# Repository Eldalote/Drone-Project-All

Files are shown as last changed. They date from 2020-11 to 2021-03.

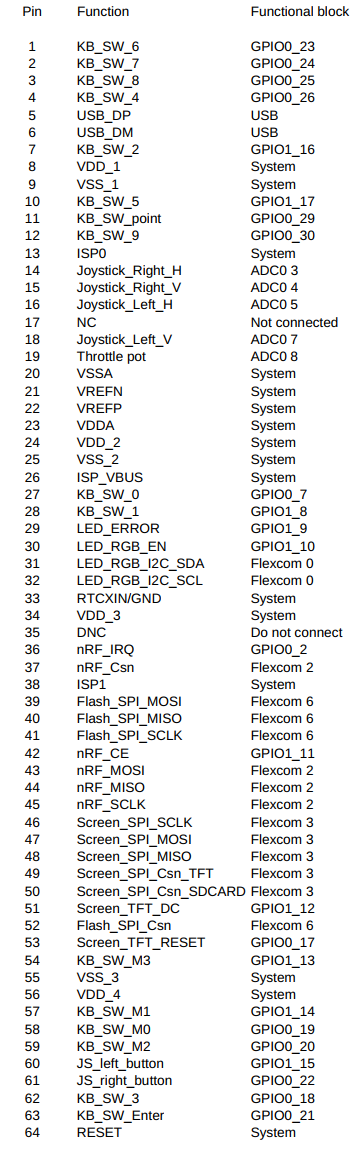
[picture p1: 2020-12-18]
PCBs/Remote/CenterBoard/Documentation/Pinning by pin.png

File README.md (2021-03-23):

# Drone-Project-All
Project repository for all the components of the Drone project

Project currently on hold. Unfortunately, with the current chip shortage, it would be very difficult to get the PCBs made and populated.
Several important chips are out of stock at all reputable distributors, and I fear that if I try to redesign with parts that I can get, that once I'm done redesigning, some other parts are out of stock.
For now, this project is on hold. I plan to return to it once the chip shortages have been at least somewhat resolved.

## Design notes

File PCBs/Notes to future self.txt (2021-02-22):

LPC51u68 is difficult to aquire.
LPC5114J256BD64 is slightly more expensive, but available, and more powerfull. Also, it's pin compatible. Use this?

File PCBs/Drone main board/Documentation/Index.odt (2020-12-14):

# Functional diagram and Index

# Power Distribution and Estimation

## 5v Power regulator

## 3v3 and 2v5 Power regulators

## 1v2 Power regulator

# USB and Flash Memory

# Sensors

# Engine Signals, LEDs, and GPIO

## GPIOs

# FPGA Pin Listing

# FPGA Bank 1, 2, and 3

# FPGA Bank 4, 5, and 6

# FPGA Bank 7, 8, clocks, and Configuration

# FPGA Power

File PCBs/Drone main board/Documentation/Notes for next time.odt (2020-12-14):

Standardize sheet IO. Use short (2 pieces long) wires, with the wire names to the side. Not long wires with names on it. Use same orientation on each sheet!

Order the pins of the FPGA banks better. Yes, sanity is important, easy searching for pins is too.

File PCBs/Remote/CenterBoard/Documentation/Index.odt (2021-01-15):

# Functional diagram and index

# LPC51U68, USB, and Flash

# Power

# Radio

# LEDs and Screen

# Joystick and Throttle

# Keyboard Connector and Schmitt triggers

# LPC51U68 Pinning list

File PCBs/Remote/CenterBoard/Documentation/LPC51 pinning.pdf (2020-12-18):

Sheet1

Page 1

Pin | Function | Functional block
1 | KB_SW_6 | GPIO0_23
2 | KB_SW_7 | GPIO0_24
3 | KB_SW_8 | GPIO0_25
4 | KB_SW_4 | GPIO0_26
5 | USB_DP | USB
6 | USB_DM | USB
7 | KB_SW_2 | GPIO1_16
8 | VDD_1 | System
9 | VSS_1 | System
10 | KB_SW_5 | GPIO1_17
11 | KB_SW_point | GPIO0_29
12 | KB_SW_9 | GPIO0_30
13 | ISP0 | System
14 | Joystick_Right_H | ADC0 3
15 | Joystick_Right_V | ADC0 4
16 | Joystick_Left_H | ADC0 5
17 | NC | Not connected
18 | Joystick_Left_V | ADC0 7
19 | Throttle pot | ADC0 8
20 | VSSA | System
21 | VREFN | System
22 | VREFP | System
23 | VDDA | System
24 | VDD_2 | System
25 | VSS_2 | System
26 | ISP_VBUS | System
27 | KB_SW_0 | GPIO0_7
28 | KB_SW_1 | GPIO1_8
29 | LED_ERROR | GPIO1_9
30 | LED_RGB_EN | GPIO1_10
31 | LED_RGB_I2C_SDA | Flexcom 0
32 | LED_RGB_I2C_SCL | Flexcom 0
33 | RTCXIN/GND | System
34 | VDD_3 | System
35 | DNC | Do not connect
36 | nRF_IRQ | GPIO0_2
37 | nRF_Csn | Flexcom 2
38 | ISP1 | System
39 | Flash_SPI_MOSI | Flexcom 6
40 | Flash_SPI_MISO | Flexcom 6
41 | Flash_SPI_SCLK | Flexcom 6
42 | nRF_CE | GPIO1_11
43 | nRF_MOSI | Flexcom 2
44 | nRF_MISO | Flexcom 2
45 | nRF_SCLK | Flexcom 2
46 | Screen_SPI_SCLK | Flexcom 3
47 | Screen_SPI_MOSI | Flexcom 3
48 | Screen_SPI_MISO | Flexcom 3
49 | Screen_SPI_Csn_TFT | Flexcom 3

### 50 Screen_SPI_Csn_SDCARD Flexcom 3

51 | Screen_TFT_DC | GPIO1_12
52 | Flash_SPI_Csn | Flexcom 6
53 | Screen_TFT_RESET | GPIO0_17
54 | KB_SW_M3 | GPIO1_13
55 | VSS_3 | System
56 | VDD_4 | System
57 | KB_SW_M1 | GPIO1_14
58 | KB_SW_M0 | GPIO0_19
59 | KB_SW_M2 | GPIO0_20
60 | JS_left_button | GPIO1_15
61 | JS_right_button | GPIO0_22
62 | KB_SW_3 | GPIO0_18
63 | KB_SW_Enter | GPIO0_21
64 | RESET | System

Sheet1

Page 2

Function | Functional block | Pin
USB_DP | USB | 5
USB_DM | USB | 6
nRF_SCLK | Flexcom 2 | 45
nRF_Csn | Flexcom 2 | 37
nRF_MOSI | Flexcom 2 | 43
nRF_MISO | Flexcom 2 | 44
nRF_IRQ | GPIO0_2 | 36
nRF_CE | GPIO1_11 | 42
Screen_SPI_SCLK | Flexcom 3 | 46
Screen_SPI_MOSI | Flexcom 3 | 47
Screen_SPI_MISO | Flexcom 3 | 48
Screen_SPI_Csn_TFT | Flexcom 3 | 49
Screen_SPI_Csn_SDCARD | Flexcom 3 | 50
Screen_TFT_DC | GPIO1_12 | 51
Screen_TFT_RESET | GPIO0_17 | 53
Flash_SPI_SCLK | Flexcom 6 | 41
Flash_SPI_Csn | Flexcom 6 | 52
Flash_SPI_MOSI | Flexcom 6 | 39
Flash_SPI_MISO | Flexcom 6 | 40
LED_RGB_I2C_SDA | Flexcom 0 | 31
LED_RGB_I2C_SCL | Flexcom 0 | 32
LED_RGB_EN | GPIO1_10 | 30
LED_ERROR | GPIO1_9 | 29
Throttle pot | ADC0 8 | 19
Joystick_Left_V | ADC0 7 | 18
Joystick_Left_H | ADC0 5 | 16
JoyStick_left_button | GPIO1_15 | 62
Joystick_Right_V | ADC0 4 | 15
Joystick_Right_H | ADC0 3 | 14
JoyStick_right_button | GPIO0_22 | 63
KB_SW_0 | GPIO0_7 | 27
KB_SW_1 | GPIO1_8 | 28
KB_SW_2 | GPIO1_16 | 7
KB_SW_3 | GPIO0_18 | 58
KB_SW_4 | GPIO0_26 | 4
KB_SW_5 | GPIO1_17 | 10
KB_SW_6 | GPIO0_23 | 1
KB_SW_7 | GPIO0_24 | 2
KB_SW_8 | GPIO0_25 | 3
KB_SW_9 | GPIO0_30 | 12
KB_SW_point | GPIO0_29 | 11
KB_SW_Enter | GPIO0_21 | 61
KB_SW_M0 | GPIO0_19 | 59
KB_SW_M1 | GPIO1_14 | 57
KB_SW_M2 | GPIO0_20 | 60
KB_SW_M3 | GPIO1_13 | 54

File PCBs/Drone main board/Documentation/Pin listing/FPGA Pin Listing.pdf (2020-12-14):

Sheet1

Page 1

Functional Block | Pin Name | Pin Number Bank
GPIO 1 | GPIO 0 | V21 | 5
| GPIO 1 | V22 | 5
| GPIO 2 | U21 | 5
| GPIO 3 | U22 | 5
| GPIO 4 | D22 | 6
| GPIO 5 | D21 | 6
| GPIO 6 | E22 | 6
| GPIO 7 | E21 | 6
| GPIO 8 | F22 | 6
| GPIO 9 | F21 | 6
| GPIO 10 | H22 | 6
| GPIO 11 | H21 | 6
| GPIO 12 | J22 | 6
| GPIO 13 | J21 | 6
| GPIO 14 | M21 | 5
| GPIO 15 | M22 | 5
GPIO 2 | GPIO 0 | B6 | 8
| GPIO 1 | A6 | 8
| GPIO 2 | B7 | 8/CONF
| GPIO 3 | A7 | 8
| GPIO 4 | B18 | 7
| GPIO 5 | A18 | 7
| GPIO 6 | B17 | 7
| GPIO 7 | A17 | 7
| GPIO 8 | B16 | 7
| GPIO 9 | A16 | 7
| GPIO 10 | B15 | 7
| GPIO 11 | A15 | 7
| GPIO 12 | B14 | 7
| GPIO 13 | A14 | 7
| GPIO 14 | B13 | 7
| GPIO 15 | A13 | 7
5volt GPIO | 5vGPIO-0 | AB20 | 4
| 5vGPIO-1 | AA20 | 4
| 5vGPIO-2 | AB19 | 4
| 5vGPIO-3 | AA19 | 4

Page 2

Functional Block | Pin Name | Pin Number Bank
DPS422 | Csn | AA22 | 5
| MOSI | AA21 | 5
| SCLK | Y22 | 5
| MISO | Y21 | 5
BNO055 | SDA | E1 | 1
| SCL | D2 | 1
| INT | B1 | 1
| NRESET | B2 | 1
ICM-20602 | SCLK | AB8 | 3
| MOSI | AA8 | 3
| MISO | AB9 | 3
| Csn | AA9 | 3
| INT | AA10 | 3
| FSYNC | AB10 | 3
ADC | Csn | AB18 | 4
| MOSI | AA18 | 4
| MISO | AB16 | 4
| SCLK | AA16 | 4
Radio | CE | C22 | 6
| Csn | C21 | 6
| SCLK | B22 | 6
| MOSI | A20 | 7
| MISO | A19 | 7
| IRQ | B20 | 7
ESC | ESC1 | N2 | 2
| ESC2 | N1 | 2
| ESC3 | M2 | 2
| ESC4 | M1 | 2
| ESC-TX | P1 | 2

Page 3

Functional Block | Pin Name | Pin Number Bank
50 MHz Clock | Clock | T1 | Clocks
FTDI | ADBUS4 | AB3 | 3
| ADBUS5 | AA3 | 3
| ADBUS6 | AB4 | 3
| ADBUS7 | AA4 | 3
ACBUS0 | AB5 | 3
ACBUS1 | AA5 | 3
ACBUS2 | AB7 | 3
ACBUS3 | AA7 | 3
ACBUS4 | AA13 | 4
ACBUS5 | AB13 | 4
ACBUS6 | AA14 | 4
ACBUS7 | AB14 | 4
ACBUS8 | AA15 | 4
ACBUS9 | AB15 | 4
User Flash | CLK | F1 | 1
| Csn | J1 | 1
| IO0 | F2 | 1
| IO1 | J2 | 1
| IO2 | H1 | 1
| IO3 | H2 | 1
User LED | LED0 | Y1 | 2
| LED1 | Y2 | 2
| LED2 | W1 | 2
| LED3 | W2 | 2
| LED4 | V1 | 2
| LED5 | V2 | 2
| LED6 | U1 | 2
| LED7 | U2 | 2

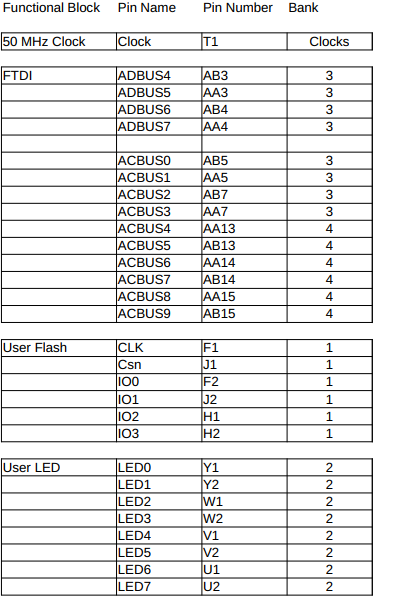
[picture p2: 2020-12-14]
PCBs/Drone main board/Documentation/Pin listing/System and user interface.png

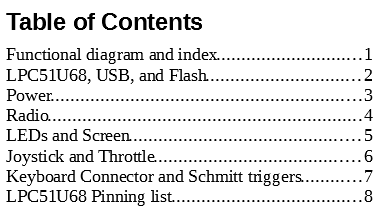
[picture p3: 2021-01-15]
PCBs/Remote/CenterBoard/Documentation/Index 1.png

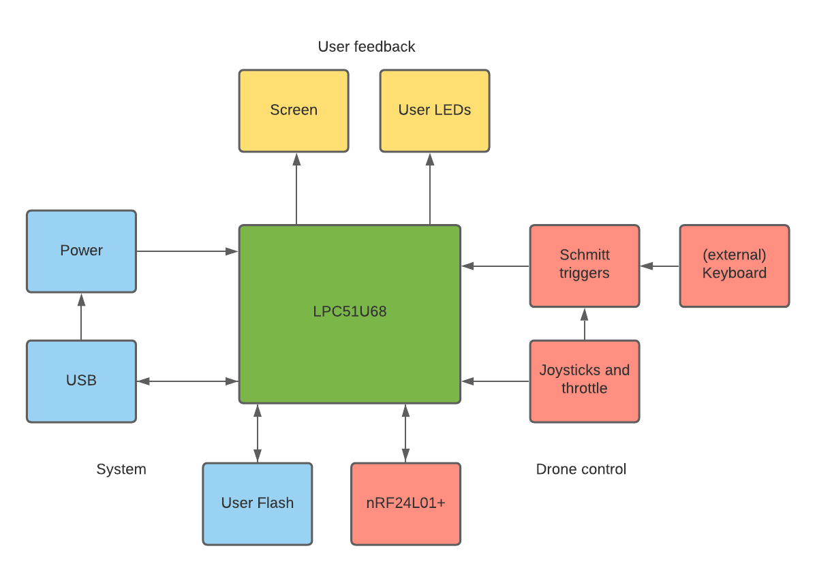
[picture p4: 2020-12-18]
PCBs/Remote/CenterBoard/Documentation/Remote functional diagram.png

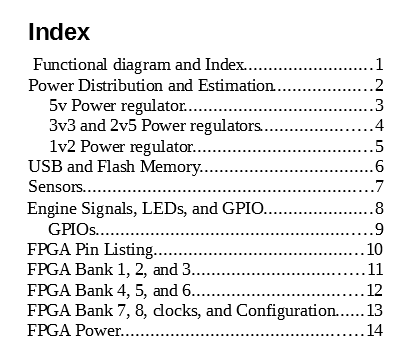
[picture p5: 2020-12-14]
PCBs/Drone main board/Documentation/Index.png

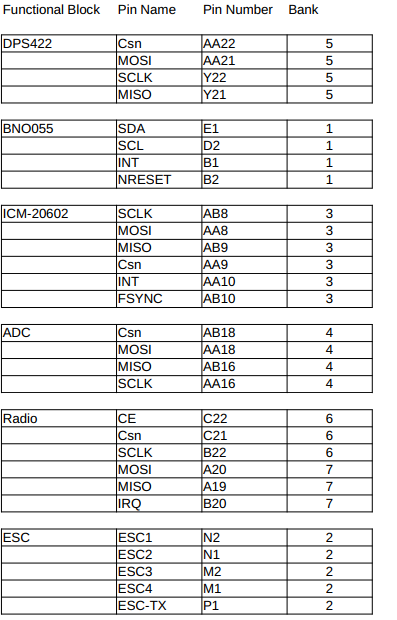
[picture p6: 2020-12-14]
PCBs/Drone main board/Documentation/Pin listing/Sensors and drone control.png

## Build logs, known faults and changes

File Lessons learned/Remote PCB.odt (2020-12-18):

# Lessons learned; Remote - schematic and PCB

Note: This Schematic and PCB were made after the Drone with FPGA board. I think most lessons were learned on the Drone board, and applied here, but some new lessons are to be had here too.

### Lessons about the schematic

Have a list of components you would often use.

Having a list of resistors, LEDs, capacitors, etc. that you have used makes further design a lot easier.
KiCad does have a component list used in the project itself, but that doesn’t tell you about the resistor you already selected in the other project.

For now I’m using a google sheet file. For all the regular components I have a neatly sorted table with values, sizes, tolerances, material, and distributor codes/links. This way, if I need a 0603 1kOhm resistor, I just look at my list, see that I have a 1% tolerance one selected already, and just copy the information into the schematic. No redoing the component searching every time.

In the future, after the drone project is fully done, I’d like to create my own program to manage this for me. With a nice database, API access to the distributors, and a nice UI. There are probably many programs available on the internet that can do that already, maybe even free ones. But I’d ideally like to learn to use python, and work with databases, so this seems like a nice combination of “I want to have this” and “I want to learn to do this”.

Count your CPU pins carefully, and double check.

A CPU has only a set number of pins, count how many you want to use, and double check. I counted, didn’t double check, and must have missed some, because when it came time to hook up the last 12 GPIO pins, I only had 7 free GPIO pins left. Oops.

I was able to redesign some parts (PWM for the screen backlight not through the CPU, but directly with timing circuit and an I2C LED driver instead of using CPU PWM pins (this allowed me to add even more LEDs too!)). Next time double check, so you don’t have to do a last minute redesign.

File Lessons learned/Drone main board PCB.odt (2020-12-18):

# Lessons learned; Drone main board with FPGA - schematic and PCB

Note: This is the first (somewhat) complex PCB I’ve ever made. Before this I had only ever made a couple of very simple (and not very good) 2-layer PCBs. About a year before I made this I made a couple of very simple PCBs for the drone project, mostly tying a bunch of development boards together. They worked, but didn’t look great. The last time before that was many years ago, during the short work stint I did before my burnout, and a couple of VERY simple ones during school and internships.
This was the first time I had ever attempted a 4 layer board, or a multi-page schematic.

### Lessons about the project as a whole

During most of the work I did on this project I was working ahead of my own abilities. I had never made a 4 layer PCB before, never made a multi-page schematic before, never did a BGA chip before, never did a board this densely packed before, never did multiple power stages before, etc, etc.

While it was daunting from time to time, I also enjoyed it. Working this way allowed me to learn a great deal of new skills, and I constantly had to challenge myself to learn, to find out, and to solve problems I’d never had to solve before.

While it did take quite a while to finish, and it was a lot of work, it was never too difficult. In the end, while it was hard work, it wasn’t nearly as daunting as I felt in the beginning.

I just love a challenge.

### Lessons about multi-page schematics

Don’t make sheets too busy. If you use multiple sheets, use multiple sheets!

While you might lose some readability if you spread a system over multiple sheets, I feel that you lose even more readability if you cram too many things on a single sheet, and you end up with a big mess.

Bad example: “USB and Flash Memory” or “Sensors”. Better example: “Power distribution and estimation” or “Engine signals, LEDs, and GPIO” (though the last one could just have been separate sheets instead of having a sub sheet.)

Use a consistent page layout.

Speaks for itself. Have a consistent layout throughout the whole schematic, that makes it more readable.

Bad example: This schematic. Better example: The remote-centerboard schematic.

Followup:

Have a consistent sheet IO layout and formatting.

Since global signals have to be by definition on multiple sheets, it is much more readable (and usable in design) if the sheet IO is always in the same place on the sheet, and always formatted the same way.

Proposed layout and formatting going forwards: Sheet IO is on the top left side of the page. Nothing to the left of it, or above it. Global label to the left, then a two-tick (100 mils) wire, and then the local net label extending to the right. This makes copying and using on other sheets much easier, plus it is easier to read when cross referencing.

Bad example: Almost every sheet in this project. Better example: The remote-centerboard schematic.

### Lessons about schematic design in general

Other peoples projects can be wrong. Always check the datasheets.

This isn’t really something NEW I learned, but it was reinforced.

FPGA datasheets are very, very long and complicated. It can be difficult to find the answers you seek in the several hundred pages, spread over almost 10 different documents. Because of this I went looking for some reference designs, to see how they did it. The official Intel development board has a public schematic, and while that is useful, it also uses a lot of very expensive Intel components, and components I don’t need in my design. I found a public design someone posted online, and used that as a loose guide on how to connect the FPGA. It did have several choices that I found questionable. It took me several hours of digging through the datasheets to come to the conclusion that I was right. The choices made in that design might work there, but it would not have worked in my design.

You can use other peoples designs for inspiration, but never blindly copy them. (Even aside from the legal questions of copying someone else’ design.)

Creating new schematic symbols or editing them is easy, and often worth it.

Not everything you want to use in your design will have a neat pre-made symbol in your CAD tool. Often you can find symbols for free on distributors sites, or sites like SnapEDA or Samacsys.

Even when you do find symbols, they might not always be laid-out in a way that you like. Luckily, most licenses from free symbols allow you to freely edit the symbols. This is relatively easy, and can improve the usability of the symbols greatly.

If you can’t find a symbol, just create it yourself. This too is easy (though a bit more work often).

Examples: Many symbols in the schematic are those I created myself, or edited for my own use. I can’t share the library, because while the license allows me to alter the downloaded symbols and use them in any way I like, I can’t distribute them, so that git repository is private.

Order pins the right way in edited/created symbols.

As an example, the Cyclone 10 LP symbol in the schematic does not have a nice pin ordering. The banks are well sorted, and the layout is decent, but the pins are not sorted.

Finding a usable symbol for the Cyclone was very hard. In the end I only found monolith symbols (all 484 pins on a single block) or the symbol provided by Intel itself (which was a OrCad symbol, which KiCad can’t handle.)

I spent quite a bit creating my own symbol from one of the downloaded ones. That was a bit sanity stripping. Sorting 484 pins into useful groupings, pins not having the correct length or spacing (the symbol I downloaded was made with 25 mils spacing, the standard KiCad spacing is 50 mils), and a couple of pins with incomplete names.

In hindsight I should have spend even more time and properly sorted the pins. During design later searching for the pins was a bit tedious. Properly sorting pins makes a nicer symbol, and improves later use, especially if you plan to use the symbol more than once.

Be consistent with value labeling.

(As far as I know) It is widely accepted practice to label resistor values with the “multiplier” replacing the period, like if you want to label 4.7k Ohm resistor, you call it 4k7. I’ve been using this consistently. However, do you do the same with capacitors and inductors? I’ve seen the internet be divided. I’ve tried both, and changed my mind on it several times. 1p5F is consistent with the way resistors are labeled, but it just doesn’t look right to me. 1.5pF looks much better to me, but then you have two different methods of labeling. I don’t know the “correct” answer, but I’ve chosen to stick with 1.5pF for now.

### Lessons about PCB layout.

A four layer board is less full than you think.

When you look at a fairly densely packed PCB with both top and bottom layers showing, it might look like there isn’t a square millimeter left for use, while there is still plenty of space. When you are dealing with relatively low frequency digital devices, especially on a four layer board with a ground and power layer between top and bottom, placing components opposite each other, or laying traces on top of each other is possible.

This might look impossibly busy, and you might need to just look at it with a single layer active, but it is doable. Using the 3D viewer also gives you a clear view of both sides and how full they are.

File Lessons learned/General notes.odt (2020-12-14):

These notes on lessons learned are for myself to keep track of do’s and don’ts I learned while doing the sub-projects in this larger project.

This isn’t going to list all the new things I learned, like “I learned how to code a I2C master in VHDL!” or the like.

It’s meant more for the likes of “I should have a unified way of naming signals, especially if they go cross instance” or “Don’t abbreviate signal names so much you no can longer understand what they are supposed to be.”

I decided to start keeping these notes while designing the Main drone PCB, Notes on sub-projects I did earlier might be added, from memory.

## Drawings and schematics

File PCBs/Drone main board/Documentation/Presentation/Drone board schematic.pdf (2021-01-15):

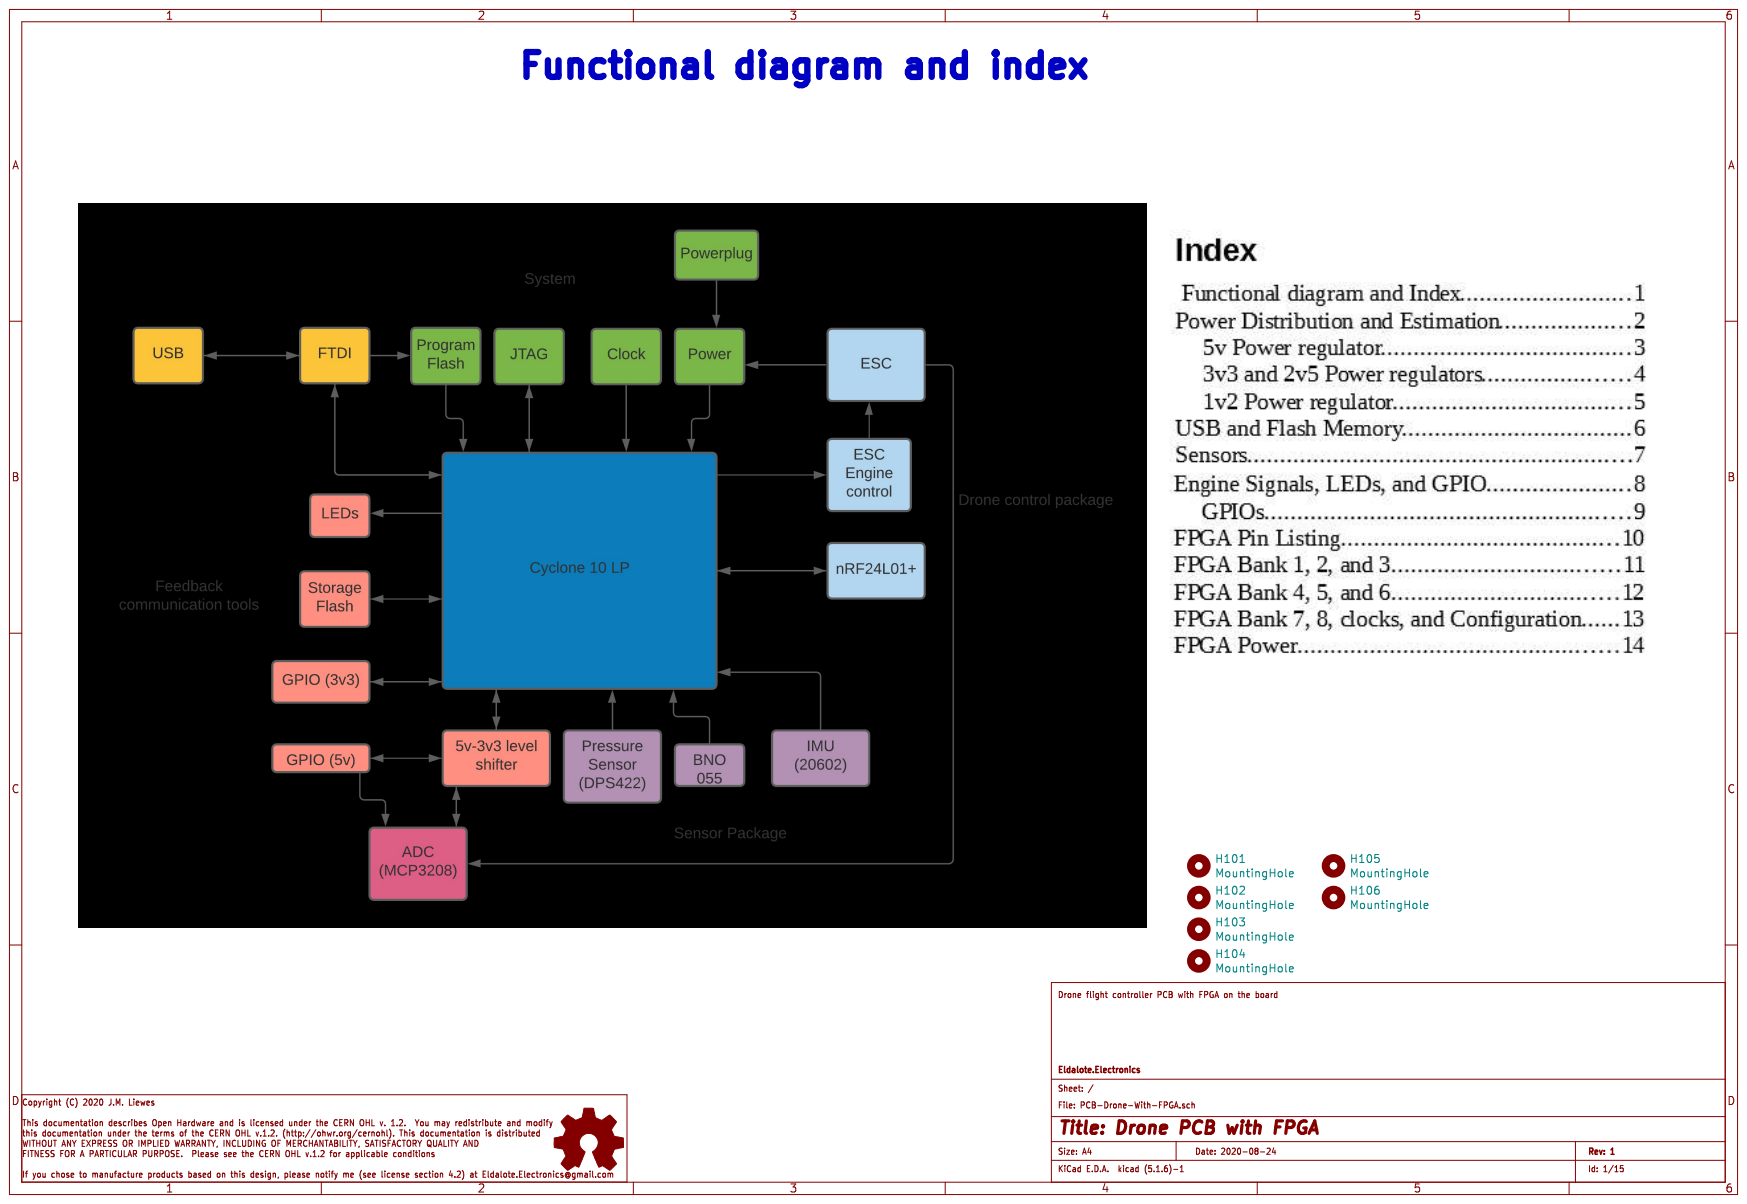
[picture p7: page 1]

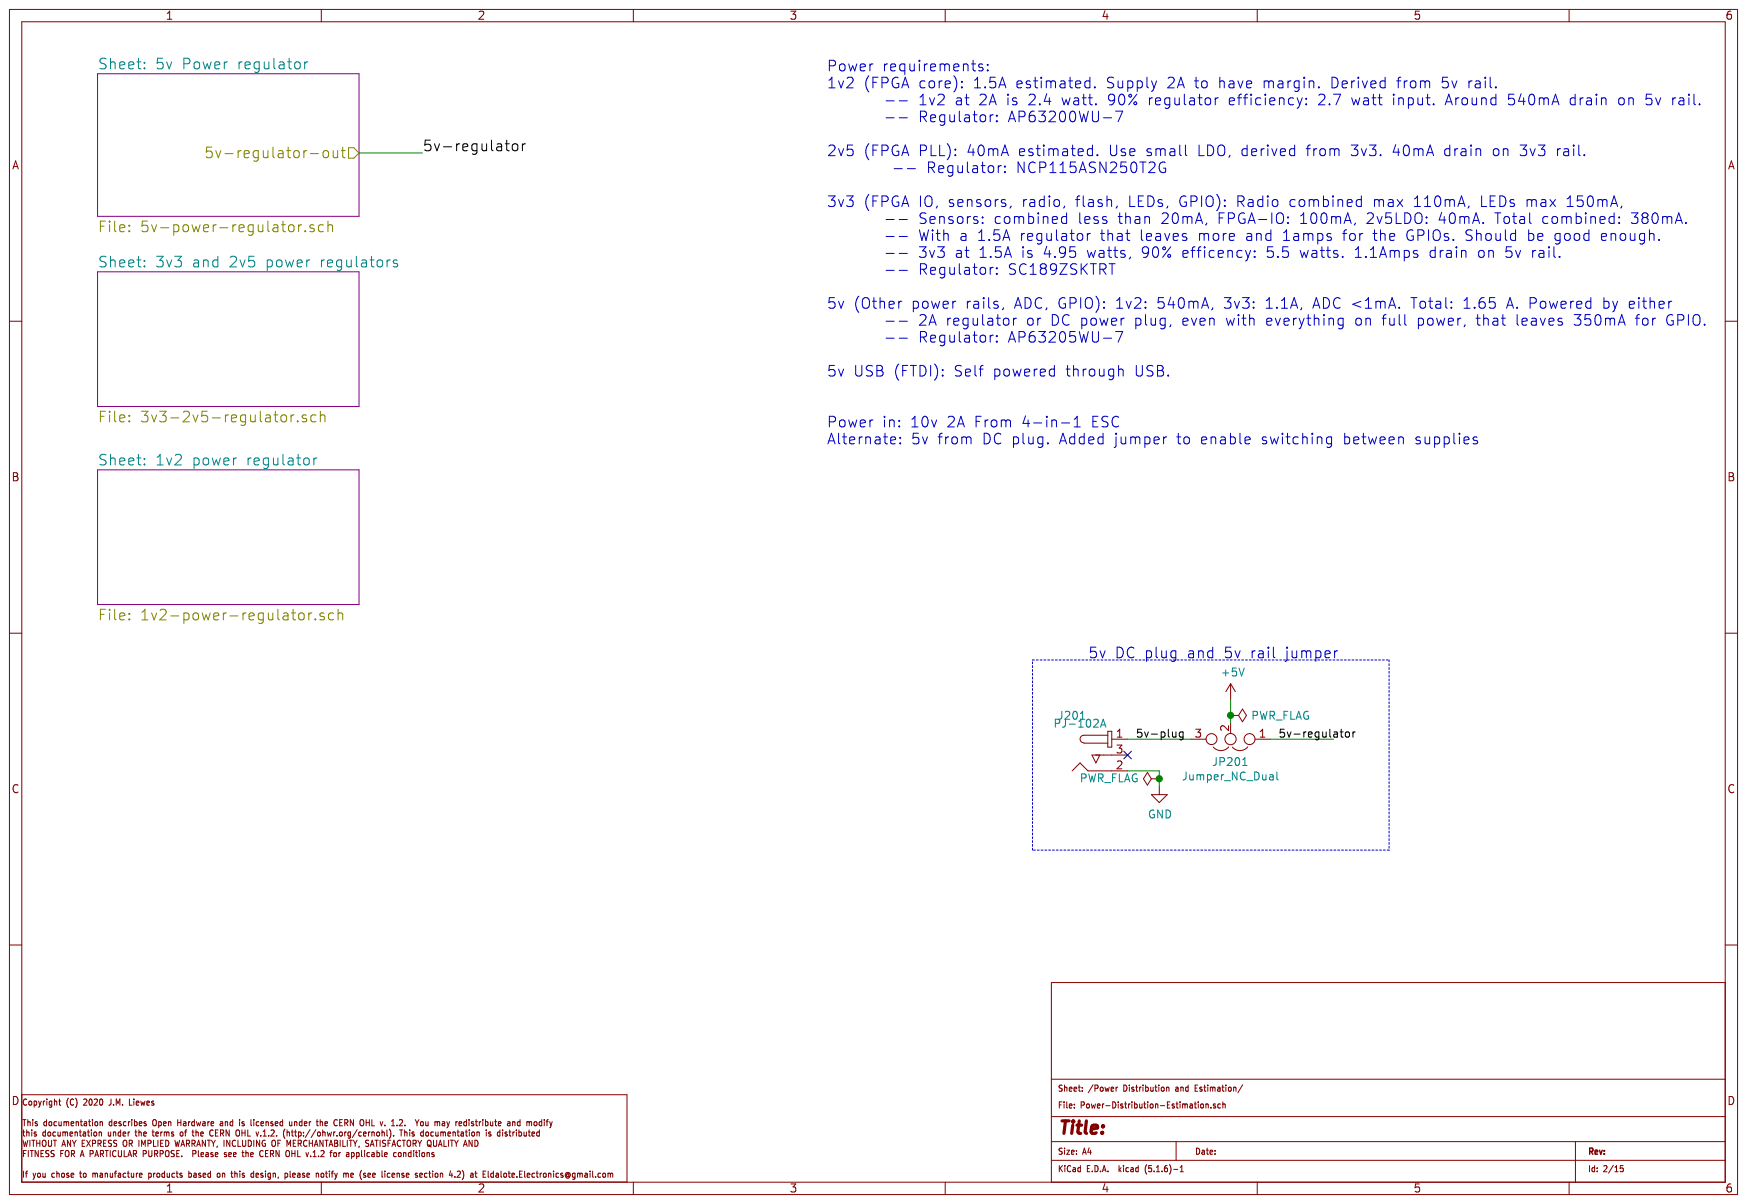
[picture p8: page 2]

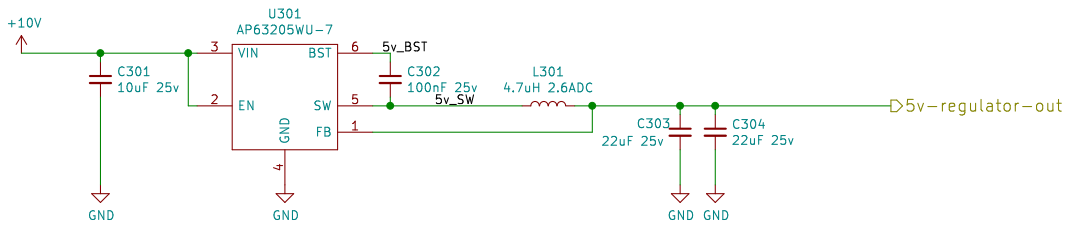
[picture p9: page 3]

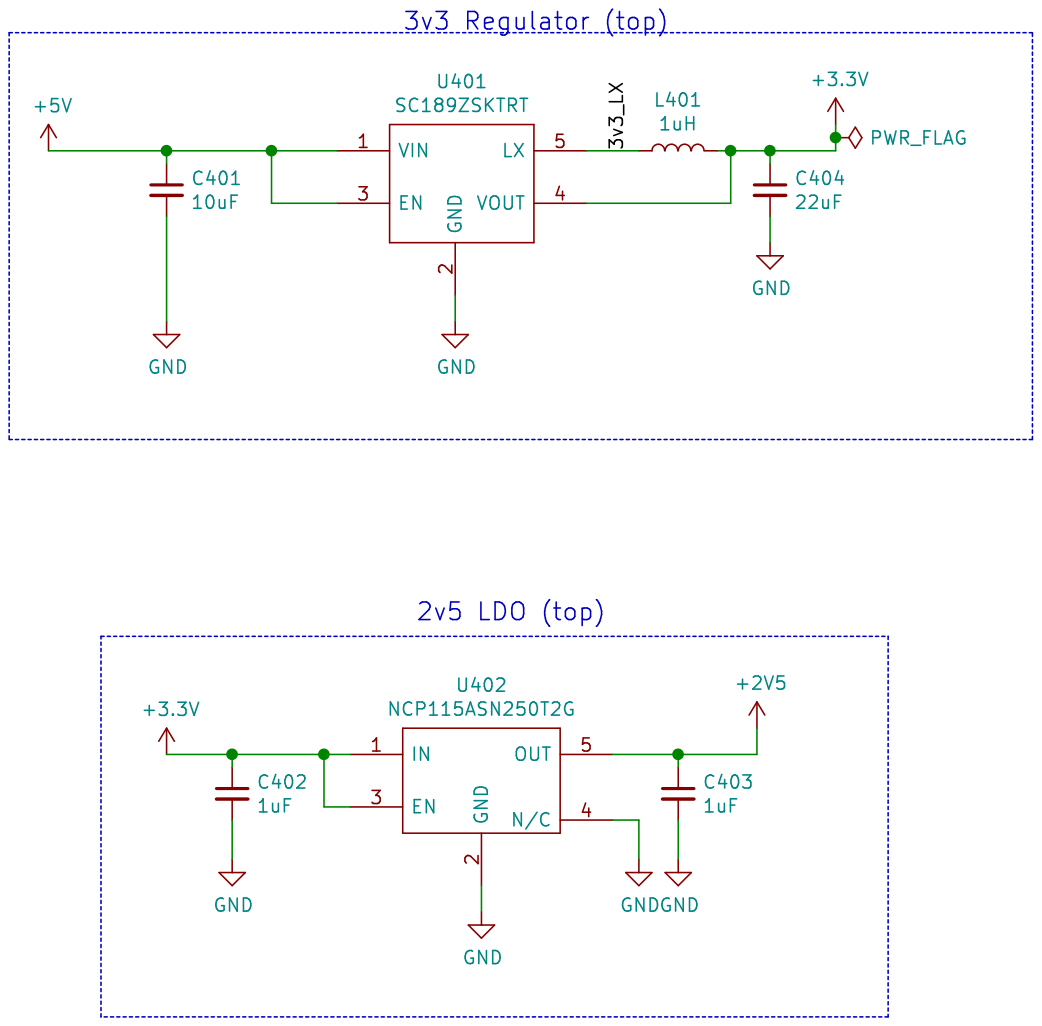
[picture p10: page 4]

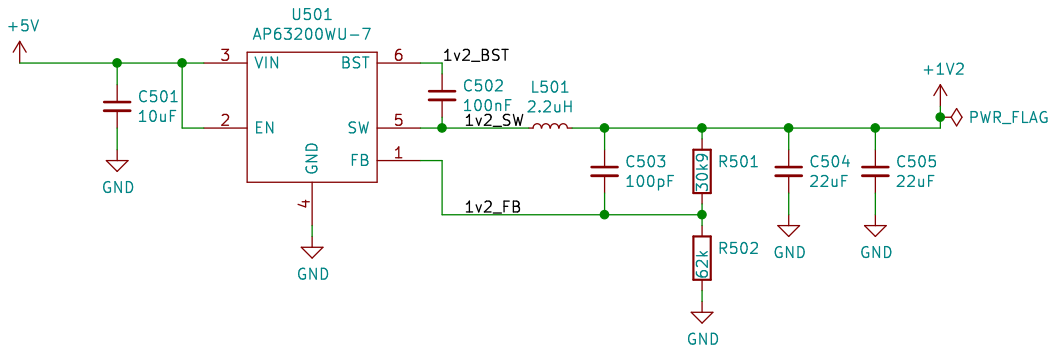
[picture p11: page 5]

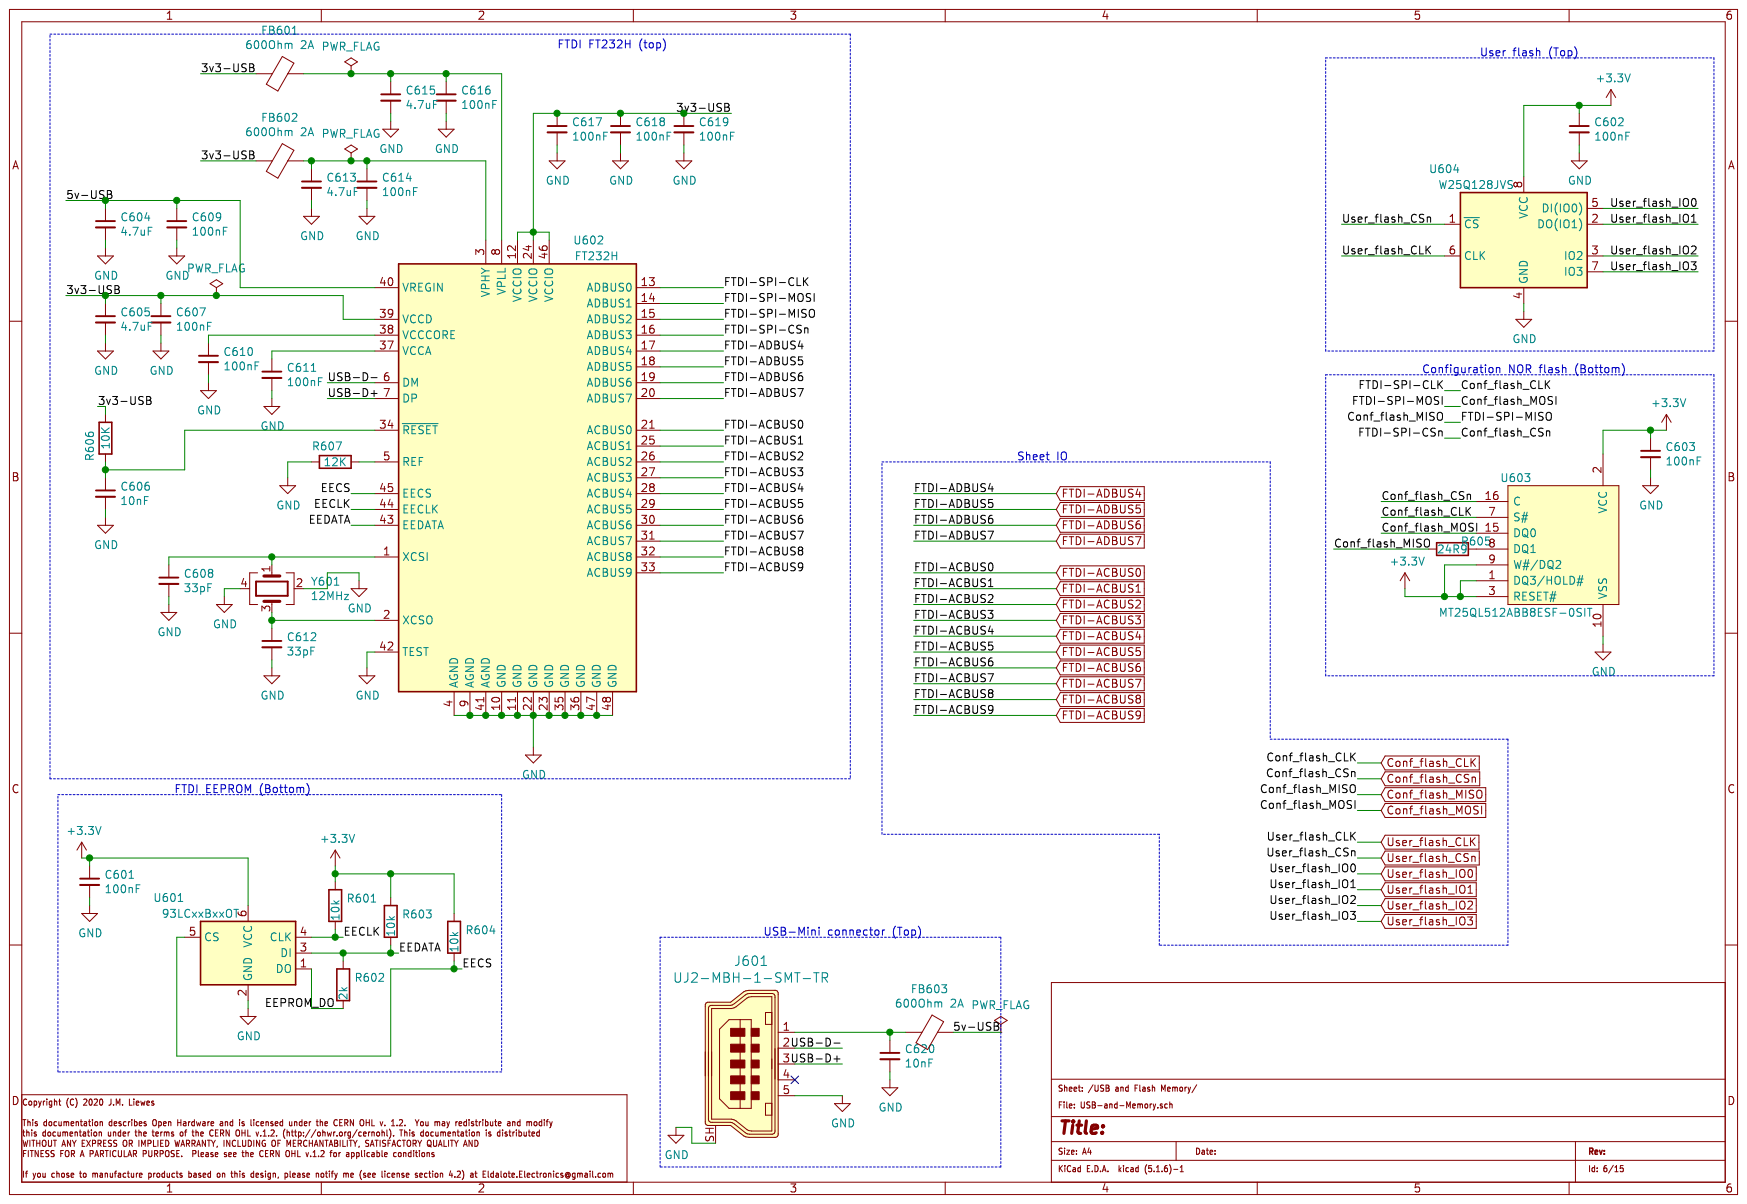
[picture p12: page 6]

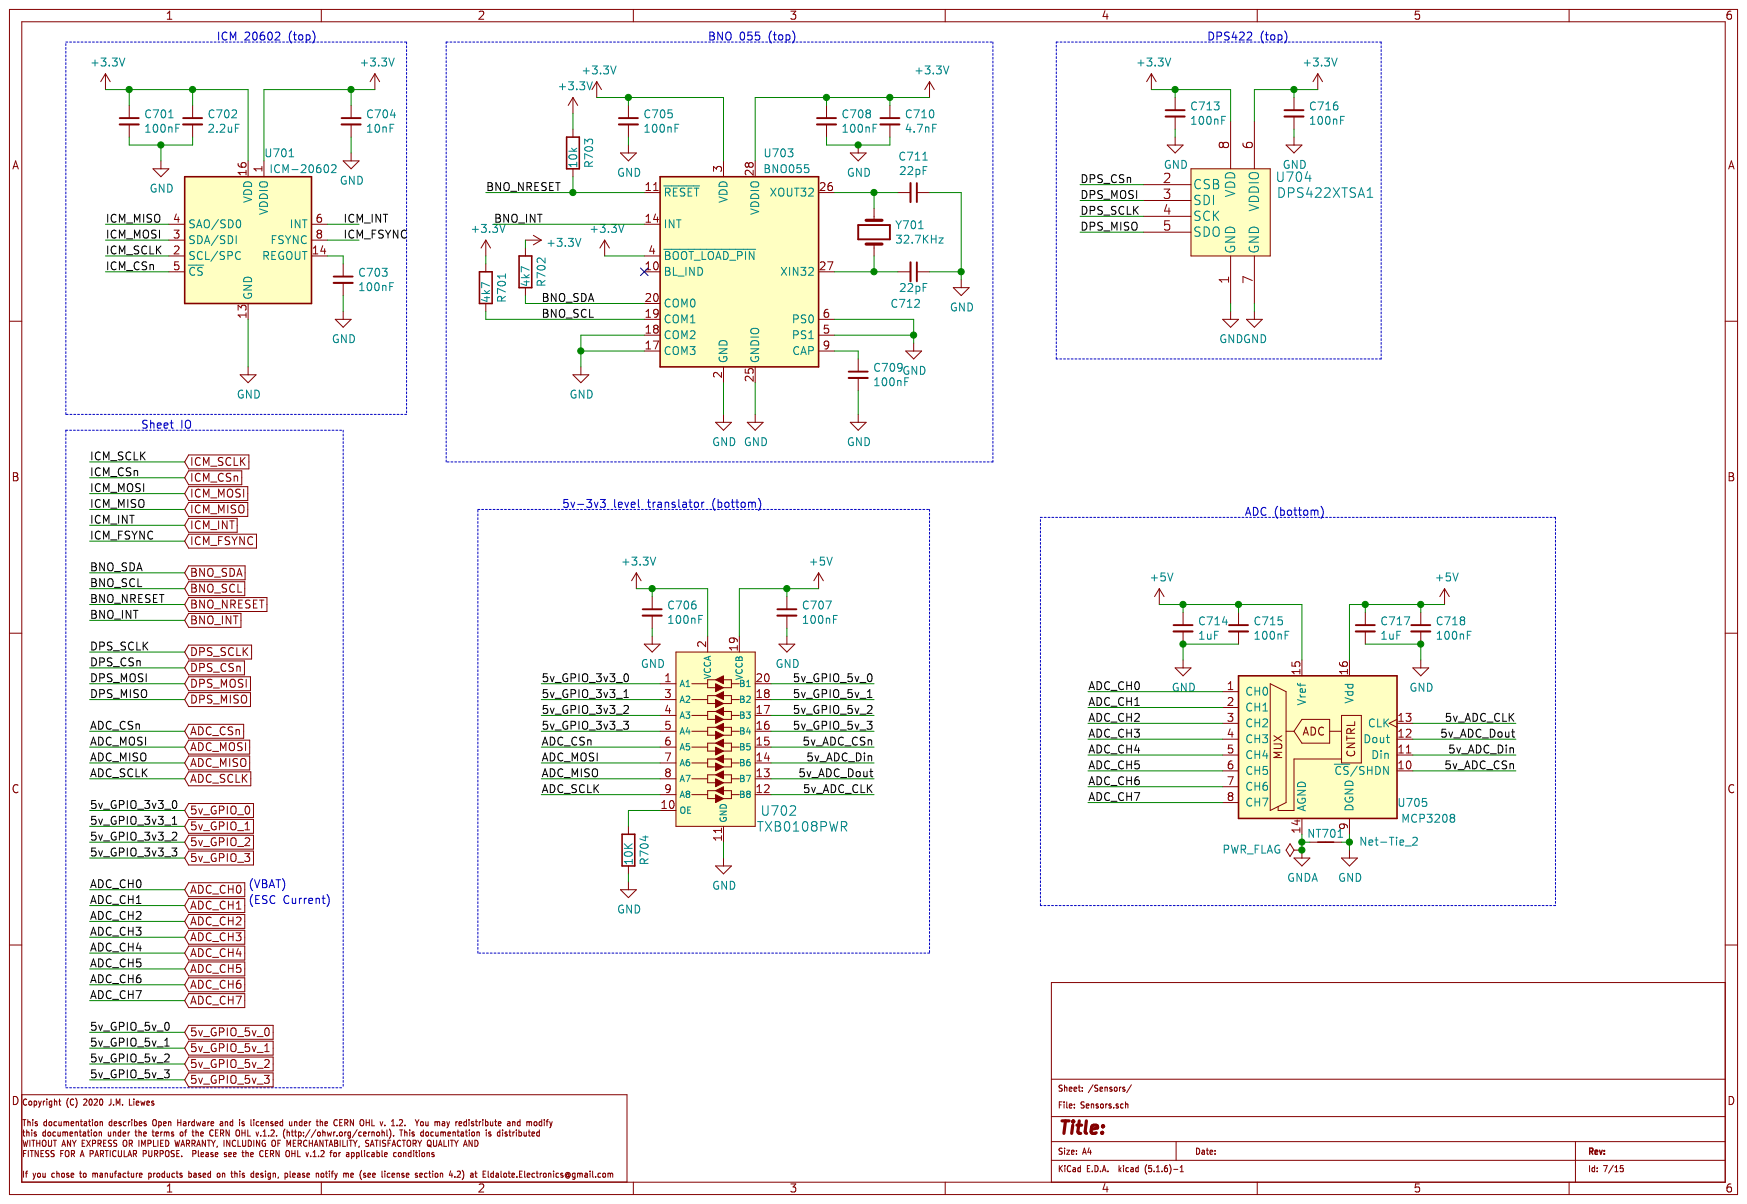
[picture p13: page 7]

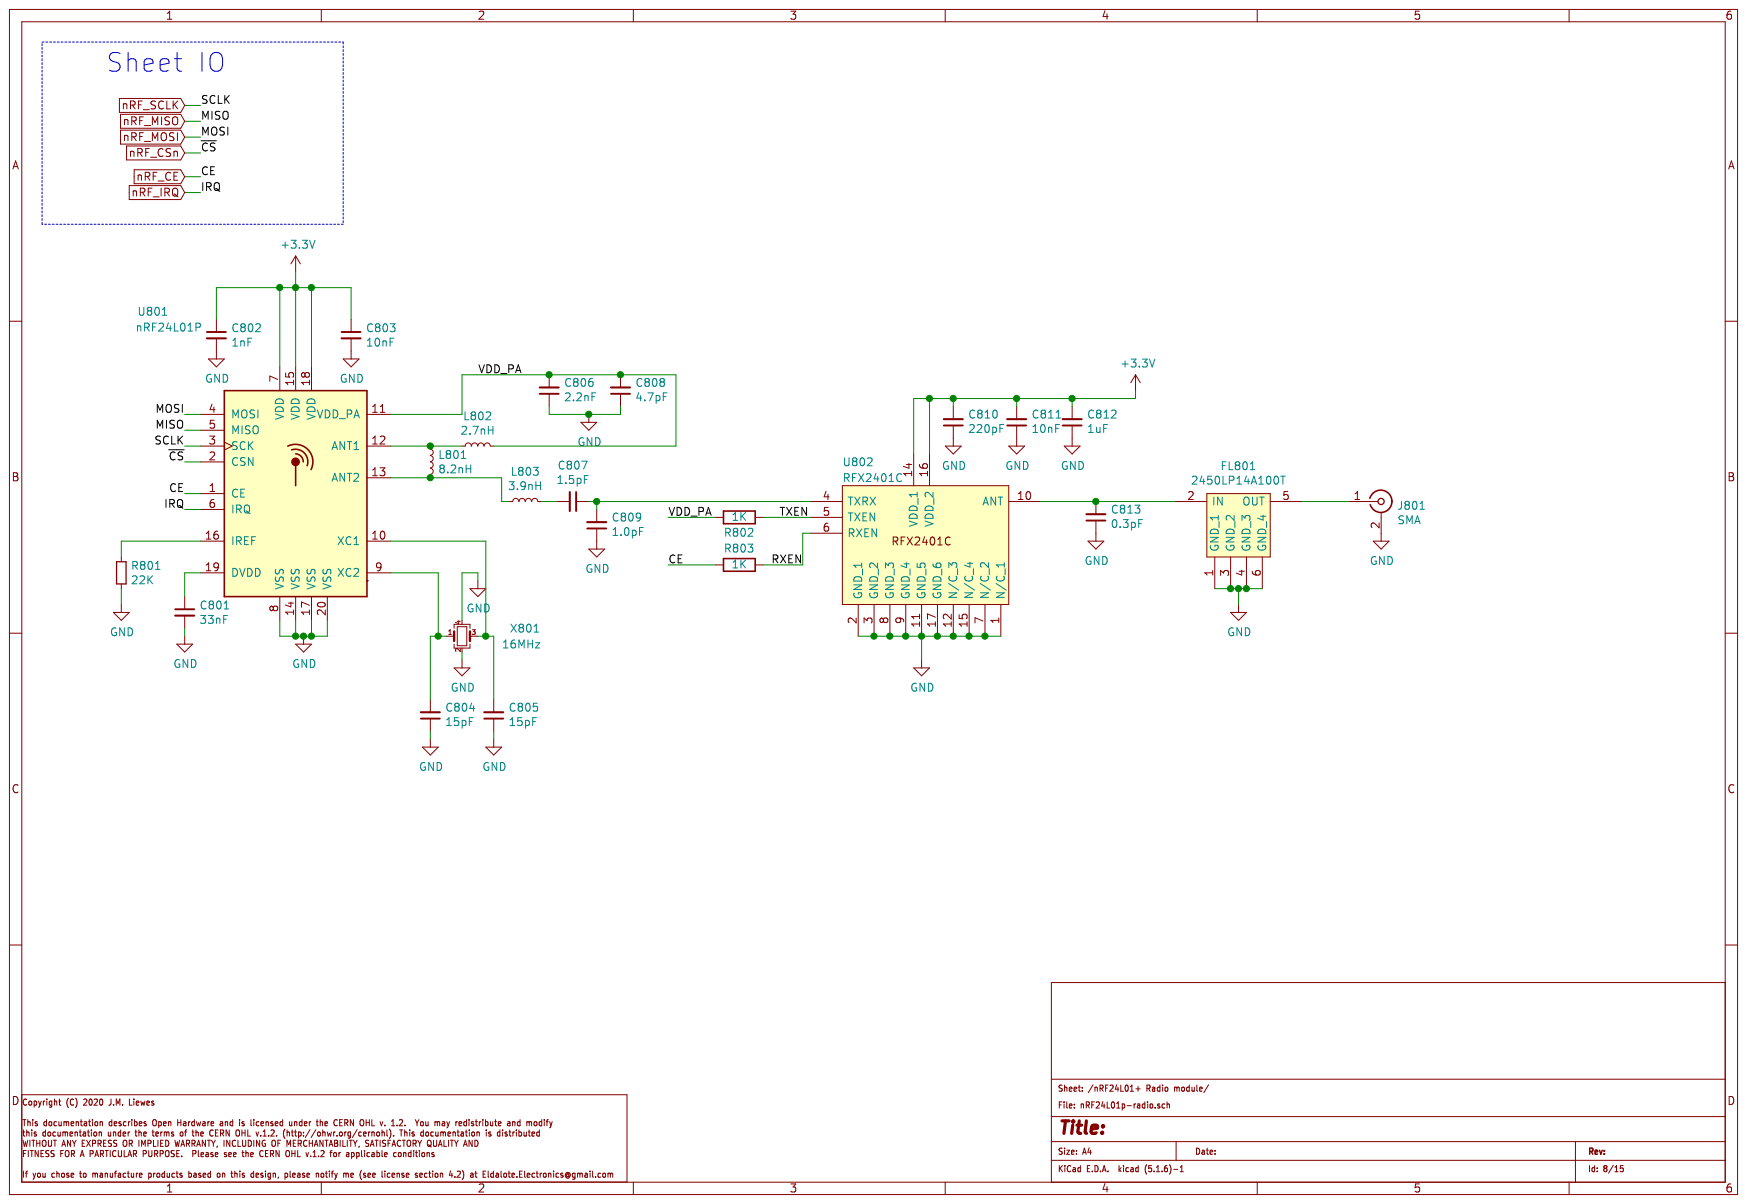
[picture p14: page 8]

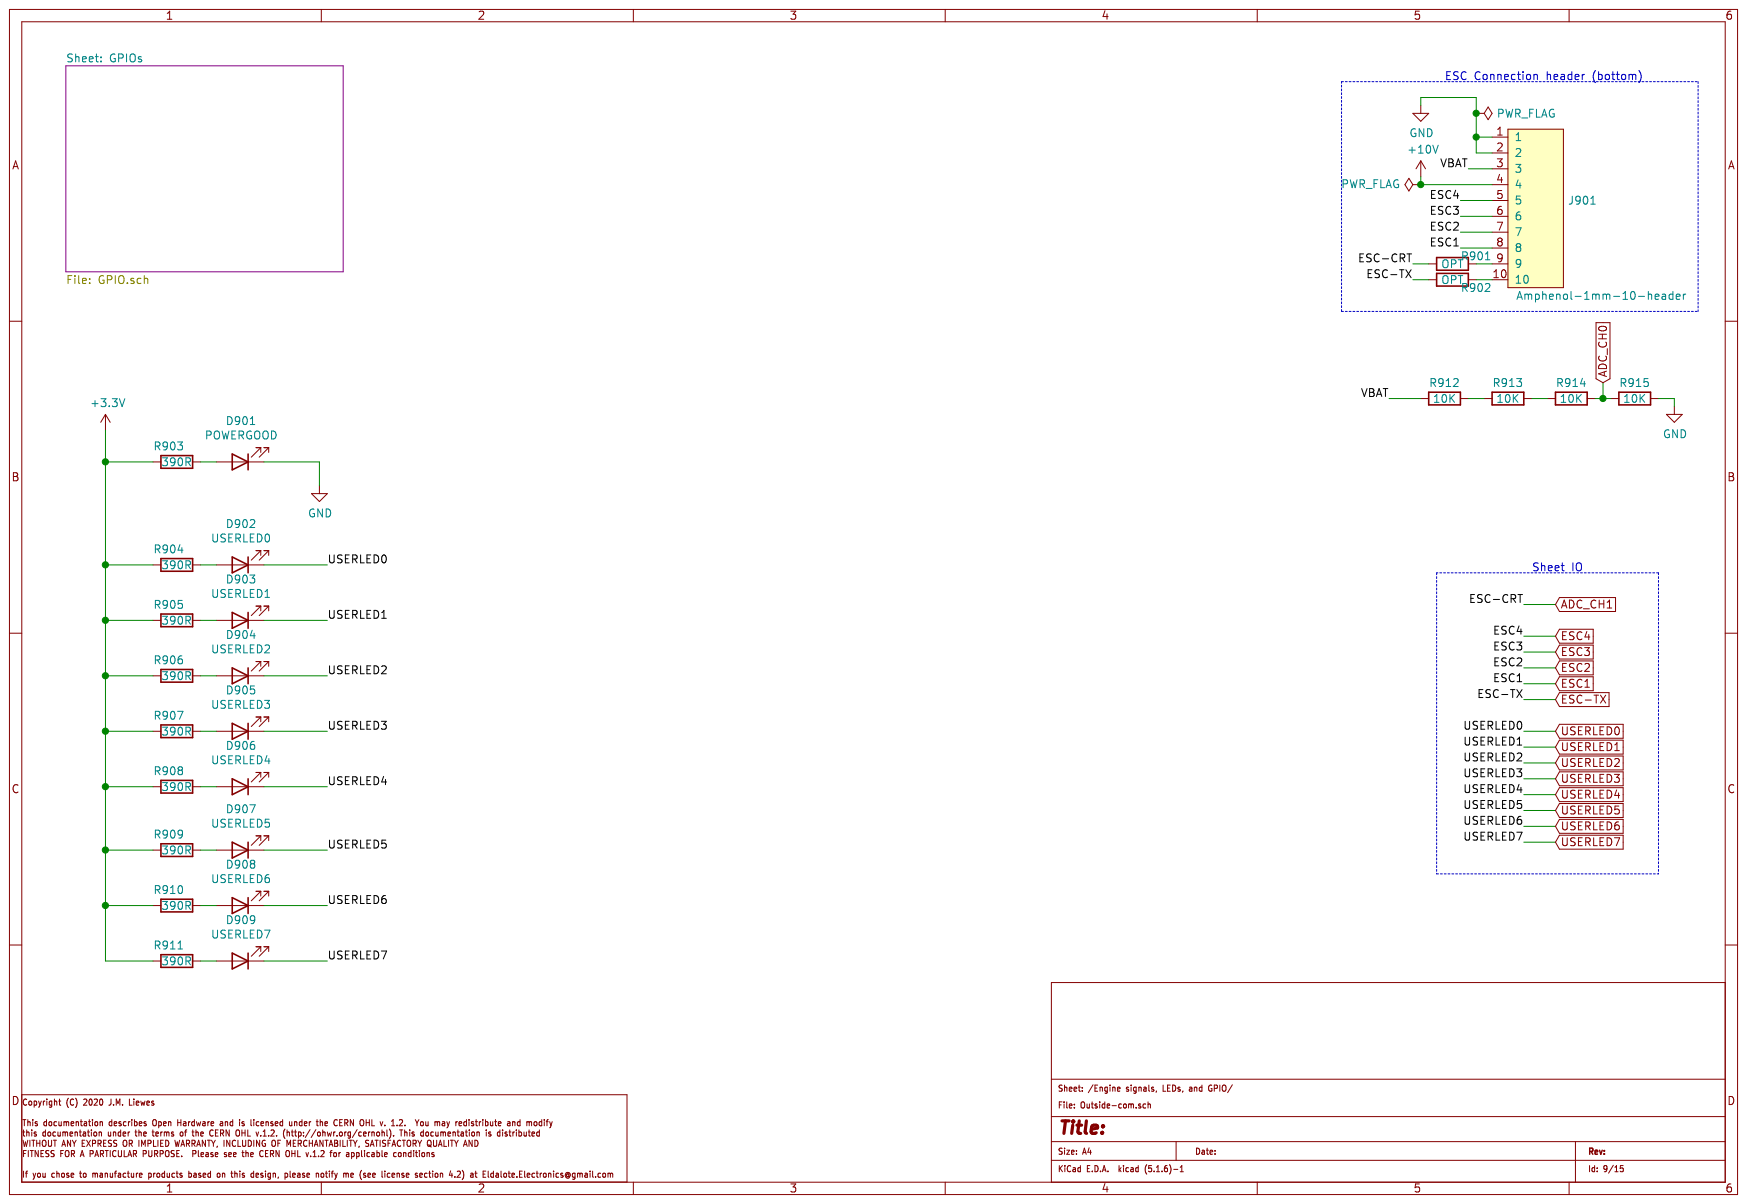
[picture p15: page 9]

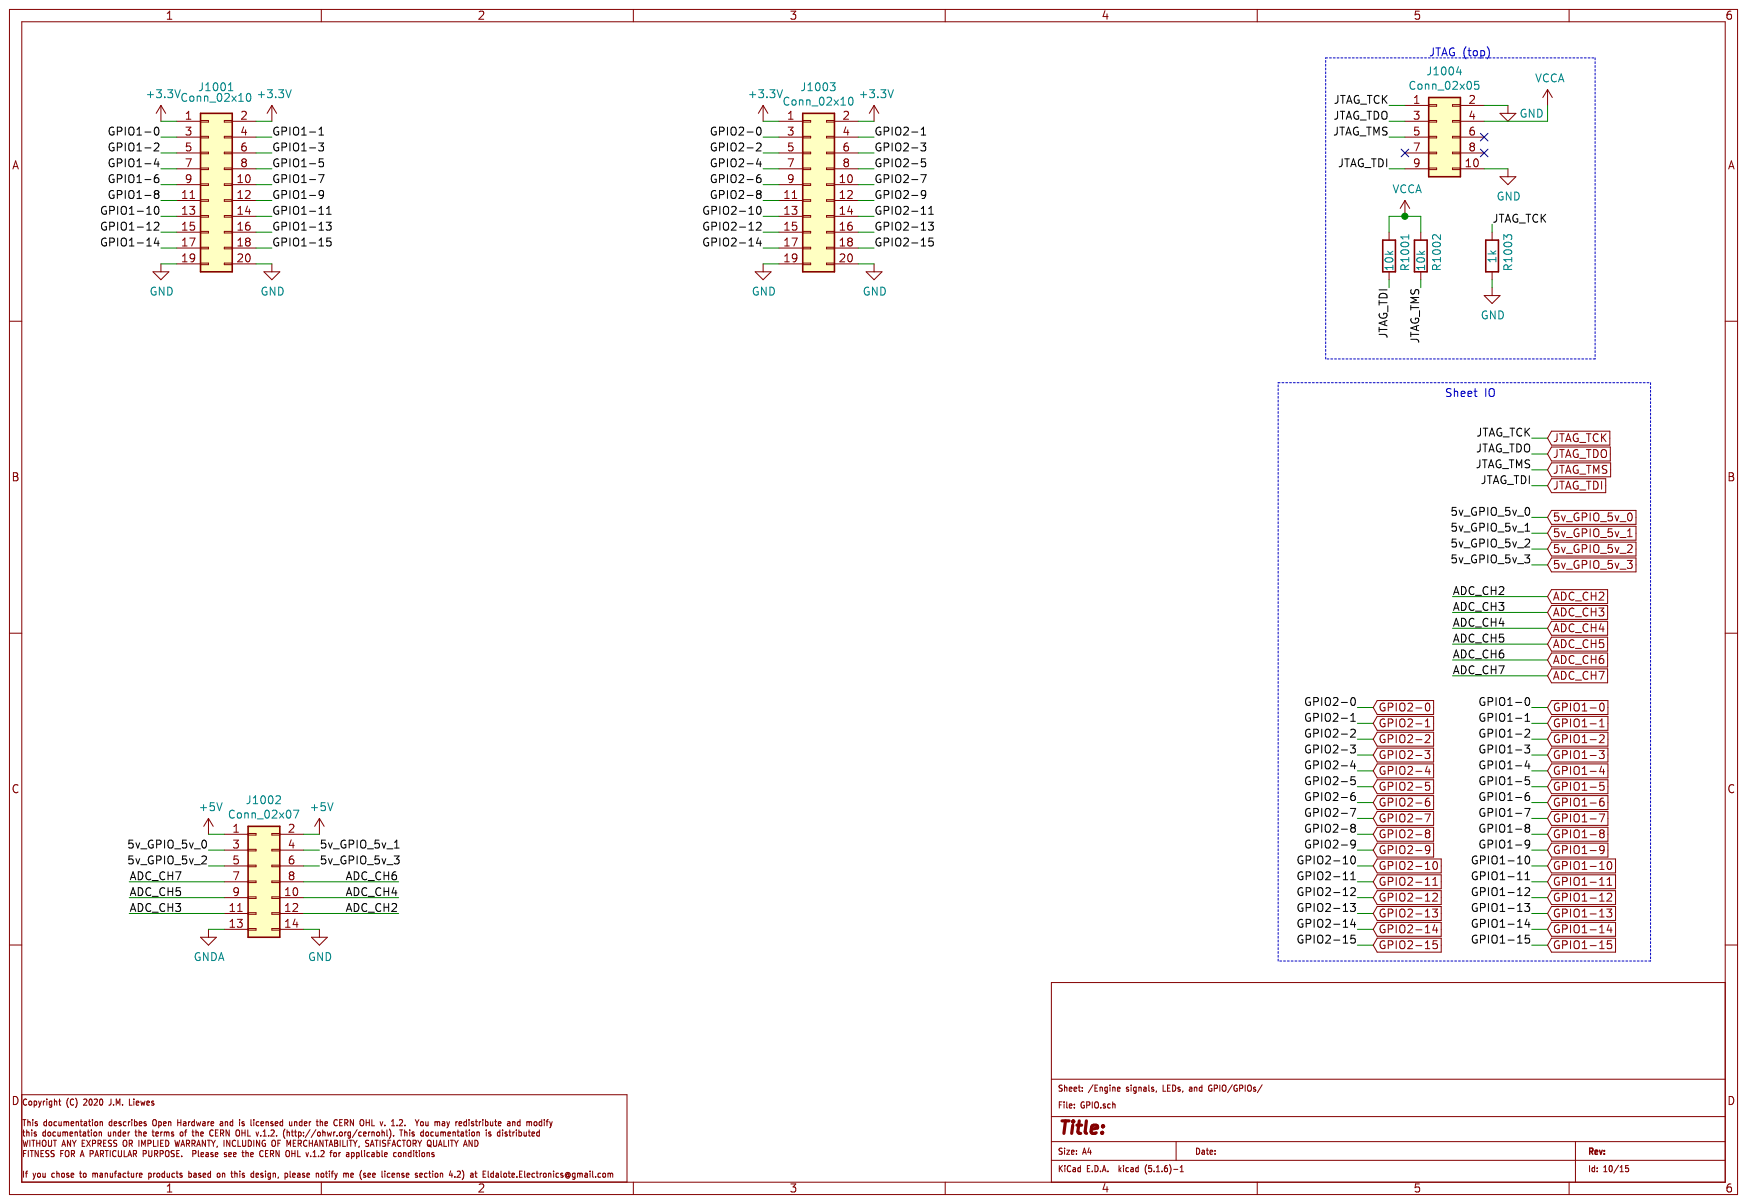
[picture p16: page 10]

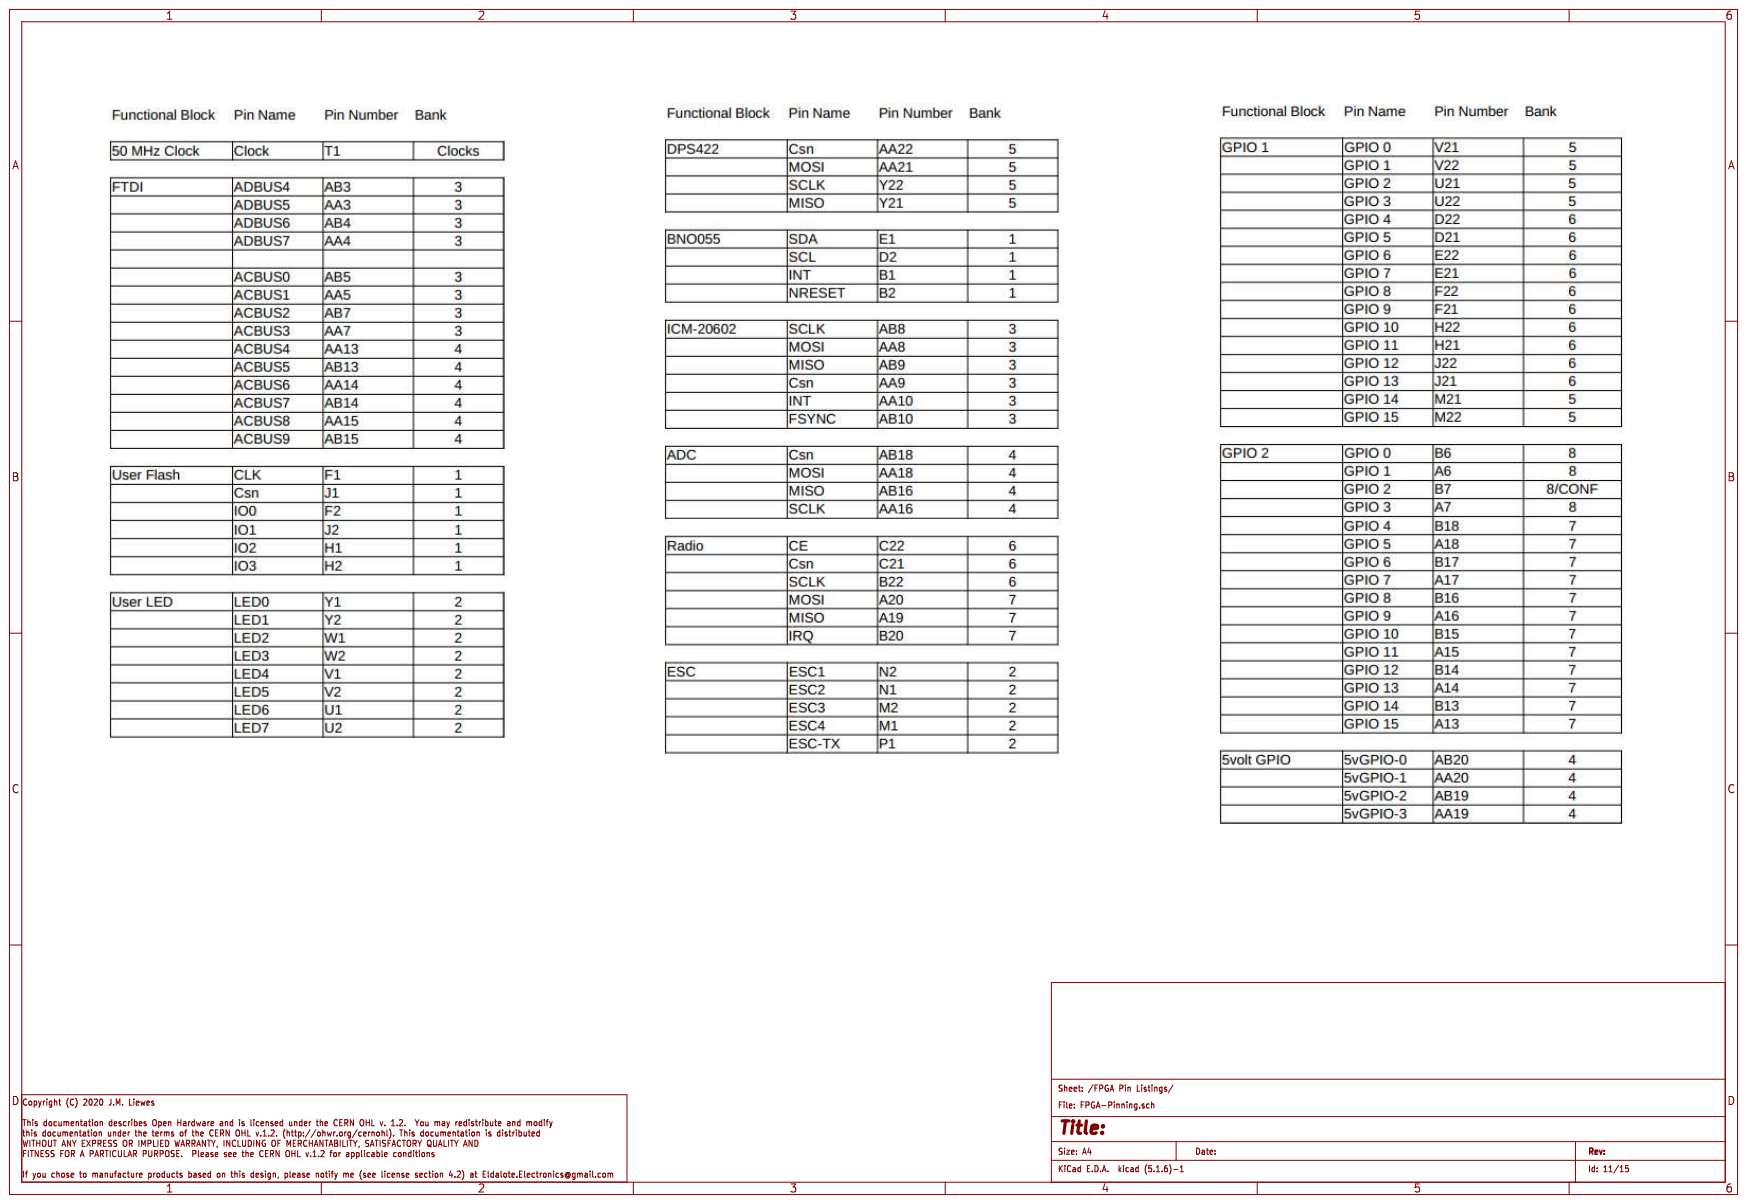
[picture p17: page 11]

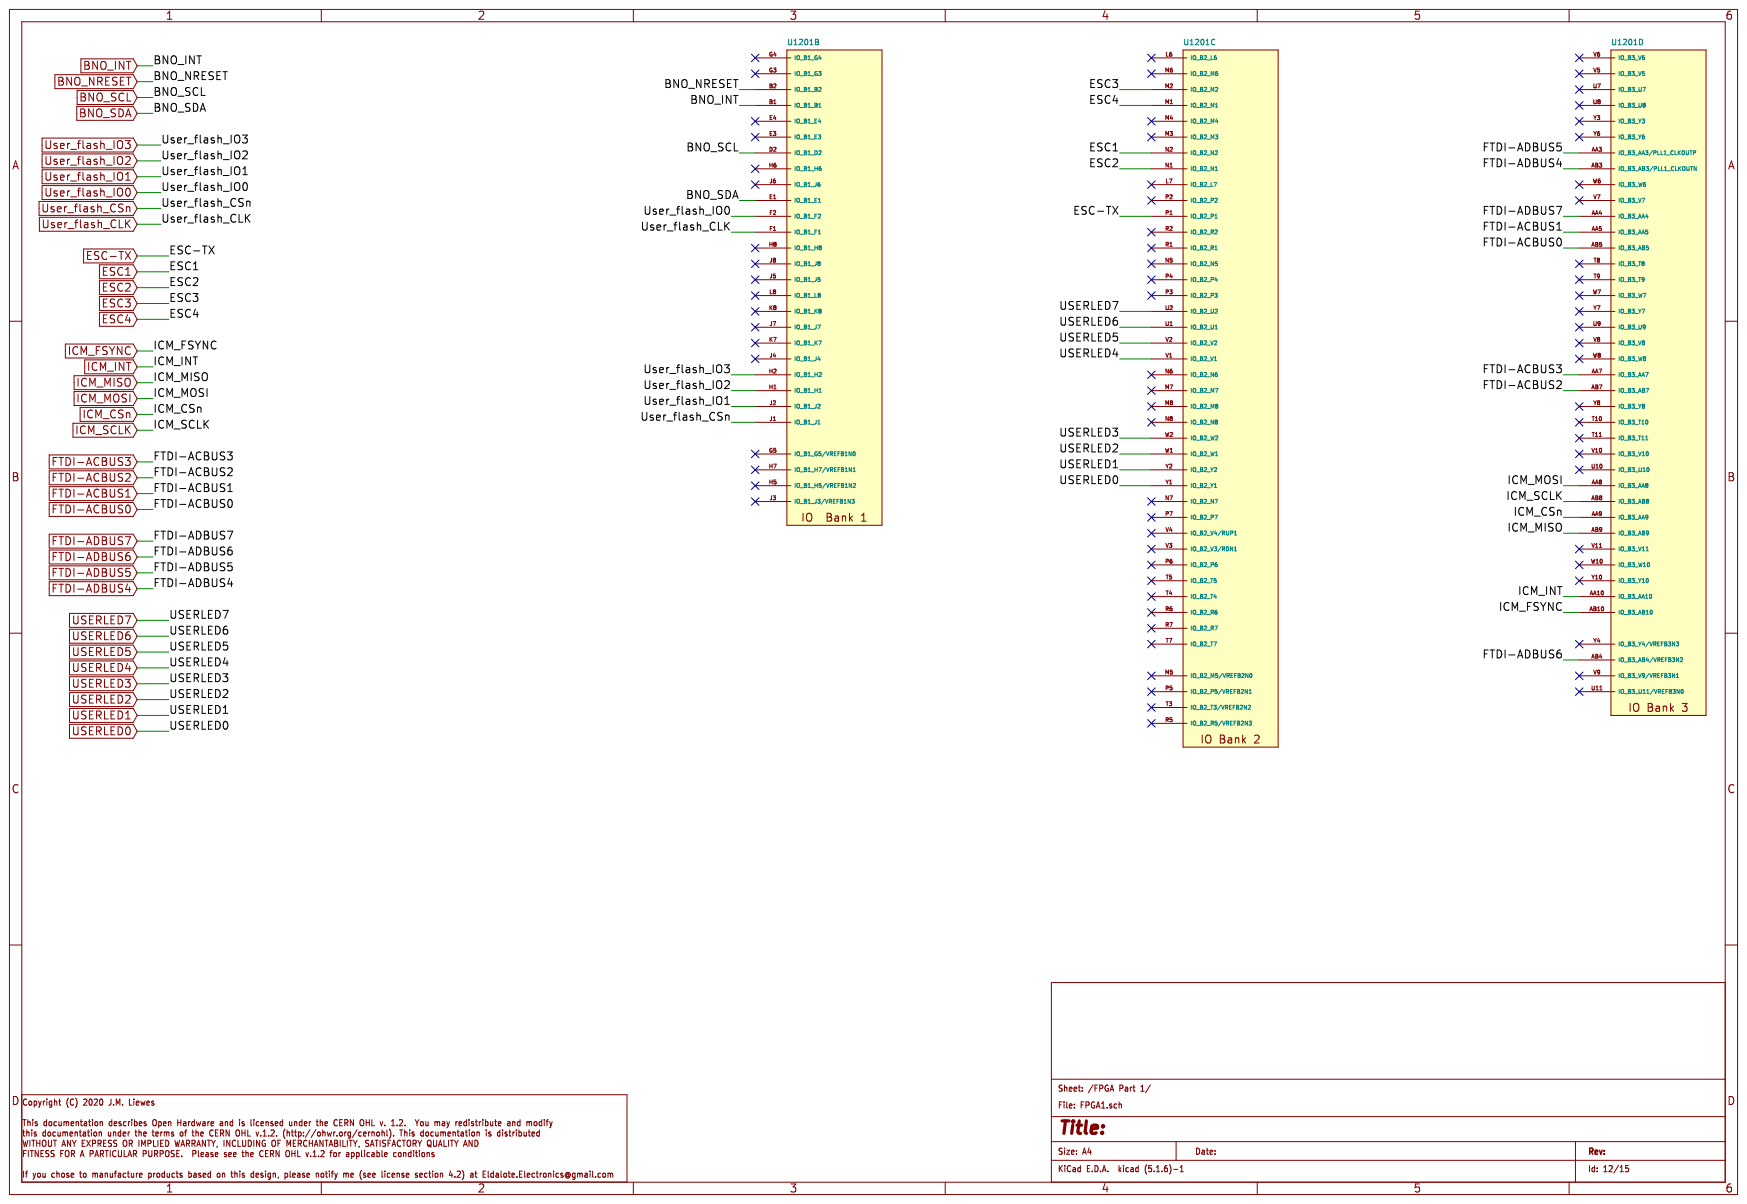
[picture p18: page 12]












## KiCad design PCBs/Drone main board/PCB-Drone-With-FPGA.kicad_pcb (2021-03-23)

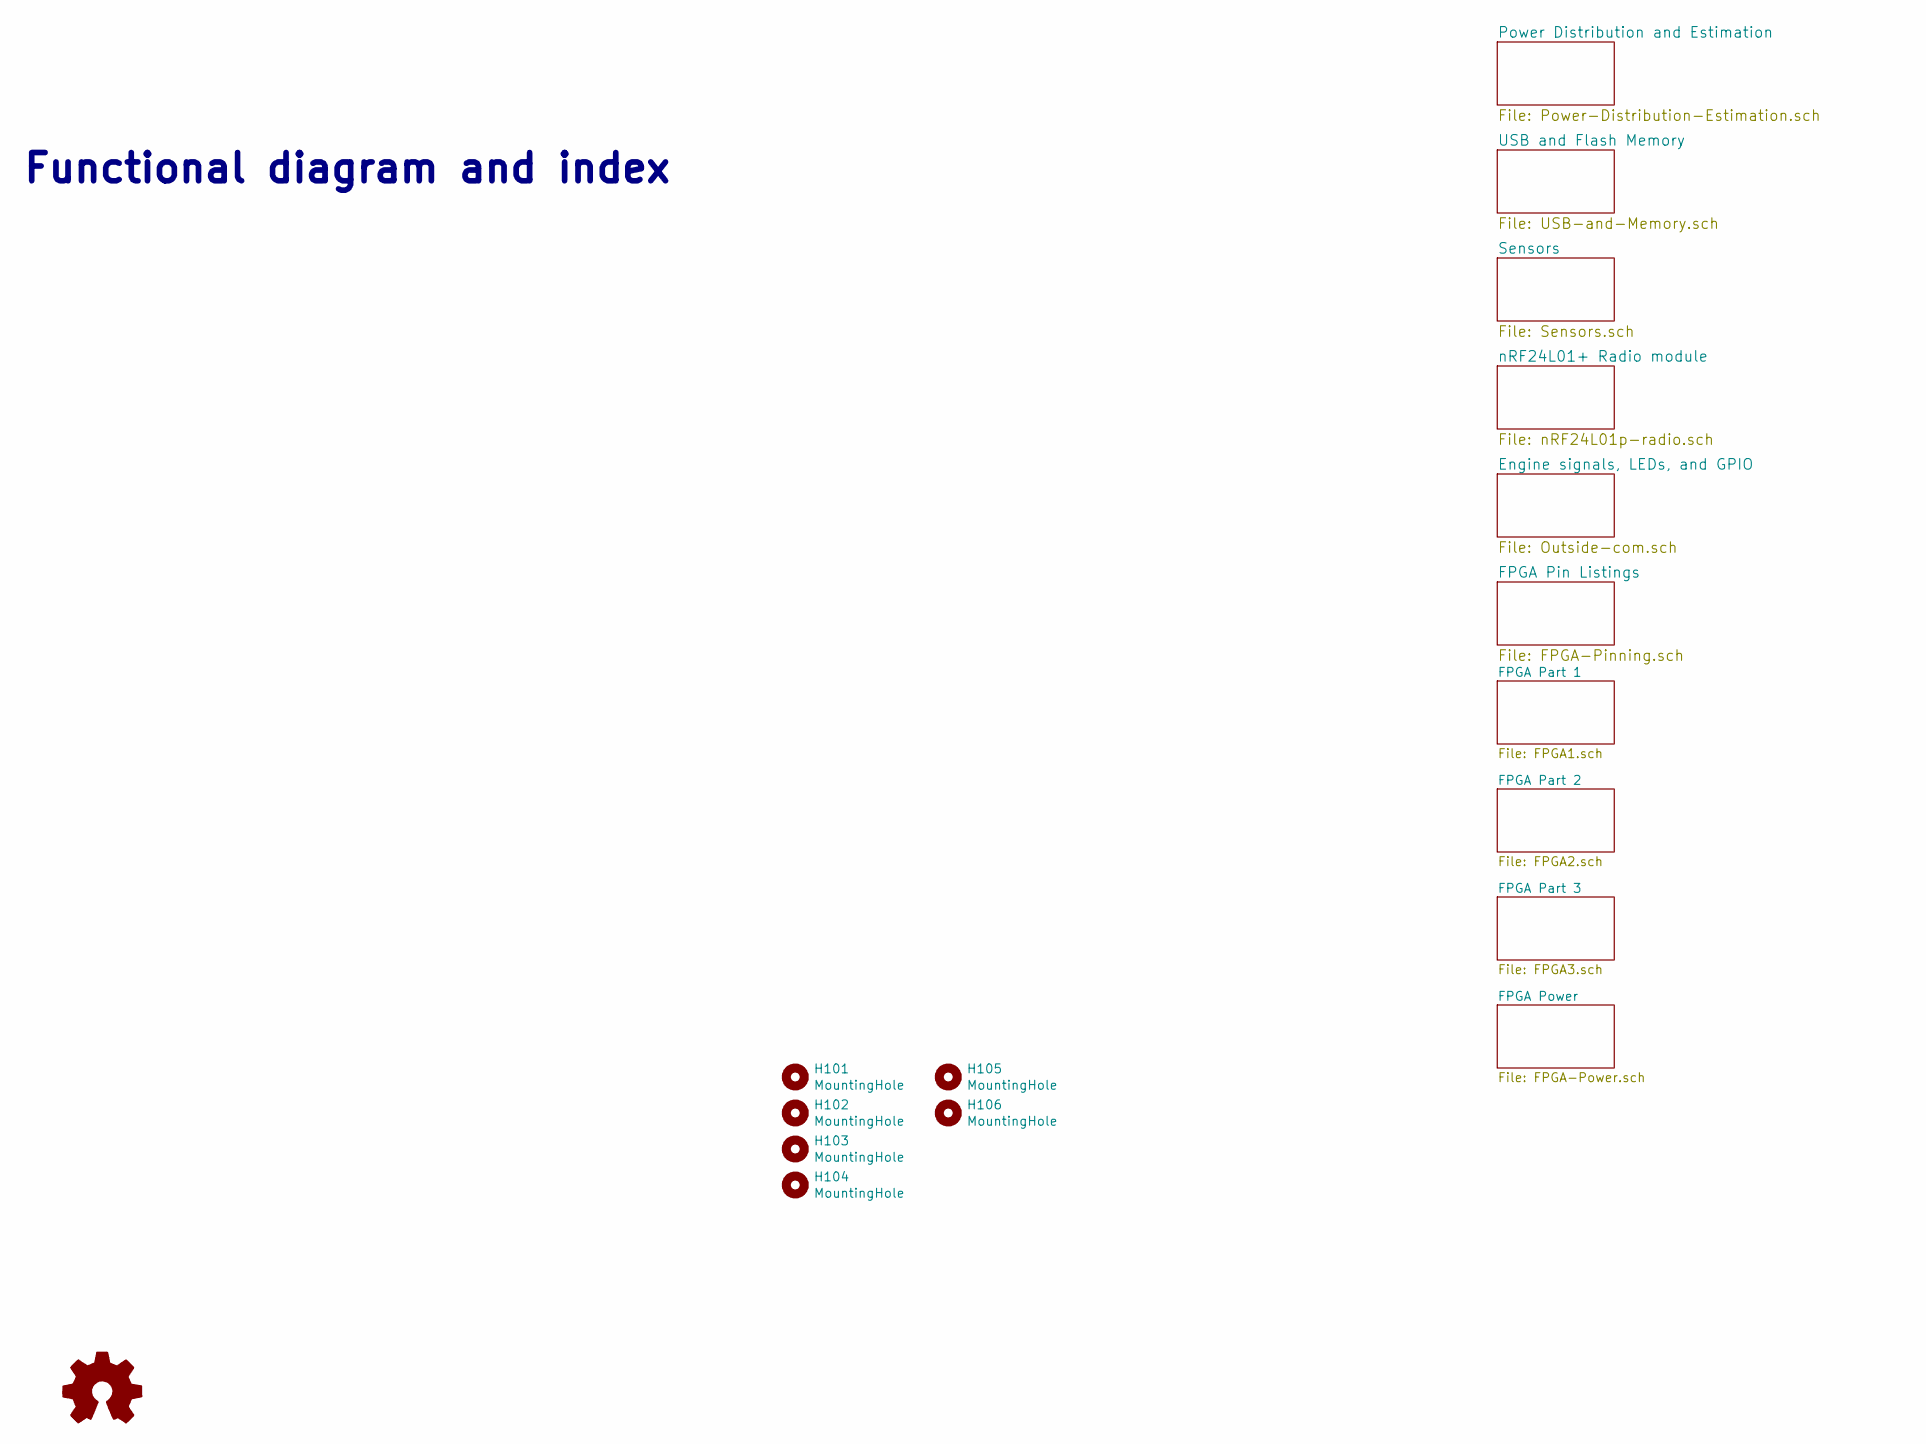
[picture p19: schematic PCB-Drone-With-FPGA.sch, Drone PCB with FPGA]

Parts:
H101, H102, H103, H104: MountingHole; MountingHole_3.2mm_M3
H105, H106: MountingHole; MountingHole_6mm
LOGO101: Logo_Open_Hardware_Small; OSHW-Logo_5.7x6mm_SilkScreen

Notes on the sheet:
Functional diagram and index

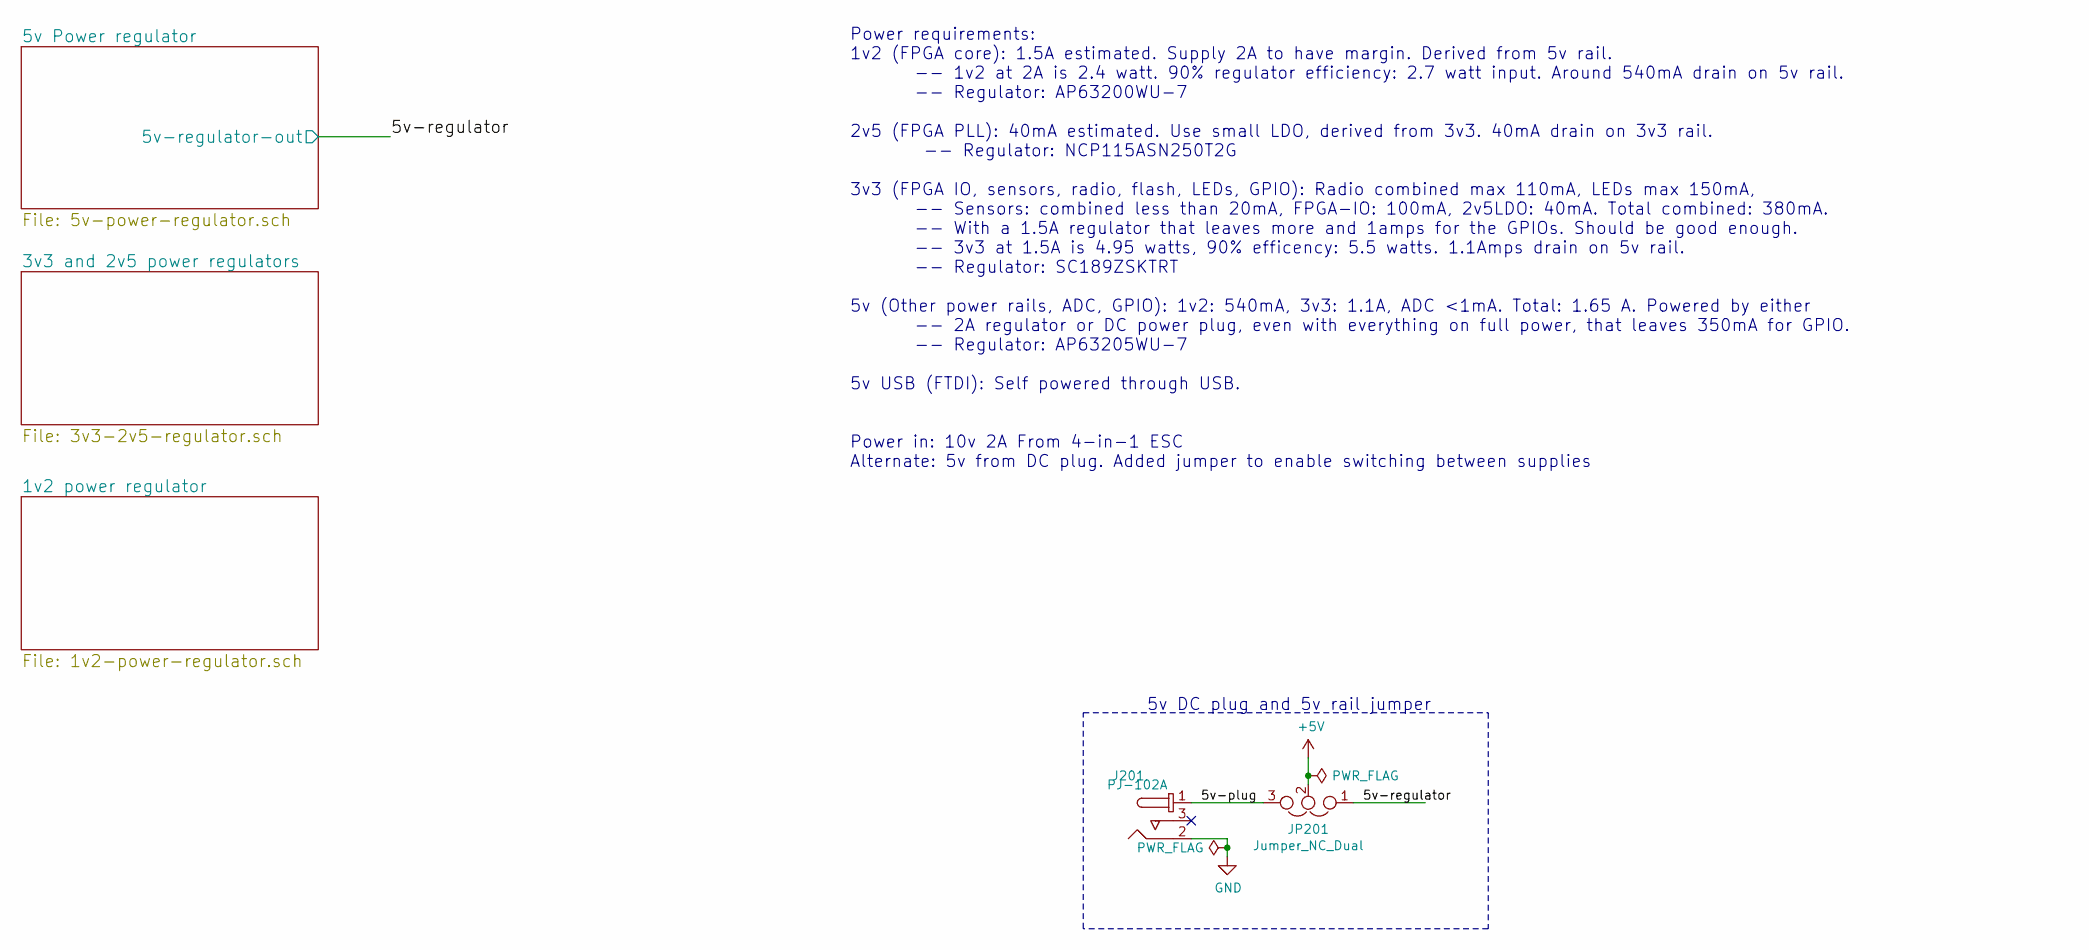
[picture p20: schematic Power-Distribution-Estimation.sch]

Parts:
J201: PJ-102A; Barrel_Jack_5.5mmODx2.1mmID_PJ-102A
JP201: Jumper_NC_Dual; PinHeader_1x03_P2.54mm_Vertical

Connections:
+5V: JP201.2; also elsewhere on the board
/Power Distribution and Estimation/5v-plug: J201.1, JP201.3
/Power Distribution and Estimation/5v-regulator: JP201.1; also elsewhere on the board
GND: J201.2; also elsewhere on the board

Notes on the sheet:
Power requirements: 1v2 (FPGA core): 1.5A estimated. Supply 2A to have margin. Derived from 5v rail. -- 1v2 at 2A is 2.4 watt. 90% regulator efficiency: 2.7 watt input. Around 540mA drain on 5v rail. -- Regulator: AP63200WU-7 2v5 (FPGA PLL): 40mA estimated. Use small LDO, derived from 3v3. 40mA dra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
5v DC plug and 5v rail jumper

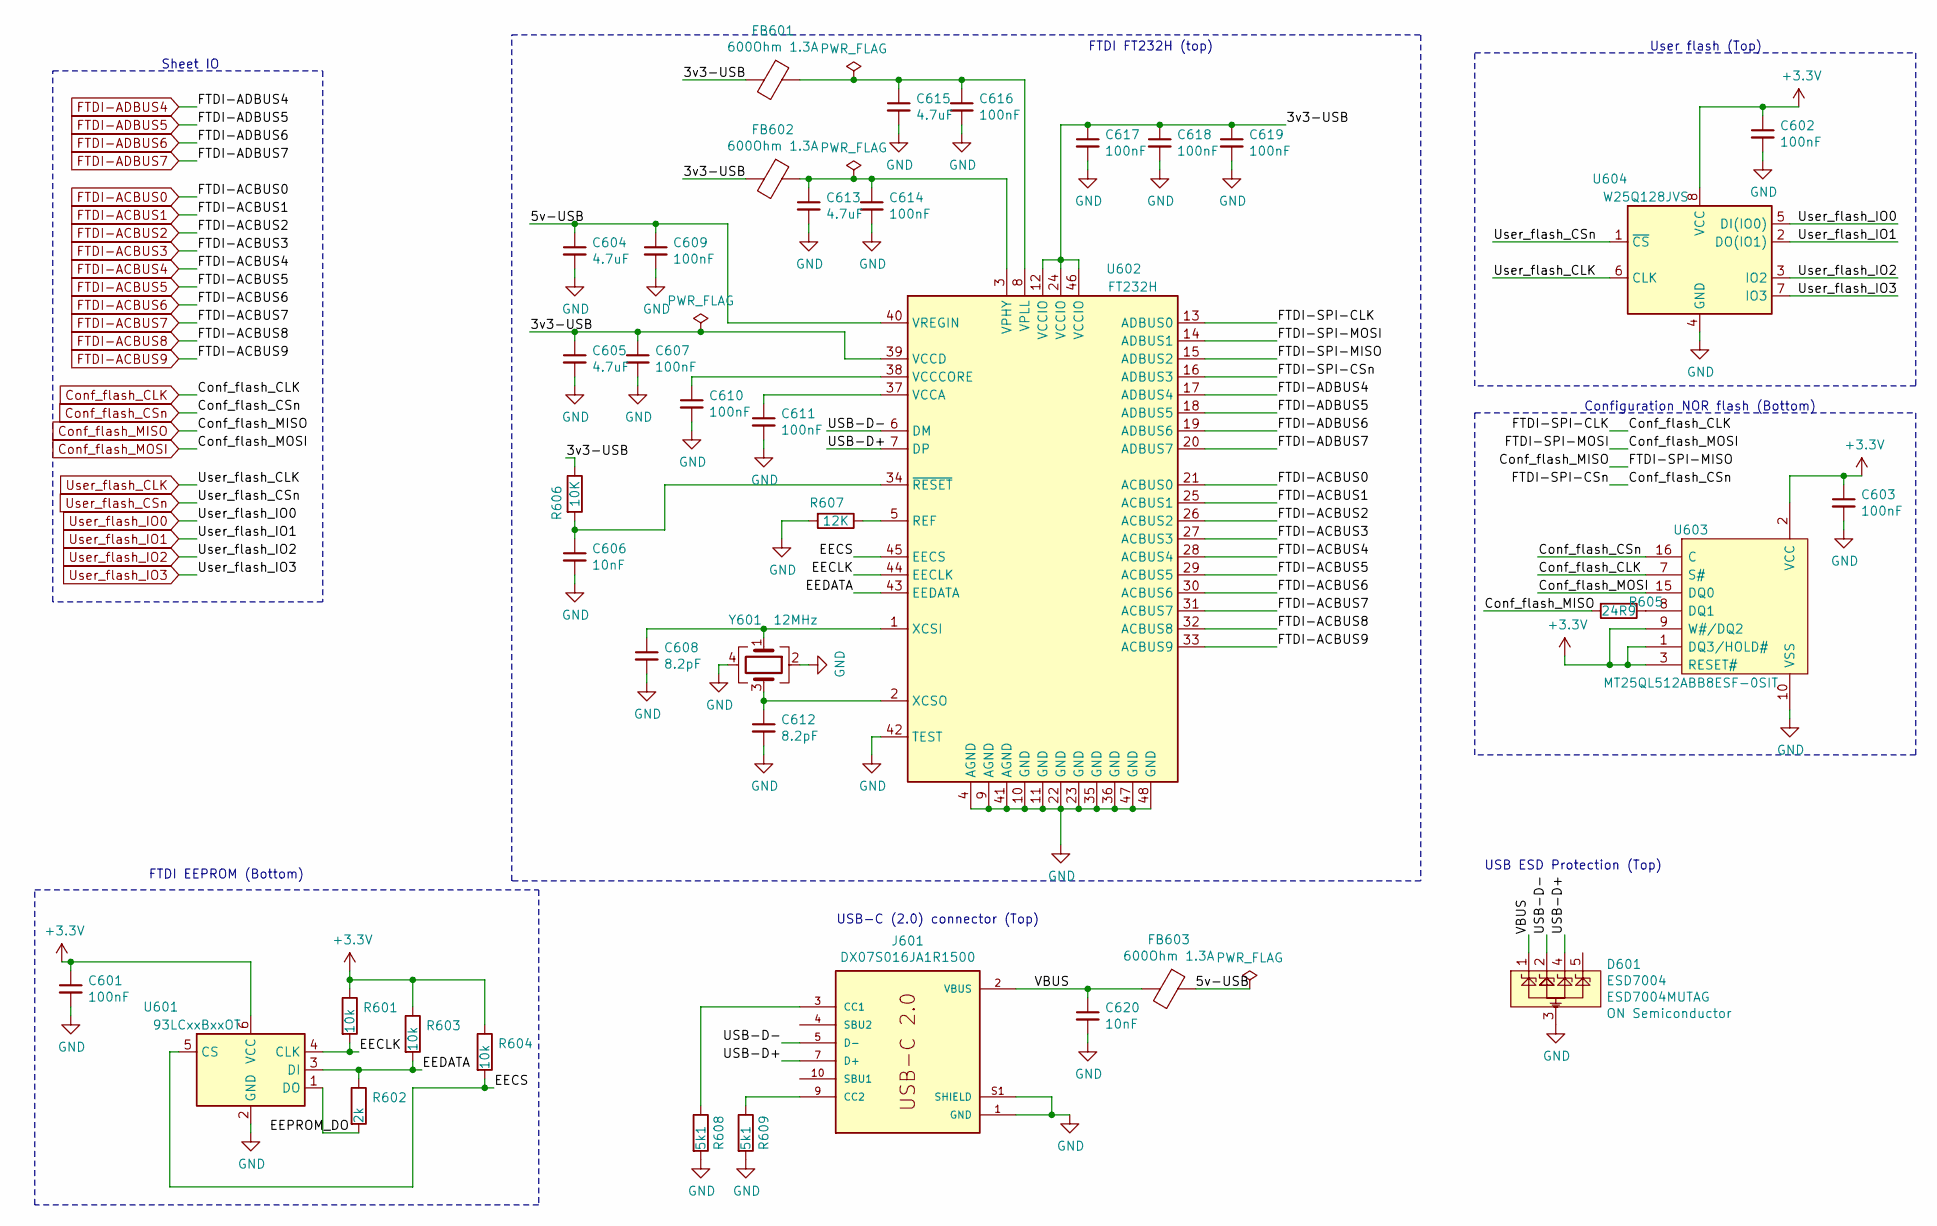
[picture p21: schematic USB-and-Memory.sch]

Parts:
C601, C602, C603, C607, C609, C610, C611, C614, C616, C617, C618, C619: 100nF; C_0402_1005Metric
C604, C605, C613, C615: 4.7uF; C_0402_1005Metric
C606, C620: 10nF; C_0402_1005Metric
C608, C612: 8.2pF; C_0402_1005Metric
D601: ESD7004; Diodes_UDFN-10_1.0x2.5mm_P0.5mm
FB601, FB602, FB603: 600Ohm 1.3A; R_0603_1608Metric
J601: DX07S016JA1R1500; JAE_DX07S016JA1R1500
R601, R603, R604: 10k; R_0402_1005Metric
R602: 2k; R_0402_1005Metric
R605: 24R9; R_0402_1005Metric
R606: 10K; R_0402_1005Metric
R607: 12K; R_0402_1005Metric
R608, R609: 5k1; R_0402_1005Metric
U601: 93LCxxBxxOT; SOT-23-6
U602: FT232H; LQFP-48_7x7mm_P0.5mm
U603: MT25QL512ABB8ESF-0SIT; SOIC127P1032X265-16N
U604: W25Q128JVS; SOIC-8_5.23x5.23mm_P1.27mm
Y601: 12MHz; Crystal NDK 3.2x2.5

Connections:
+3V3: C601.1, C602.1, C603.1, R601.1, R603.1, R604.1, U601.6 (VCC), U603.1 (DQ3/HOLD#), U603.2 (VCC), U603.3 (RESET#), U603.9 (W#/DQ2), U604.8 (VCC); also elsewhere on the board
/USB and Flash Memory/3v3-USB: C605.1, C607.1, C617.1, C618.1, C619.1, FB601.2, FB602.2, R606.1, U602.12 (VCCIO), U602.24 (VCCIO), U602.39 (VCCD), U602.46 (VCCIO)
/USB and Flash Memory/5v-USB: C604.1, C609.1, FB603.1, U602.40 (VREGIN)
/USB and Flash Memory/EECLK: R601.2, U601.4 (CLK), U602.44 (EECLK)
/USB and Flash Memory/EECS: R604.2, U601.5 (CS), U602.45 (EECS)
/USB and Flash Memory/EEDATA: R602.1, R603.2, U601.3 (DI), U602.43 (EEDATA)
/USB and Flash Memory/EEPROM_DO: R602.2, U601.1 (DO)
/USB and Flash Memory/USB-D+: D601.4, D601.7 (NC), J601.6 (D+), J601.7 (D+), U602.7 (DP)
/USB and Flash Memory/USB-D-: D601.2, D601.9 (NC), J601.5 (D-), J601.8 (D-), U602.6 (DM)
Conf_flash_CLK: U602.13 (ADBUS0), U603.7 (S#); also elsewhere on the board
Conf_flash_CSn: U602.16 (ADBUS3), U603.16 (C); also elsewhere on the board
Conf_flash_MISO: R605.2, U602.15 (ADBUS2); also elsewhere on the board
Conf_flash_MOSI: U602.14 (ADBUS1), U603.15 (DQ0); also elsewhere on the board
FTDI-ACBUS0: U602.21 (ACBUS0); also elsewhere on the board
FTDI-ACBUS1: U602.25 (ACBUS1); also elsewhere on the board
FTDI-ACBUS2: U602.26 (ACBUS2); also elsewhere on the board
FTDI-ACBUS3: U602.27 (ACBUS3); also elsewhere on the board
FTDI-ACBUS4: U602.28 (ACBUS4); also elsewhere on the board
FTDI-ACBUS5: U602.29 (ACBUS5); also elsewhere on the board
FTDI-ACBUS6: U602.30 (ACBUS6); also elsewhere on the board
FTDI-ACBUS7: U602.31 (ACBUS7); also elsewhere on the board
FTDI-ACBUS8: U602.32 (ACBUS8); also elsewhere on the board
FTDI-ACBUS9: U602.33 (ACBUS9); also elsewhere on the board
FTDI-ADBUS4: U602.17 (ADBUS4); also elsewhere on the board
FTDI-ADBUS5: U602.18 (ADBUS5); also elsewhere on the board
FTDI-ADBUS6: U602.19 (ADBUS6); also elsewhere on the board
FTDI-ADBUS7: U602.20 (ADBUS7); also elsewhere on the board
GND: C601.2, C602.2, C603.2, C604.2, C605.2, C606.2, C607.2, C608.2, C609.2, C610.2, C611.2, C612.2, C613.2, C614.2, C615.2, C616.2, C617.2, C618.2, C619.2, C620.2, D601.3, D601.8 (GND), J601.1 (GND), J601.12 (GND), J601.S1 (SHIELD), J601.S2 (SHIELD), J601.S3 (SHIELD), J601.S4 (SHIELD), J601.S5 (SHIELD), J601.S6 (SHIELD), R607.2, R608.2, R609.2, U601.2 (GND), U602.4 (AGND), U602.9 (AGND), U602.10 (GND), U602.11 (GND), U602.22 (GND), U602.23 (GND), U602.35 (GND), U602.36 (GND), U602.41 (AGND), U602.42 (TEST), U602.47 (GND), U602.48 (GND), U603.10 (VSS), U604.4 (GND), Y601.2, Y601.4; also elsewhere on the board
unnamed: C606.1, R606.2, U602.34 (~RESET)
unnamed: C608.1, U602.1 (XCSI), Y601.1
unnamed: C610.1, U602.38 (VCCCORE)
unnamed: C611.1, U602.37 (VCCA)
unnamed: C612.1, U602.2 (XCSO), Y601.3
unnamed: C613.1, C614.1, FB602.1, U602.3 (VPHY)
unnamed: C615.1, C616.1, FB601.1, U602.8 (VPLL)
unnamed: D601.5, D601.6 (NC)
unnamed: J601.3 (CC1), R608.1
unnamed: J601.9 (CC2), R609.1
unnamed: R605.1, U603.8 (DQ1)
unnamed: R607.1, U602.5 (REF)
User_flash_CLK: U604.6 (CLK); also elsewhere on the board
User_flash_CSn: U604.1 (~CS); also elsewhere on the board
User_flash_IO0: U604.5 (DI(IO0)); also elsewhere on the board
User_flash_IO1: U604.2 (DO(IO1)); also elsewhere on the board
User_flash_IO2: U604.3 (IO2); also elsewhere on the board
User_flash_IO3: U604.7 (IO3); also elsewhere on the board
VBUS: C620.1, D601.1, D601.10 (NC), FB603.2, J601.2 (VBUS), J601.11 (VBUS)

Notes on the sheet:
Configuration NOR flash (Bottom)
User flash (Top)
FTDI EEPROM (Bottom)
FTDI FT232H (top)
USB-C (2.0) connector (Top)
Sheet IO
USB ESD Protection (Top)

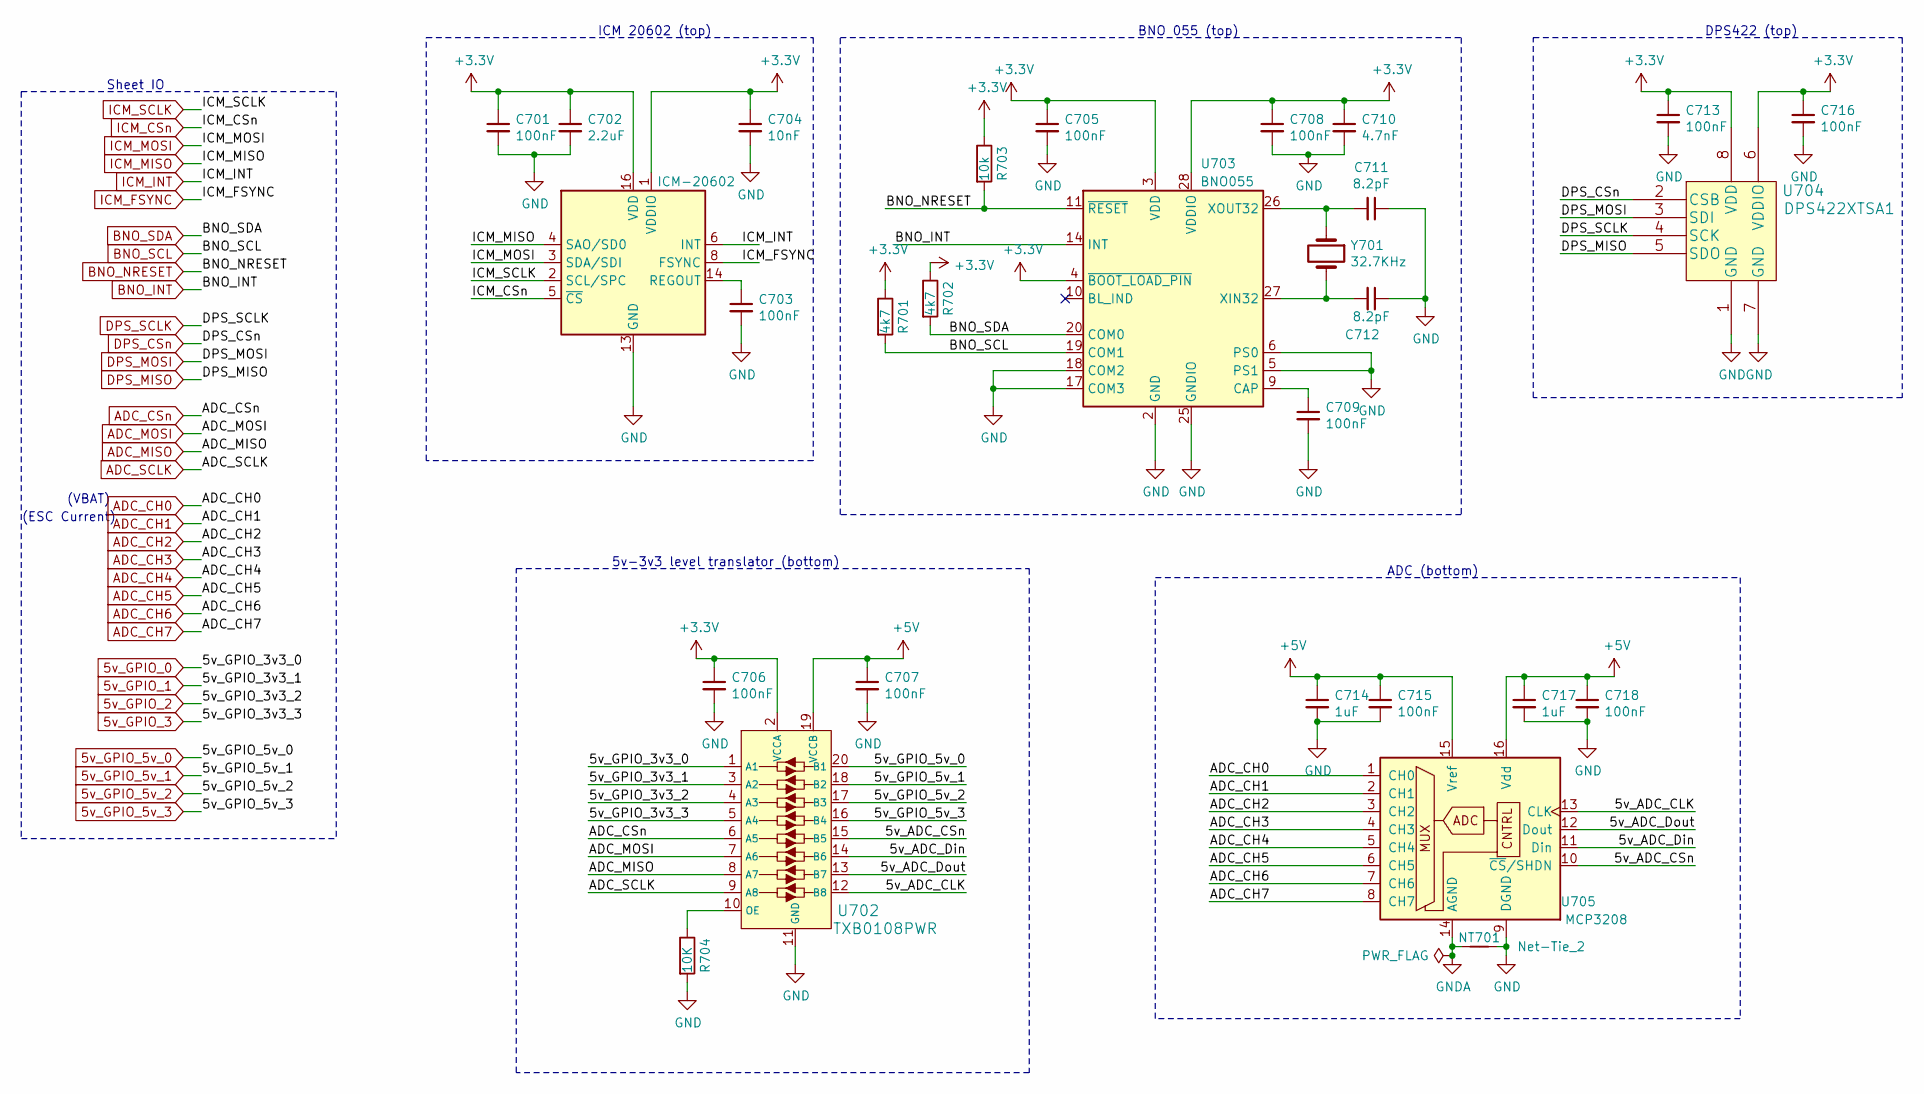
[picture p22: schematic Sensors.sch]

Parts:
C701, C703, C705, C706, C707, C708, C709, C713, C715, C716, C718: 100nF; C_0402_1005Metric
C702: 2.2uF; C_0603_1608Metric
C704: 10nF; C_0402_1005Metric
C710: 4.7nF; C_0402_1005Metric
C711, C712: 8.2pF; C_0402_1005Metric
C714, C717: 1uF; C_0603_1608Metric
NT701: Net-Tie_2; NetTie-2_SMD_Pad0.5mm
R701, R702: 4k7; R_0402_1005Metric
R703: 10k; R_0402_1005Metric
R704: 10K; R_0402_1005Metric
U701: ICM-20602; LGA-16_3x3mm_P0.5mm_LayoutBorder3x5y
U702: TXB0108PWR; TSSOP-20_W4.4mm
U703: BNO055; LGA-28_5.2x3.8mm_P0.5mm
U704: DPS422XTSA1
U705: MCP3208; SOIC-16_3.9x9.9mm_P1.27mm
Y701: 32.7KHz; Crystal_SMD_3215-2Pin_3.2x1.5mm

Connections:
5v_GPIO_0: U702.1 (A1); also elsewhere on the board
5v_GPIO_1: U702.3 (A2); also elsewhere on the board
5v_GPIO_2: U702.4 (A3); also elsewhere on the board
5v_GPIO_3: U702.5 (A4); also elsewhere on the board
5v_GPIO_5v_0: U702.20 (B1); also elsewhere on the board
5v_GPIO_5v_1: U702.18 (B2); also elsewhere on the board
5v_GPIO_5v_2: U702.17 (B3); also elsewhere on the board
5v_GPIO_5v_3: U702.16 (B4); also elsewhere on the board
+3V3: C701.1, C702.1, C704.1, C705.1, C706.1, C708.1, C710.1, C713.1, C716.1, R701.1, R702.1, R703.1, U701.1 (VDDIO), U701.16 (VDD), U702.2 (VCCA), U703.3 (VDD), U703.4 (~BOOT_LOAD_PIN), U703.28 (VDDIO), U704.6 (VDDIO), U704.8 (VDD); also elsewhere on the board
+5V: C707.1, C714.1, C715.1, C717.1, C718.1, U702.19 (VCCB), U705.15 (Vref), U705.16 (Vdd); also elsewhere on the board
/Sensors/5v_ADC_CLK: U702.12 (B8), U705.13 (CLK)
/Sensors/5v_ADC_CSn: U702.15 (B5), U705.10 (~CS~/SHDN)
/Sensors/5v_ADC_Din: U702.14 (B6), U705.11 (Din)
/Sensors/5v_ADC_Dout: U702.13 (B7), U705.12 (Dout)
ADC_CH0: U705.1 (CH0); also elsewhere on the board
ADC_CH1: U705.2 (CH1); also elsewhere on the board
ADC_CH2: U705.3 (CH2); also elsewhere on the board
ADC_CH3: U705.4 (CH3); also elsewhere on the board
ADC_CH4: U705.5 (CH4); also elsewhere on the board
ADC_CH5: U705.6 (CH5); also elsewhere on the board
ADC_CH6: U705.7 (CH6); also elsewhere on the board
ADC_CH7: U705.8 (CH7); also elsewhere on the board
ADC_CSn: U702.6 (A5); also elsewhere on the board
ADC_MISO: U702.8 (A7); also elsewhere on the board
ADC_MOSI: U702.7 (A6); also elsewhere on the board
ADC_SCLK: U702.9 (A8); also elsewhere on the board
BNO_INT: U703.14 (INT); also elsewhere on the board
BNO_NRESET: R703.2, U703.11 (~RESET); also elsewhere on the board
BNO_SCL: R701.2, U703.19 (COM1); also elsewhere on the board
BNO_SDA: R702.2, U703.20 (COM0); also elsewhere on the board
DPS_CSn: U704.2 (CSB); also elsewhere on the board
DPS_MISO: U704.5 (SDO); also elsewhere on the board
DPS_MOSI: U704.3 (SDI); also elsewhere on the board
DPS_SCLK: U704.4 (SCK); also elsewhere on the board
GND: C701.2, C702.2, C703.2, C704.2, C705.2, C706.2, C707.2, C708.2, C709.2, C710.2, C711.1, C712.1, C713.2, C714.2, C715.2, C716.2, C717.2, C718.2, NT701.2, R704.2, U701.9 (GND), U701.10 (GND), U701.11 (GND), U701.12 (GND), U701.13 (GND), U701.15 (GND), U702.11 (GND), U703.2 (GND), U703.5 (PS1), U703.6 (PS0), U703.15 (GNDIO), U703.16 (GNDIO), U703.17 (COM3), U703.18 (COM2), U703.25 (GNDIO), U704.1 (GND), U704.7 (GND), U705.9 (DGND); also elsewhere on the board
GNDA: NT701.1, U705.14 (AGND); also elsewhere on the board
ICM_CSn: U701.5 (~CS); also elsewhere on the board
ICM_FSYNC: U701.8 (FSYNC); also elsewhere on the board
ICM_INT: U701.6 (INT); also elsewhere on the board
ICM_MISO: U701.4 (SAO/SD0); also elsewhere on the board
ICM_MOSI: U701.3 (SDA/SDI); also elsewhere on the board
ICM_SCLK: U701.2 (SCL/SPC); also elsewhere on the board
unnamed: C703.1, U701.14 (REGOUT)
unnamed: C709.1, U703.9 (CAP)
unnamed: C711.2, U703.26 (XOUT32), Y701.1
unnamed: C712.2, U703.27 (XIN32), Y701.2
unnamed: R704.1, U702.10 (OE)

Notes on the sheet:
ICM 20602 (top)
BNO 055 (top)
DPS422 (top)
Sheet IO
5v-3v3 level translator (bottom)
ADC (bottom)
(VBAT)
(ESC Current)

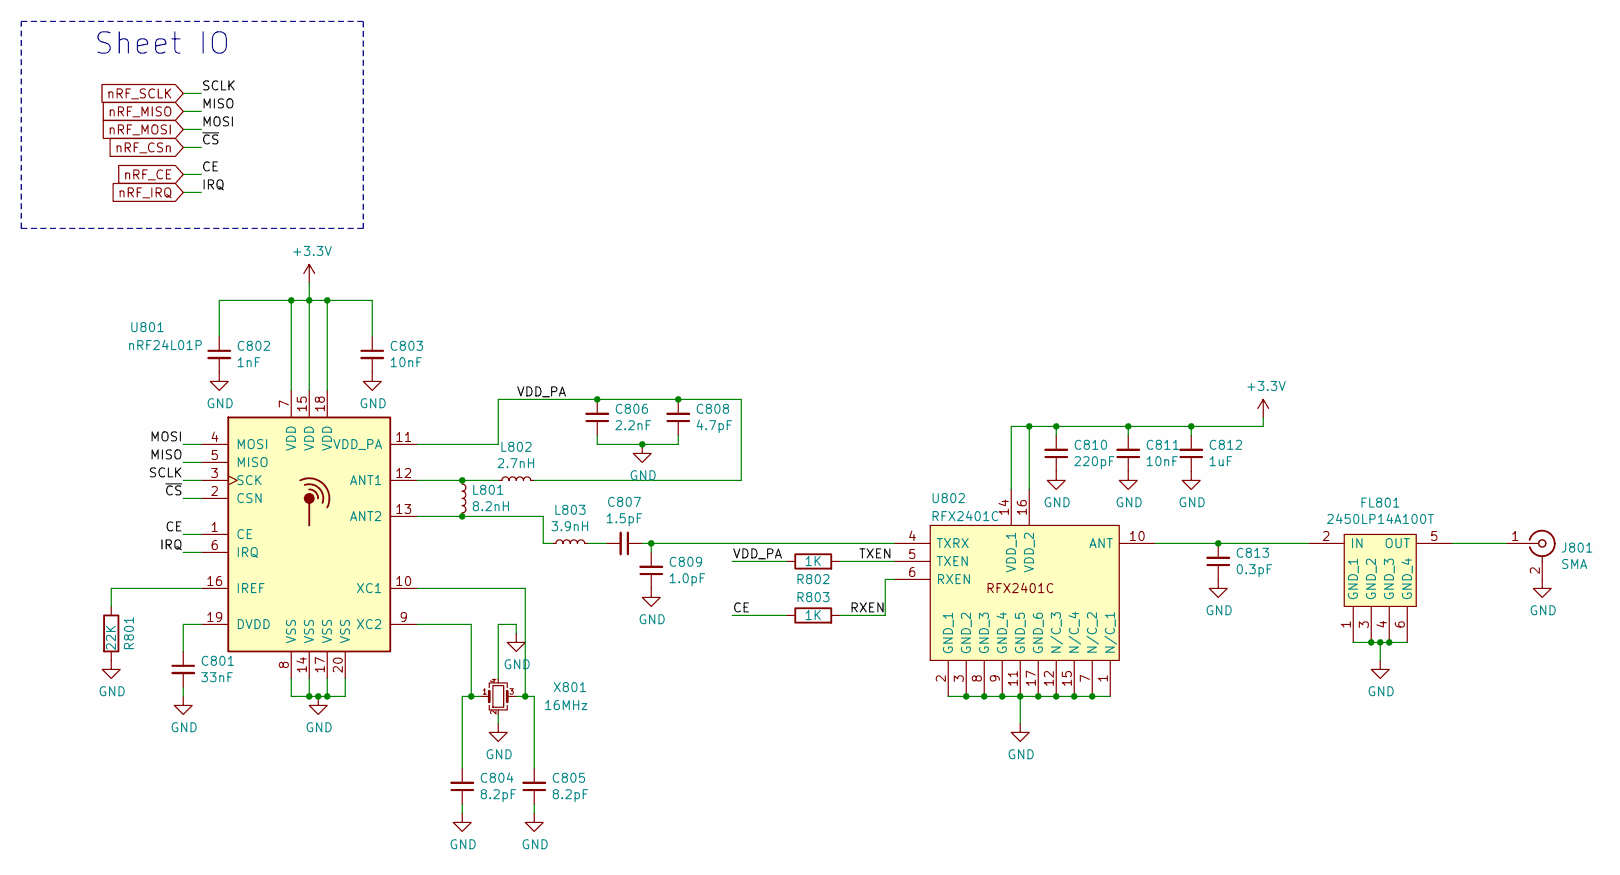
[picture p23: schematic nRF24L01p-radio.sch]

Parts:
C801: 33nF; C_0603_1608Metric
C802: 1nF; C_0402_1005Metric
C803, C811: 10nF; C_0402_1005Metric
C804, C805: 8.2pF; C_0402_1005Metric
C806: 2.2nF; C_0402_1005Metric
C807: 1.5pF; C_0402_1005Metric
C808: 4.7pF; C_0402_1005Metric
C809: 1.0pF; C_0603_1608Metric_Pad1.05x0.95mm_HandSolder
C810: 220pF; C_0402_1005Metric
C812: 1uF; C_0603_1608Metric
C813: 0.3pF; C_0402_1005Metric
FL801: 2450LP14A100T
J801: SMA; SMA_Samtec_SMA-J-P-X-ST-EM1_EdgeMount
L801: 8.2nH; L_0402_1005Metric
L802: 2.7nH; L_0402_1005Metric
L803: 3.9nH; L_0402_1005Metric
R801: 22K; R_0402_1005Metric
R802, R803: 1K; R_0402_1005Metric
U801: nRF24L01P; nRF24L01P-QFN-20-1EP_4x4mm_P0.5mm_EP
U802: RFX2401C; QFN-16-1EP_3x3mm_P0.5mm_EP1.75x1.75mm
X801: 16MHz; Crystal NDK 3.2x2.5

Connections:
+3V3: C802.1, C803.1, C810.2, C811.2, C812.2, U801.7 (VDD), U801.15 (VDD), U801.18 (VDD), U802.14 (VDD_1), U802.16 (VDD_2); also elsewhere on the board
/nRF24L01+ Radio module/RXEN: R803.2, U802.6 (RXEN)
/nRF24L01+ Radio module/TXEN: R802.2, U802.5 (TXEN)
/nRF24L01+ Radio module/VDD_PA: C806.2, C808.2, L802.2, R802.1, U801.11 (VDD_PA)
GND: C801.2, C802.2, C803.2, C804.1, C805.1, C806.1, C808.1, C809.1, C810.1, C811.1, C812.1, C813.1, FL801.1 (GND_1), FL801.3 (GND_2), FL801.4 (GND_3), FL801.6 (GND_4), J801.2 (Ext), R801.2, U801.8 (VSS), U801.14 (VSS), U801.17 (VSS), U801.20 (VSS), U801.21 (EP), U802.1 (N/C_1), U802.2 (GND_1), U802.3 (GND_2), U802.7 (N/C_2), U802.8 (GND_3), U802.9 (GND_4), U802.11 (GND_5), U802.12 (N/C_3), U802.15 (N/C_4), U802.17 (GND_6), X801.2, X801.4; also elsewhere on the board
unnamed: C801.1, U801.19 (DVDD)
unnamed: C804.2, U801.9 (XC2), X801.1
unnamed: C805.2, U801.10 (XC1), X801.3
unnamed: C807.1, C809.2, U802.4 (TXRX)
unnamed: C807.2, L803.2
unnamed: C813.2, FL801.2 (IN), U802.10 (ANT)
unnamed: FL801.5 (OUT), J801.1 (In)
unnamed: L801.1, L802.1, U801.12 (ANT1)
unnamed: L801.2, L803.1, U801.13 (ANT2)
unnamed: R801.1, U801.16 (IREF)
nRF_CE: R803.1, U801.1 (CE); also elsewhere on the board
nRF_CSn: U801.2 (CSN); also elsewhere on the board
nRF_IRQ: U801.6 (IRQ); also elsewhere on the board
nRF_MISO: U801.5 (MISO); also elsewhere on the board
nRF_MOSI: U801.4 (MOSI); also elsewhere on the board
nRF_SCLK: U801.3 (SCK); also elsewhere on the board

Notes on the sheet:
Sheet IO

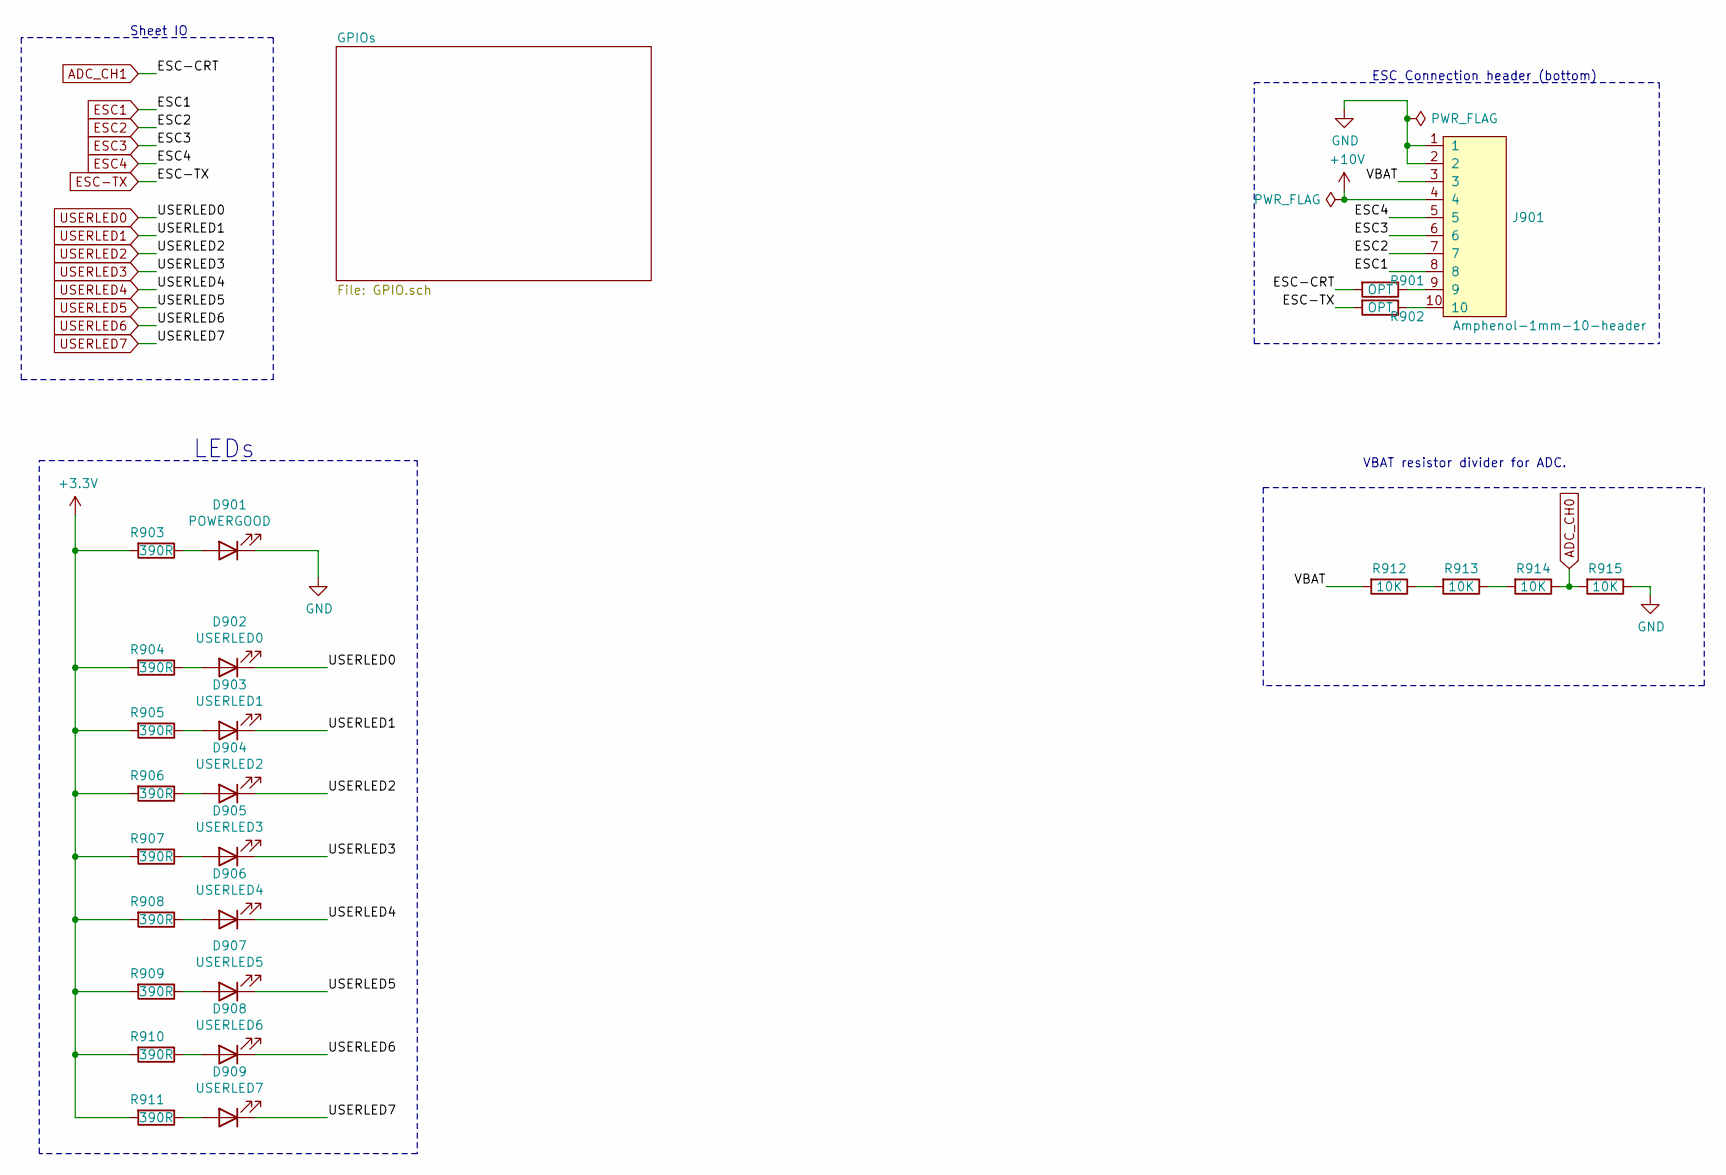
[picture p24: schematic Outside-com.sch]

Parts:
D901: POWERGOOD; LED_0603_1608Metric
D902: USERLED0; LED_0603_1608Metric
D903: USERLED1; LED_0603_1608Metric
D904: USERLED2; LED_0603_1608Metric
D905: USERLED3; LED_0603_1608Metric
D906: USERLED4; LED_0603_1608Metric
D907: USERLED5; LED_0603_1608Metric
D908: USERLED6; LED_0603_1608Metric
D909: USERLED7; LED_0603_1608Metric
J901: Amphenol-1mm-10-header; Amphenol-10-1mm
R901, R902: OPT; R_0402_1005Metric
R903, R904, R905, R906, R907, R908, R909, R910, R911: 390R; R_0402_1005Metric
R912, R913, R914, R915: 10K; R_0402_1005Metric

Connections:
+3V3: R903.2, R904.2, R905.2, R906.2, R907.2, R908.2, R909.2, R910.2, R911.2; also elsewhere on the board
+10V: J901.4; also elsewhere on the board
/Engine signals, LEDs, and GPIO/VBAT: J901.3, R912.2
ADC_CH0: R914.1, R915.2; also elsewhere on the board
ADC_CH1: R901.2; also elsewhere on the board
ESC1: J901.8; also elsewhere on the board
ESC2: J901.7; also elsewhere on the board
ESC3: J901.6; also elsewhere on the board
ESC4: J901.5; also elsewhere on the board
ESC-TX: R902.2; also elsewhere on the board
GND: D901.1 (K), J901.1, J901.2, R915.1; also elsewhere on the board
unnamed: D901.2 (A), R903.1
unnamed: D902.2 (A), R904.1
unnamed: D903.2 (A), R905.1
unnamed: D904.2 (A), R906.1
unnamed: D905.2 (A), R907.1
unnamed: D906.2 (A), R908.1
unnamed: D907.2 (A), R909.1
unnamed: D908.2 (A), R910.1
unnamed: D909.2 (A), R911.1
unnamed: J901.9, R901.1
unnamed: J901.10, R902.1
unnamed: R912.1, R913.2
unnamed: R913.1, R914.2
USERLED0: D902.1 (K); also elsewhere on the board
USERLED1: D903.1 (K); also elsewhere on the board
USERLED2: D904.1 (K); also elsewhere on the board
USERLED3: D905.1 (K); also elsewhere on the board
USERLED4: D906.1 (K); also elsewhere on the board
USERLED5: D907.1 (K); also elsewhere on the board
USERLED6: D908.1 (K); also elsewhere on the board
USERLED7: D909.1 (K); also elsewhere on the board

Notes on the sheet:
ESC Connection header (bottom)
Sheet IO
LEDs
VBAT resistor divider for ADC.

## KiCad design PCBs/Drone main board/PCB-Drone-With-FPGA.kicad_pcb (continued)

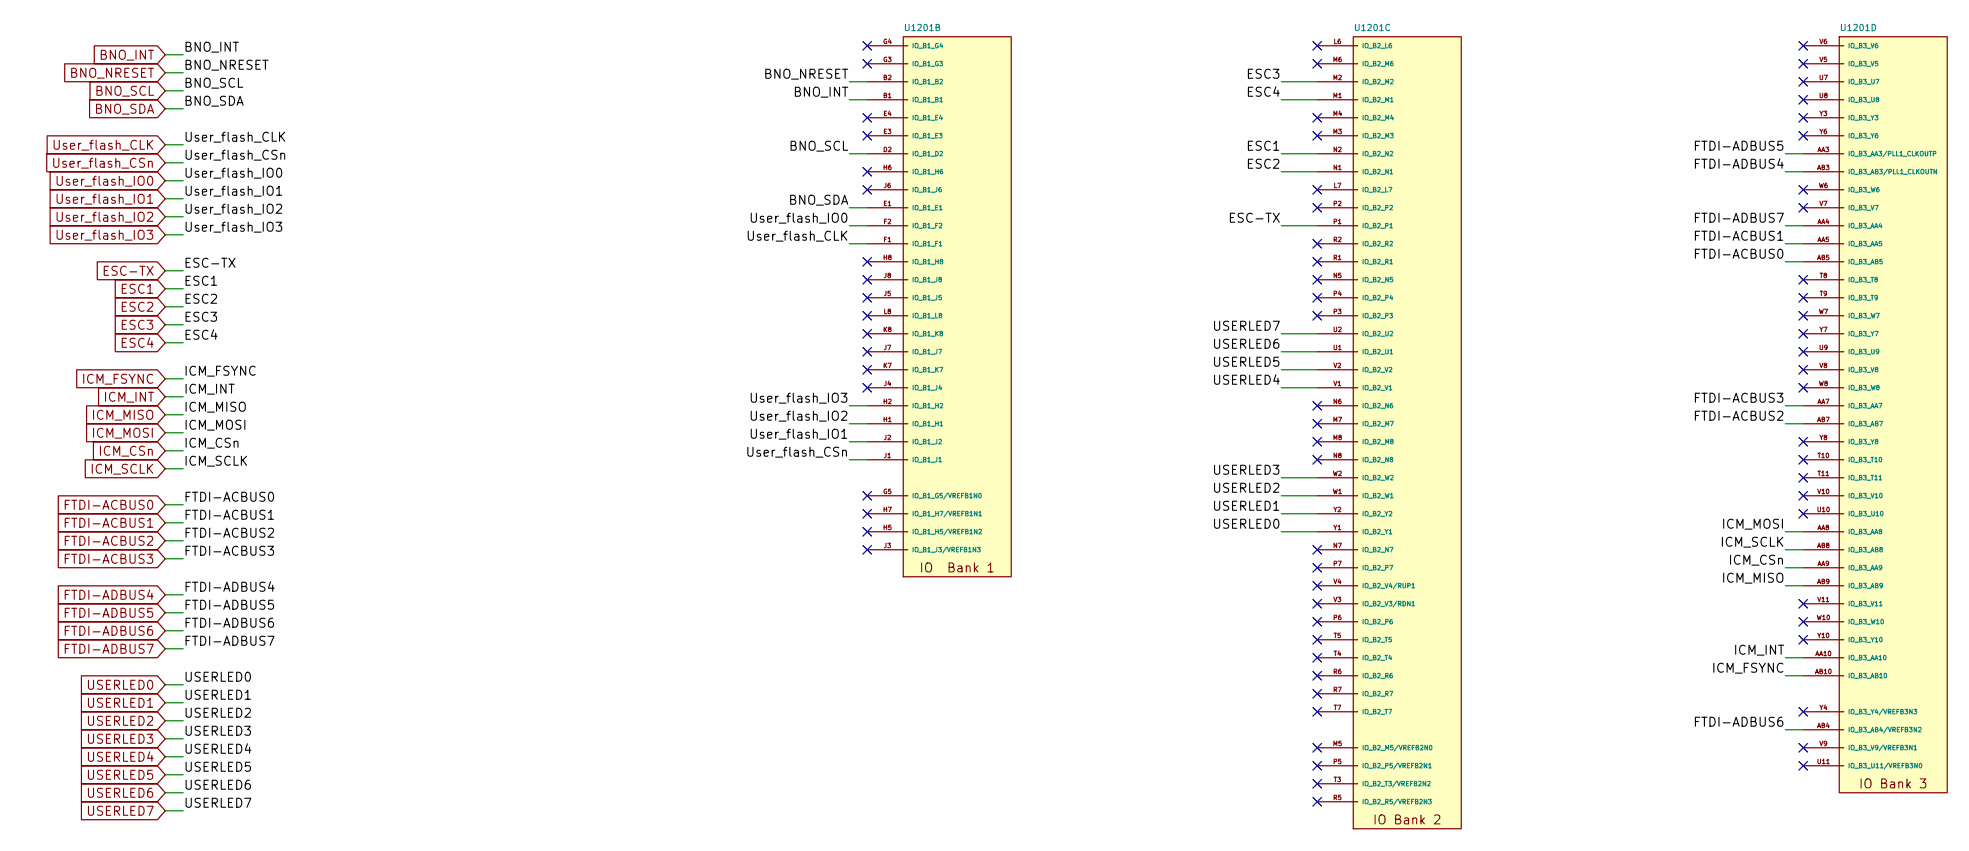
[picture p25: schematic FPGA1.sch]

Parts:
U1201: 10CL040_F484; BGA484C100P22X22_2300X2300X200

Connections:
BNO_INT: U1201.B1 (IO_B1_B1); also elsewhere on the board
BNO_NRESET: U1201.B2 (IO_B1_B2); also elsewhere on the board
BNO_SCL: U1201.D2 (IO_B1_D2); also elsewhere on the board
BNO_SDA: U1201.E1 (IO_B1_E1); also elsewhere on the board
ESC1: U1201.N2 (IO_B2_N2); also elsewhere on the board
ESC2: U1201.N1 (IO_B2_N1); also elsewhere on the board
ESC3: U1201.M2 (IO_B2_M2); also elsewhere on the board
ESC4: U1201.M1 (IO_B2_M1); also elsewhere on the board
ESC-TX: U1201.P1 (IO_B2_P1); also elsewhere on the board
FTDI-ACBUS0: U1201.AB5 (IO_B3_AB5); also elsewhere on the board
FTDI-ACBUS1: U1201.AA5 (IO_B3_AA5); also elsewhere on the board
FTDI-ACBUS2: U1201.AB7 (IO_B3_AB7); also elsewhere on the board
FTDI-ACBUS3: U1201.AA7 (IO_B3_AA7); also elsewhere on the board
FTDI-ADBUS4: U1201.AB3 (IO_B3_AB3/PLL1_CLKOUTN); also elsewhere on the board
FTDI-ADBUS5: U1201.AA3 (IO_B3_AA3/PLL1_CLKOUTP); also elsewhere on the board
FTDI-ADBUS6: U1201.AB4 (IO_B3_AB4/VREFB3N2); also elsewhere on the board
FTDI-ADBUS7: U1201.AA4 (IO_B3_AA4); also elsewhere on the board
ICM_CSn: U1201.AA9 (IO_B3_AA9); also elsewhere on the board
ICM_FSYNC: U1201.AB10 (IO_B3_AB10); also elsewhere on the board
ICM_INT: U1201.AA10 (IO_B3_AA10); also elsewhere on the board
ICM_MISO: U1201.AB9 (IO_B3_AB9); also elsewhere on the board
ICM_MOSI: U1201.AA8 (IO_B3_AA8); also elsewhere on the board
ICM_SCLK: U1201.AB8 (IO_B3_AB8); also elsewhere on the board
USERLED0: U1201.Y1 (IO_B2_Y1); also elsewhere on the board
USERLED1: U1201.Y2 (IO_B2_Y2); also elsewhere on the board
USERLED2: U1201.W1 (IO_B2_W1); also elsewhere on the board
USERLED3: U1201.W2 (IO_B2_W2); also elsewhere on the board
USERLED4: U1201.V1 (IO_B2_V1); also elsewhere on the board
USERLED5: U1201.V2 (IO_B2_V2); also elsewhere on the board
USERLED6: U1201.U1 (IO_B2_U1); also elsewhere on the board
USERLED7: U1201.U2 (IO_B2_U2); also elsewhere on the board
User_flash_CLK: U1201.F1 (IO_B1_F1); also elsewhere on the board
User_flash_CSn: U1201.J1 (IO_B1_J1); also elsewhere on the board
User_flash_IO0: U1201.F2 (IO_B1_F2); also elsewhere on the board
User_flash_IO1: U1201.J2 (IO_B1_J2); also elsewhere on the board
User_flash_IO2: U1201.H1 (IO_B1_H1); also elsewhere on the board
User_flash_IO3: U1201.H2 (IO_B1_H2); also elsewhere on the board

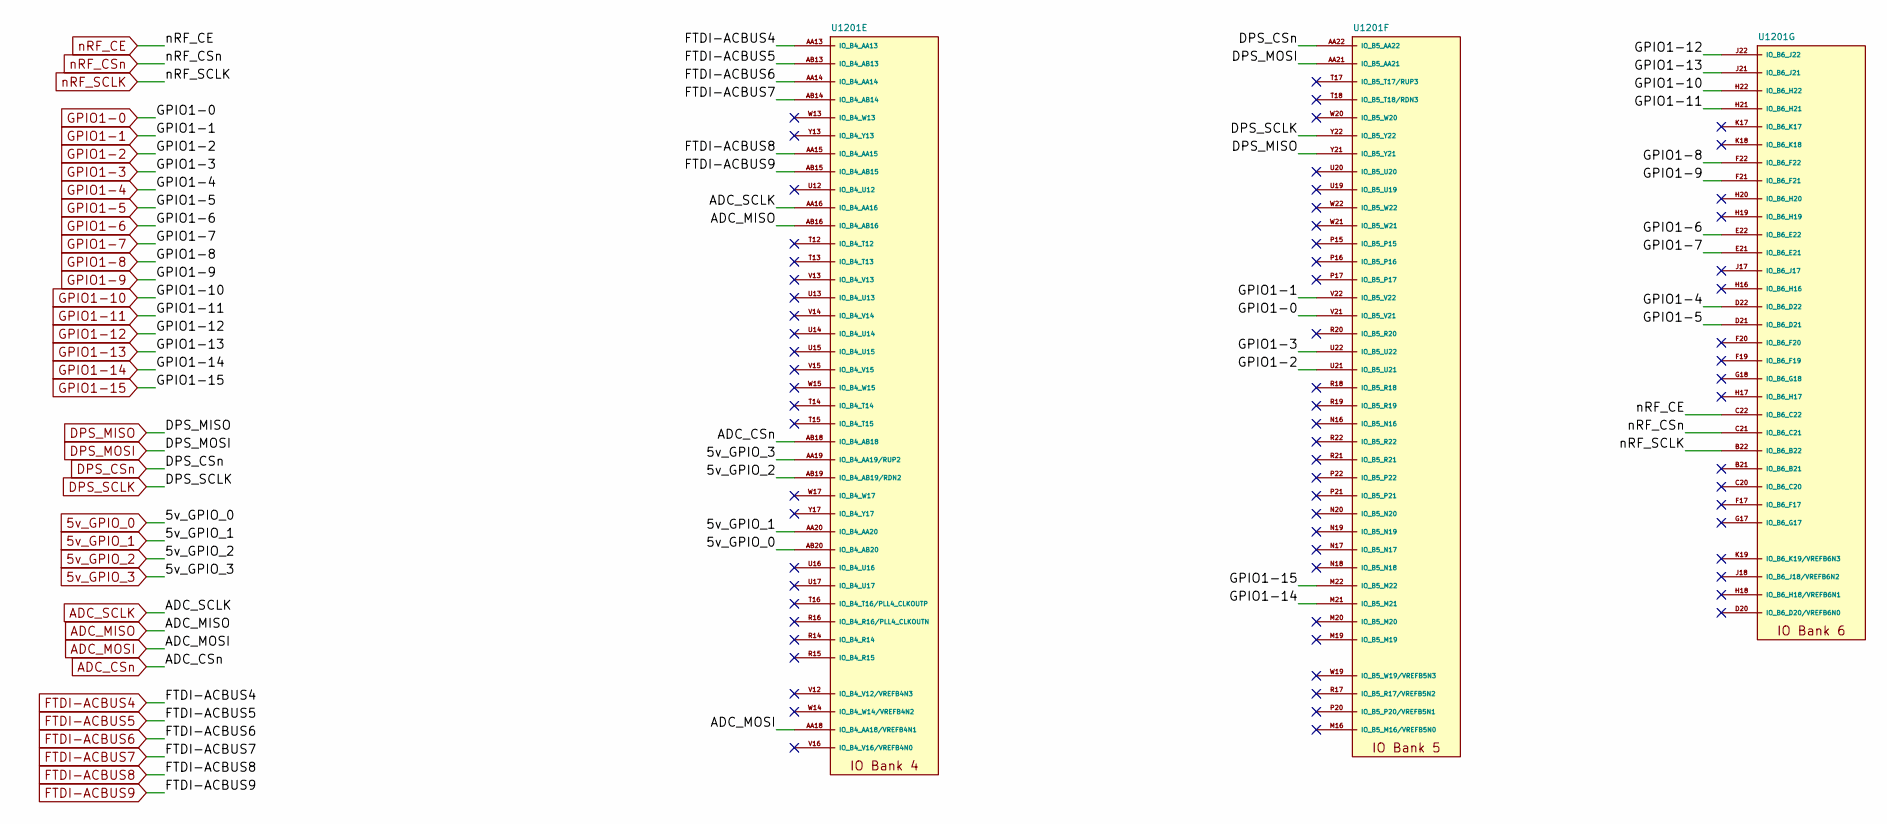
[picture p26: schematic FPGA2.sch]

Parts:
U1201: 10CL040_F484; BGA484C100P22X22_2300X2300X200

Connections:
5v_GPIO_0: U1201.AB20 (IO_B4_AB20); also elsewhere on the board
5v_GPIO_1: U1201.AA20 (IO_B4_AA20); also elsewhere on the board
5v_GPIO_2: U1201.AB19 (IO_B4_AB19/RDN2); also elsewhere on the board
5v_GPIO_3: U1201.AA19 (IO_B4_AA19/RUP2); also elsewhere on the board
ADC_CSn: U1201.AB18 (IO_B4_AB18); also elsewhere on the board
ADC_MISO: U1201.AB16 (IO_B4_AB16); also elsewhere on the board
ADC_MOSI: U1201.AA18 (IO_B4_AA18/VREFB4N1); also elsewhere on the board
ADC_SCLK: U1201.AA16 (IO_B4_AA16); also elsewhere on the board
DPS_CSn: U1201.AA22 (IO_B5_AA22); also elsewhere on the board
DPS_MISO: U1201.Y21 (IO_B5_Y21); also elsewhere on the board
DPS_MOSI: U1201.AA21 (IO_B5_AA21); also elsewhere on the board
DPS_SCLK: U1201.Y22 (IO_B5_Y22); also elsewhere on the board
FTDI-ACBUS4: U1201.AA13 (IO_B4_AA13); also elsewhere on the board
FTDI-ACBUS5: U1201.AB13 (IO_B4_AB13); also elsewhere on the board
FTDI-ACBUS6: U1201.AA14 (IO_B4_AA14); also elsewhere on the board
FTDI-ACBUS7: U1201.AB14 (IO_B4_AB14); also elsewhere on the board
FTDI-ACBUS8: U1201.AA15 (IO_B4_AA15); also elsewhere on the board
FTDI-ACBUS9: U1201.AB15 (IO_B4_AB15); also elsewhere on the board
GPIO1-0: U1201.V21 (IO_B5_V21); also elsewhere on the board
GPIO1-1: U1201.V22 (IO_B5_V22); also elsewhere on the board
GPIO1-2: U1201.U21 (IO_B5_U21); also elsewhere on the board
GPIO1-3: U1201.U22 (IO_B5_U22); also elsewhere on the board
GPIO1-4: U1201.D22 (IO_B6_D22); also elsewhere on the board
GPIO1-5: U1201.D21 (IO_B6_D21); also elsewhere on the board
GPIO1-6: U1201.E22 (IO_B6_E22); also elsewhere on the board
GPIO1-7: U1201.E21 (IO_B6_E21); also elsewhere on the board
GPIO1-8: U1201.F22 (IO_B6_F22); also elsewhere on the board
GPIO1-9: U1201.F21 (IO_B6_F21); also elsewhere on the board
GPIO1-10: U1201.H22 (IO_B6_H22); also elsewhere on the board
GPIO1-11: U1201.H21 (IO_B6_H21); also elsewhere on the board
GPIO1-12: U1201.J22 (IO_B6_J22); also elsewhere on the board
GPIO1-13: U1201.J21 (IO_B6_J21); also elsewhere on the board
GPIO1-14: U1201.M21 (IO_B5_M21); also elsewhere on the board
GPIO1-15: U1201.M22 (IO_B5_M22); also elsewhere on the board
nRF_CE: U1201.C22 (IO_B6_C22); also elsewhere on the board
nRF_CSn: U1201.C21 (IO_B6_C21); also elsewhere on the board
nRF_SCLK: U1201.B22 (IO_B6_B22); also elsewhere on the board

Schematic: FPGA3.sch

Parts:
C1401: 100nF; L_0402_1005Metric
R1401, R1402, R1403, R1404: 10k; R_0402_1005Metric
R1405: 10K; R_0402_1005Metric
TP1401, TP1402, TP1403: TestPoint_Small; TestPoint_Pad_D1.0mm
U1201: 10CL040_F484; BGA484C100P22X22_2300X2300X200
X1401: SiT2001BI-S2-33E-50.000000G; SOT-23-5

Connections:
+3V3: C1401.1, R1401.2, R1402.2, R1403.2, R1405.1, X1401.4 (VDD); also elsewhere on the board
/FPGA Part 3/CONF_DONE: R1401.1, TP1401.1, U1201.M18 (CONF_DONE_B6_M18/CONF_DONE)
/FPGA Part 3/CRC_ERROR: TP1403.1, U1201.L21 (IO_B6_L21/CRC_ERROR)
/FPGA Part 3/FPGA-CLOCK-50: U1201.T1 (CLK3_B2_T1/DIFFCLK_1N), X1401.5 (OUT)
/FPGA Part 3/INIT_DONE: TP1402.1, U1201.L22 (IO_B6_L22/INIT_DONE)
/FPGA Part 3/~CE: R1404.2, U1201.L3 (NCE_B1_L3/NCE)
/FPGA Part 3/~CONFIG: R1402.1, U1201.K5 (NCONFIG_B1_K5/NCONFIG)
/FPGA Part 3/~STATUS: R1403.1, U1201.K6 (NSTATUS_B1_K6/NSTATUS)
Conf_flash_CLK: U1201.K2 (IO_B1_K2/DCLK); also elsewhere on the board
Conf_flash_CSn: U1201.E2 (IO_B1_E2/FLASH_NCE,NCSO); also elsewhere on the board
Conf_flash_MISO: U1201.K1 (IO_B1_K1/DATA0); also elsewhere on the board
Conf_flash_MOSI: U1201.D1 (IO_B1_D1/DATA1,ASDO); also elsewhere on the board
GND: C1401.2, R1404.1, U1201.L18 (MSEL1_B6_L18/MSEL1), X1401.1 (GND); also elsewhere on the board
GPIO2-0: U1201.B6 (IO_B8_B6); also elsewhere on the board
GPIO2-1: U1201.A6 (IO_B8_A6); also elsewhere on the board
GPIO2-2: U1201.B7 (IO_B8_B7/DATA4); also elsewhere on the board
GPIO2-3: U1201.A7 (IO_B8_A7); also elsewhere on the board
GPIO2-4: U1201.B18 (IO_B7_B18); also elsewhere on the board
GPIO2-5: U1201.A18 (IO_B7_A18); also elsewhere on the board
GPIO2-6: U1201.B17 (IO_B7_B17); also elsewhere on the board
GPIO2-7: U1201.A17 (IO_B7_A17); also elsewhere on the board
GPIO2-8: U1201.B16 (IO_B7_B16); also elsewhere on the board
GPIO2-9: U1201.A16 (IO_B7_A16); also elsewhere on the board
GPIO2-10: U1201.B15 (IO_B7_B15); also elsewhere on the board
GPIO2-11: U1201.A15 (IO_B7_A15); also elsewhere on the board
GPIO2-12: U1201.B14 (IO_B7_B14); also elsewhere on the board
GPIO2-13: U1201.A14 (IO_B7_A14); also elsewhere on the board
GPIO2-14: U1201.B13 (IO_B7_B13); also elsewhere on the board
GPIO2-15: U1201.A13 (IO_B7_A13); also elsewhere on the board
JTAG_TCK: U1201.L2 (TCK_B1_L2/TCK); also elsewhere on the board
JTAG_TDI: U1201.L5 (TDI_B1_L5/TDI); also elsewhere on the board
JTAG_TDO: U1201.L4 (TDO_B1_L4/TDO); also elsewhere on the board
JTAG_TMS: U1201.L1 (TMS_B1_L1/TMS); also elsewhere on the board
unnamed: R1405.2, X1401.3 (OE)
VCCA: U1201.K20 (MSEL3_B6_K20/MSEL3), U1201.L17 (MSEL2_B6_L17/MSEL2), U1201.M17 (MSEL0_B6_M17/MSEL0); also elsewhere on the board
nRF_IRQ: U1201.B20 (IO_B7_B20/PLL2_CLKOUTP); also elsewhere on the board
nRF_MISO: U1201.A19 (IO_B7_A19/RDN4); also elsewhere on the board
nRF_MOSI: U1201.A20 (IO_B7_A20/PLL2_CLKOUTN); also elsewhere on the board

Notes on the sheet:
Clock Generator

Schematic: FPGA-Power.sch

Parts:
C1501, C1502, C1503, C1504, C1505, C1506, C1507, C1508, C1521, C1528, C1534, C1540: 100nF; L_0402_1005Metric
C1509, C1510, C1511, C1512, C1513, C1514, C1515, C1516, C1519, C1526, C1532, C1538: 4.7uF; C_0402_1005Metric
C1517, C1524, C1531, C1537: 100nF; C_0402_1005Metric
C1518, C1525: 47uF; C_0805_2012Metric
C1520, C1527, C1533, C1539: 1uF; L_0402_1005Metric
C1522, C1529, C1535, C1541: 22nF; L_0402_1005Metric
C1523, C1530, C1536, C1542: 10nF; L_0402_1005Metric
FB1501, FB1502: 180R 1.5A; L_0603_1608Metric
U1201: 10CL040_F484; BGA484C100P22X22_2300X2300X200

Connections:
+1V2: C1518.1, C1519.1, C1520.1, C1521.1, C1522.1, C1523.1, C1525.1, C1526.1, C1527.1, C1528.1, C1529.1, C1530.1, C1532.1, C1533.1, C1534.1, C1535.1, C1536.1, C1538.1, C1539.1, C1540.1, C1541.1, C1542.1, FB1502.1, U1201.G12 (VCCINT_G12), U1201.H9 (VCCINT_H9), U1201.J10 (VCCINT_J10), U1201.J11 (VCCINT_J11), U1201.J12 (VCCINT_J12), U1201.J13 (VCCINT_J13), U1201.J14 (VCCINT_J14), U1201.J16 (VCCINT_J16), U1201.K9 (VCCINT_K9), U1201.K14 (VCCINT_K14), U1201.K15 (VCCINT_K15), U1201.L9 (VCCINT_L9), U1201.L14 (VCCINT_L14), U1201.L16 (VCCINT_L16), U1201.M9 (VCCINT_M9), U1201.M14 (VCCINT_M14), U1201.M15 (VCCINT_M15), U1201.N9 (VCCINT_N9), U1201.N14 (VCCINT_N14), U1201.P9 (VCCINT_P9), U1201.P10 (VCCINT_P10), U1201.P11 (VCCINT_P11), U1201.P12 (VCCINT_P12), U1201.P13 (VCCINT_P13), U1201.P14 (VCCINT_P14), U1201.R8 (VCCINT_R8), U1201.R10 (VCCINT_R10), U1201.R12 (VCCINT_R12); also elsewhere on the board
+2V5: FB1501.1; also elsewhere on the board
+3V3: C1501.1, C1502.1, C1503.1, C1504.1, C1505.1, C1506.1, C1507.1, C1508.1, C1509.1, C1510.1, C1511.1, C1512.1, C1513.1, C1514.1, C1515.1, C1516.1, U1201.A2 (VCCIO8_A2), U1201.A21 (VCCIO7_A21), U1201.AA6 (VCCIO3_AA6), U1201.AB2 (VCCIO3_AB2), U1201.AB21 (VCCIO4_AB21), U1201.D4 (VCCIO1_D4), U1201.D5 (VCCIO8_D5), U1201.D9 (VCCIO8_D9), U1201.D11 (VCCIO8_D11), U1201.D12 (VCCIO7_D12), U1201.D14 (VCCIO7_D14), U1201.D16 (VCCIO7_D16), U1201.D18 (VCCIO7_D18), U1201.E8 (VCCIO8_E8), U1201.E19 (VCCIO6_E19), U1201.F4 (VCCIO1_F4), U1201.G19 (VCCIO6_G19), U1201.H4 (VCCIO1_H4), U1201.J20 (VCCIO6_J20), U1201.K4 (VCCIO1_K4), U1201.L19 (VCCIO6_L19), U1201.N4 (VCCIO2_N4), U1201.P18 (VCCIO5_P18), U1201.R4 (VCCIO2_R4), U1201.T19 (VCCIO5_T19), U1201.U4 (VCCIO2_U4), U1201.V19 (VCCIO5_V19), U1201.W4 (VCCIO2_W4), U1201.W5 (VCCIO3_W5), U1201.W9 (VCCIO3_W9), U1201.W11 (VCCIO3_W11), U1201.W12 (VCCIO4_W12), U1201.W16 (VCCIO4_W16), U1201.W18 (VCCIO4_W18), U1201.Y14 (VCCIO4_Y14), U1201.Y19 (VCCIO5_Y19); also elsewhere on the board
GND: C1501.2, C1502.2, C1503.2, C1504.2, C1505.2, C1506.2, C1507.2, C1508.2, C1509.2, C1510.2, C1511.2, C1512.2, C1513.2, C1514.2, C1515.2, C1516.2, C1517.2, C1518.2, C1519.2, C1520.2, C1521.2, C1522.2, C1523.2, C1524.2, C1525.2, C1526.2, C1527.2, C1528.2, C1529.2, C1530.2, C1531.2, C1532.2, C1533.2, C1534.2, C1535.2, C1536.2, C1537.2, C1538.2, C1539.2, C1540.2, C1541.2, C1542.2, U1201.A1 (GND_A1), U1201.A22 (GND_A22), U1201.AA1 (GND_AA1), U1201.AA2 (GND_AA2), U1201.AA17 (GND_AA17), U1201.AB1 (GND_AB1), U1201.AB6 (GND_AB6), U1201.AB17 (GND_AB17), U1201.AB22 (GND_AB22), U1201.C1 (GND_C1), U1201.C2 (GND_C2), U1201.C5 (GND_C5), U1201.C9 (GND_C9), U1201.C11 (GND_C11), U1201.C12 (GND_C12), U1201.C14 (GND_C14), U1201.C16 (GND_C16), U1201.C18 (GND_C18), U1201.D3 (GND_D3), U1201.D8 (GND_D8), U1201.E18 (GNDA2_E18), U1201.E20 (GND_E20), U1201.F3 (GND_F3), U1201.F5 (GNDA3_F5), U1201.F12 (GND_F12), U1201.G20 (GND_G20), U1201.H3 (GND_H3), U1201.H12 (GND_H12), U1201.H13 (GND_H13), U1201.J9 (GND_J9), U1201.J15 (GND_J15), U1201.J19 (GND_J19), U1201.K3 (GND_K3), U1201.K10 (GND_K10), U1201.K11 (GND_K11), U1201.K12 (GND_K12), U1201.K13 (GND_K13), U1201.K16 (GND_K16), U1201.L10 (GND_L10), U1201.L11 (GND_L11), U1201.L12 (GND_L12), U1201.L13 (GND_L13), U1201.L15 (GND_L15), U1201.L20 (GND_L20), U1201.M10 (GND_M10), U1201.M11 (GND_M11), U1201.M12 (GND_M12), U1201.M13 (GND_M13), U1201.N3 (GND_N3), U1201.N10 (GND_N10), U1201.N11 (GND_N11), U1201.N12 (GND_N12), U1201.N13 (GND_N13), U1201.N15 (GND_N15), U1201.P8 (GND_P8), U1201.P19 (GND_P19), U1201.R3 (GND_R3), U1201.R9 (GND_R9), U1201.R11 (GND_R11), U1201.R13 (GND_R13), U1201.T20 (GND_T20), U1201.U3 (GND_U3), U1201.U5 (GNDA1_U5), U1201.V18 (GNDA4_V18), U1201.V20 (GND_V20), U1201.W3 (GND_W3), U1201.Y5 (GND_Y5), U1201.Y9 (GND_Y9), U1201.Y11 (GND_Y11), U1201.Y12 (GND_Y12), U1201.Y15 (GND_Y15), U1201.Y16 (GND_Y16), U1201.Y18 (GND_Y18), U1201.Y20 (GND_Y20); also elsewhere on the board
VCCA: C1517.1, C1524.1, FB1501.2, U1201.F18 (VCCA2_F18), U1201.G6 (VCCA3_G6), U1201.T6 (VCCA1_T6), U1201.U18 (VCCA4_U18); also elsewhere on the board
VCCD_PLL: C1531.1, C1537.1, FB1502.2, U1201.E17 (VCCD_PLL2_E17), U1201.F6 (VCCD_PLL3_F6), U1201.U6 (VCCD_PLL1_U6), U1201.V17 (VCCD_PLL4_V17)

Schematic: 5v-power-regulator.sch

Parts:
C301: 10uF 25v; C_0805_2012Metric
C302: 100nF 25v; C_0805_2012Metric
C303, C304: 22uF 25v; C_0805_2012Metric
L301: 4.7uH 2.6ADC; L_5030_TAIYO_YUDEN
U301: AP63205WU-7; SOT95P280X100-6N

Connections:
+10V: C301.1, U301.2 (EN), U301.3 (VIN); also elsewhere on the board
/Power Distribution and Estimation/5v Power regulator/5v_BST: C302.1, U301.6 (BST)
/Power Distribution and Estimation/5v Power regulator/5v_SW: C302.2, L301.1, U301.5 (SW)
/Power Distribution and Estimation/5v-regulator: C303.1, C304.1, L301.2, U301.1 (FB); also elsewhere on the board
GND: C301.2, C303.2, C304.2, U301.4 (GND); also elsewhere on the board

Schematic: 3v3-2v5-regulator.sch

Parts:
C401: 10uF; C_0805_2012Metric
C402, C403: 1uF; C_0603_1608Metric
C404: 22uF; C_0805_2012Metric
L401: 1uH; L_3012_TDK
U401: SC189ZSKTRT; SOT95P280X145-5N
U402: NCP115ASN250T2G; SOT95P275X110-5N

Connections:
+2V5: C403.1, U402.5 (OUT); also elsewhere on the board
+3V3: C402.1, C404.1, L401.2, U401.4 (VOUT), U402.1 (IN), U402.3 (EN); also elsewhere on the board
+5V: C401.1, U401.1 (VIN), U401.3 (EN); also elsewhere on the board
/Power Distribution and Estimation/3v3 and 2v5 power regulators/3v3_LX: L401.1, U401.5 (LX)
GND: C401.2, C402.2, C403.2, C404.2, U401.2 (GND), U402.2 (GND), U402.4 (N/C); also elsewhere on the board

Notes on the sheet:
3v3 Regulator (top)
2v5 LDO (top)

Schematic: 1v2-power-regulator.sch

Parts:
C501: 10uF; C_0805_2012Metric
C502: 100nF; C_0402_1005Metric
C503: 100pF; C_0402_1005Metric
C504, C505: 22uF; C_0805_2012Metric
L501: 2.2uH; L_4018_Bourns
R501: 30k9; R_0402_1005Metric
R502: 62k; R_0402_1005Metric
U501: AP63200WU-7; SOT95P280X100-6N

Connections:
+1V2: C503.1, C504.1, C505.1, L501.2, R501.1; also elsewhere on the board
+5V: C501.1, U501.2 (EN), U501.3 (VIN); also elsewhere on the board
/Power Distribution and Estimation/1v2 power regulator/1v2_BST: C502.1, U501.6 (BST)
/Power Distribution and Estimation/1v2 power regulator/1v2_FB: C503.2, R501.2, R502.1, U501.1 (FB)
/Power Distribution and Estimation/1v2 power regulator/1v2_SW: C502.2, L501.1, U501.5 (SW)
GND: C501.2, C504.2, C505.2, R502.2, U501.4 (GND); also elsewhere on the board

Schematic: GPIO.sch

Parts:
J1001, J1003: Conn_02x10; PinHeader_2x10_P2.54mm_Vertical
J1002: Conn_02x07; PinHeader_2x07_P2.54mm_Vertical
J1004: Conn_02x05; PinHeader_2x05_P2.54mm_Vertical
R1001, R1002: 10k; R_0402_1005Metric
R1003: 1k; R_0402_1005Metric

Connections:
5v_GPIO_5v_0: J1002.3; also elsewhere on the board
5v_GPIO_5v_1: J1002.4; also elsewhere on the board
5v_GPIO_5v_2: J1002.5; also elsewhere on the board
5v_GPIO_5v_3: J1002.6; also elsewhere on the board
+3V3: J1001.1, J1001.2, J1003.1, J1003.2; also elsewhere on the board
+5V: J1002.1, J1002.2; also elsewhere on the board
ADC_CH2: J1002.12; also elsewhere on the board
ADC_CH3: J1002.11; also elsewhere on the board
ADC_CH4: J1002.10; also elsewhere on the board
ADC_CH5: J1002.9; also elsewhere on the board
ADC_CH6: J1002.8; also elsewhere on the board
ADC_CH7: J1002.7; also elsewhere on the board
GND: J1001.19, J1001.20, J1002.14, J1003.19, J1003.20, J1004.2, J1004.10, R1003.2; also elsewhere on the board
GNDA: J1002.13; also elsewhere on the board
GPIO1-0: J1001.3; also elsewhere on the board
GPIO1-1: J1001.4; also elsewhere on the board
GPIO1-2: J1001.5; also elsewhere on the board
GPIO1-3: J1001.6; also elsewhere on the board
GPIO1-4: J1001.7; also elsewhere on the board
GPIO1-5: J1001.8; also elsewhere on the board
GPIO1-6: J1001.9; also elsewhere on the board
GPIO1-7: J1001.10; also elsewhere on the board
GPIO1-8: J1001.11; also elsewhere on the board
GPIO1-9: J1001.12; also elsewhere on the board
GPIO1-10: J1001.13; also elsewhere on the board
GPIO1-11: J1001.14; also elsewhere on the board
GPIO1-12: J1001.15; also elsewhere on the board
GPIO1-13: J1001.16; also elsewhere on the board
GPIO1-14: J1001.17; also elsewhere on the board
GPIO1-15: J1001.18; also elsewhere on the board
GPIO2-0: J1003.3; also elsewhere on the board
GPIO2-1: J1003.4; also elsewhere on the board
GPIO2-2: J1003.5; also elsewhere on the board
GPIO2-3: J1003.6; also elsewhere on the board
GPIO2-4: J1003.7; also elsewhere on the board
GPIO2-5: J1003.8; also elsewhere on the board
GPIO2-6: J1003.9; also elsewhere on the board
GPIO2-7: J1003.10; also elsewhere on the board
GPIO2-8: J1003.11; also elsewhere on the board
GPIO2-9: J1003.12; also elsewhere on the board
GPIO2-10: J1003.13; also elsewhere on the board
GPIO2-11: J1003.14; also elsewhere on the board
GPIO2-12: J1003.15; also elsewhere on the board
GPIO2-13: J1003.16; also elsewhere on the board
GPIO2-14: J1003.17; also elsewhere on the board
GPIO2-15: J1003.18; also elsewhere on the board
JTAG_TCK: J1004.1, R1003.1; also elsewhere on the board
JTAG_TDI: J1004.9, R1001.2; also elsewhere on the board
JTAG_TDO: J1004.3; also elsewhere on the board
JTAG_TMS: J1004.5, R1002.2; also elsewhere on the board
VCCA: J1004.4, R1001.1, R1002.1; also elsewhere on the board

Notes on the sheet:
JTAG (top)
Sheet IO
5 Volt GPIO and ADC connector
3.3 Volt GPIO Connectors

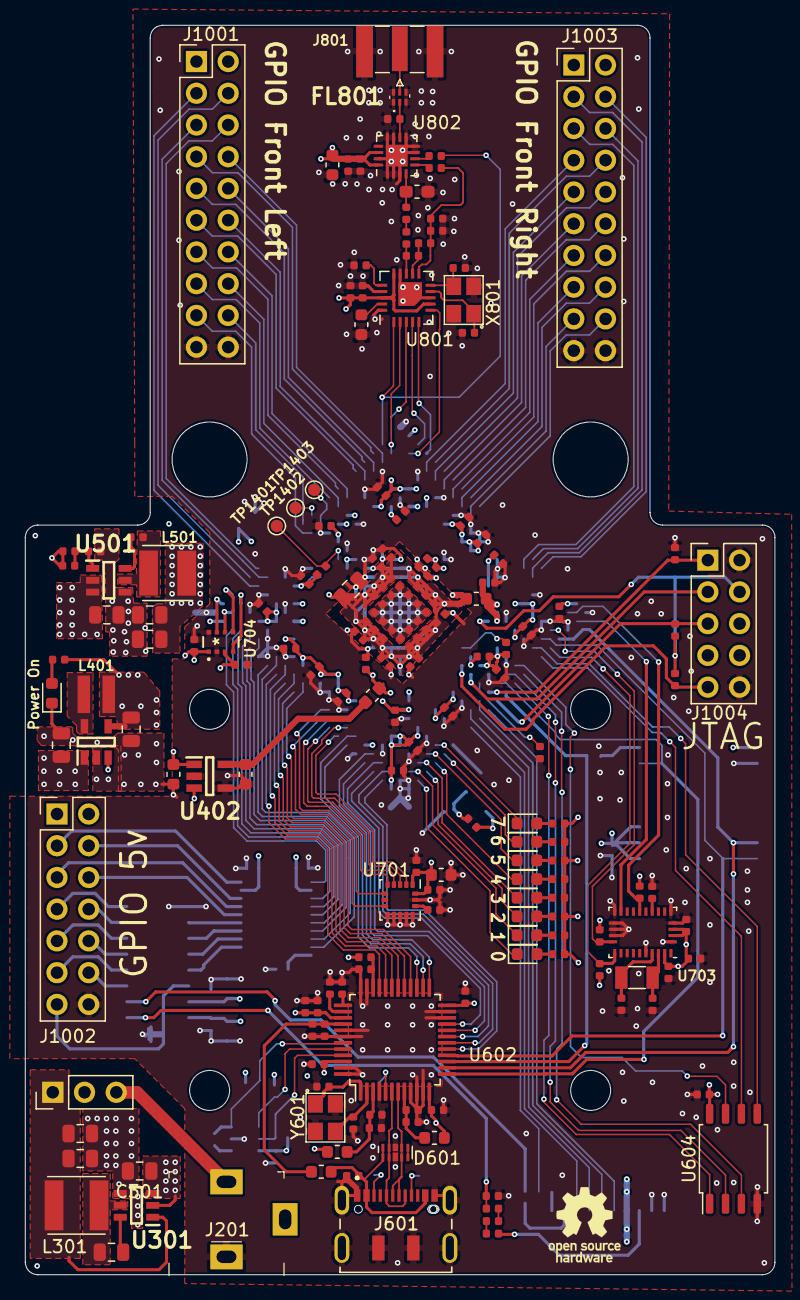
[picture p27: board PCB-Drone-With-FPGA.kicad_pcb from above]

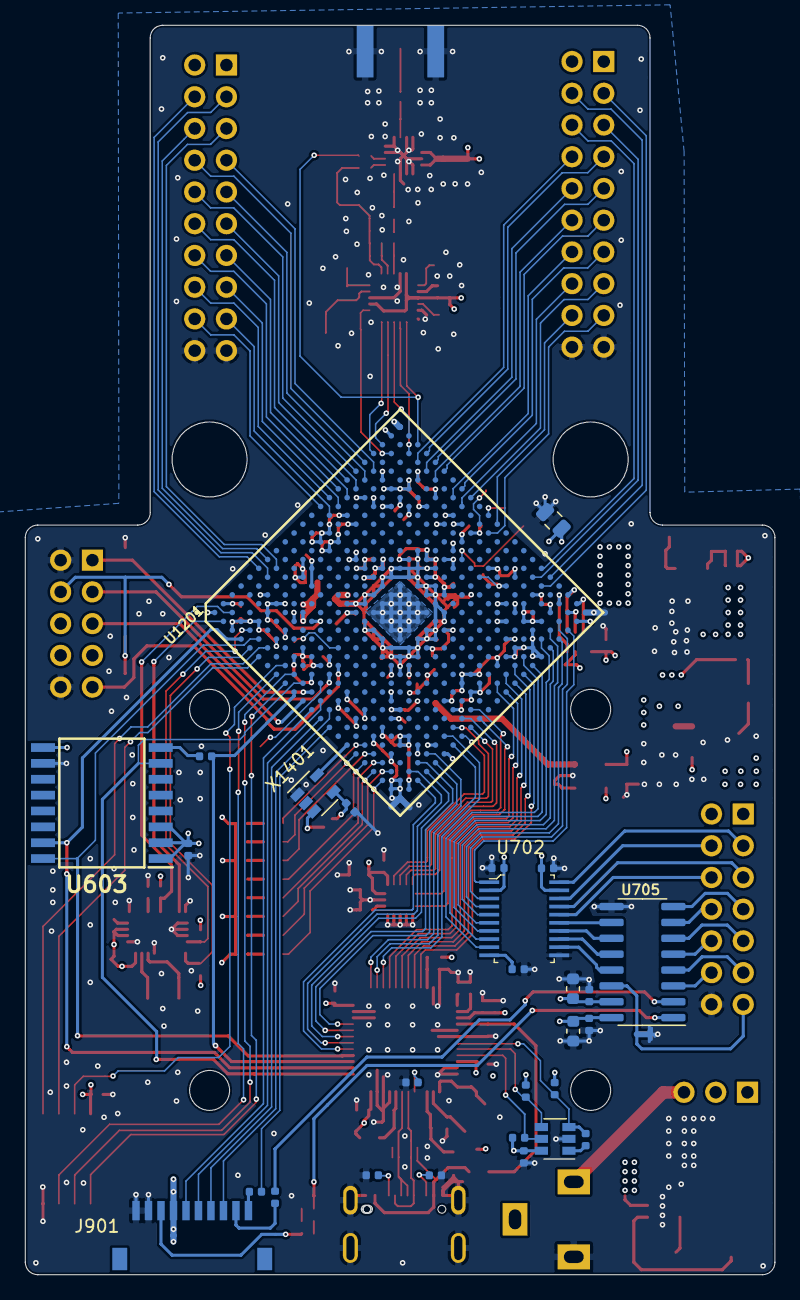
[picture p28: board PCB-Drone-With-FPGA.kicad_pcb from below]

Board: 4 copper layers, 60.0 x 100.0 mm, 210 parts (29 on the bottom side), 195 nets.

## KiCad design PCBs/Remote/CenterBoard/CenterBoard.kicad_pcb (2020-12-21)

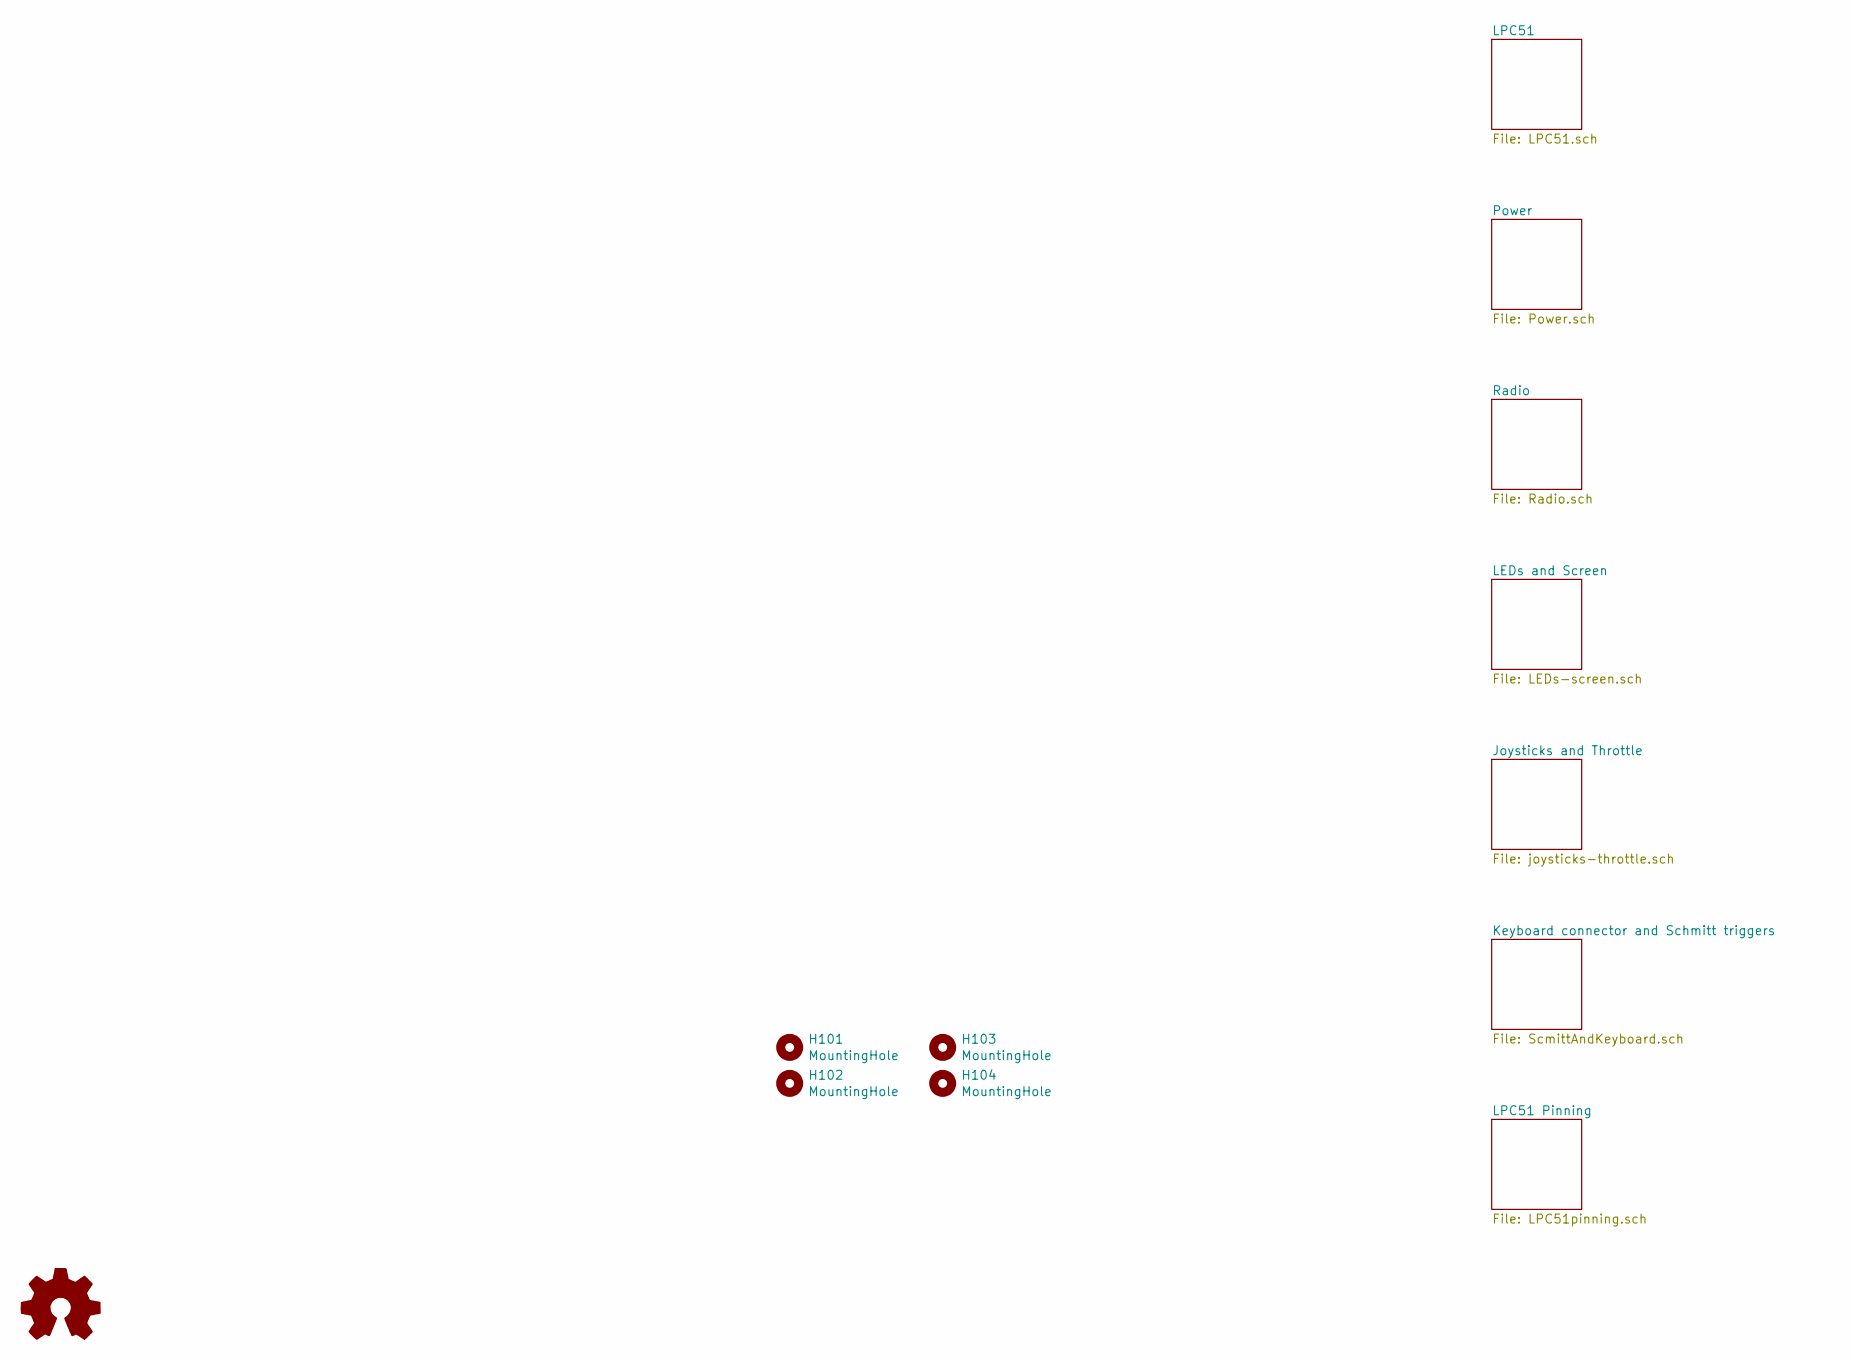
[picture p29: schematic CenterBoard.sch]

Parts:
H101, H102, H103, H104: MountingHole; MountingHole_3.2mm_M3_ISO7380
LOGO101: Logo_Open_Hardware_Small; OSHW-Logo_5.7x6mm_SilkScreen

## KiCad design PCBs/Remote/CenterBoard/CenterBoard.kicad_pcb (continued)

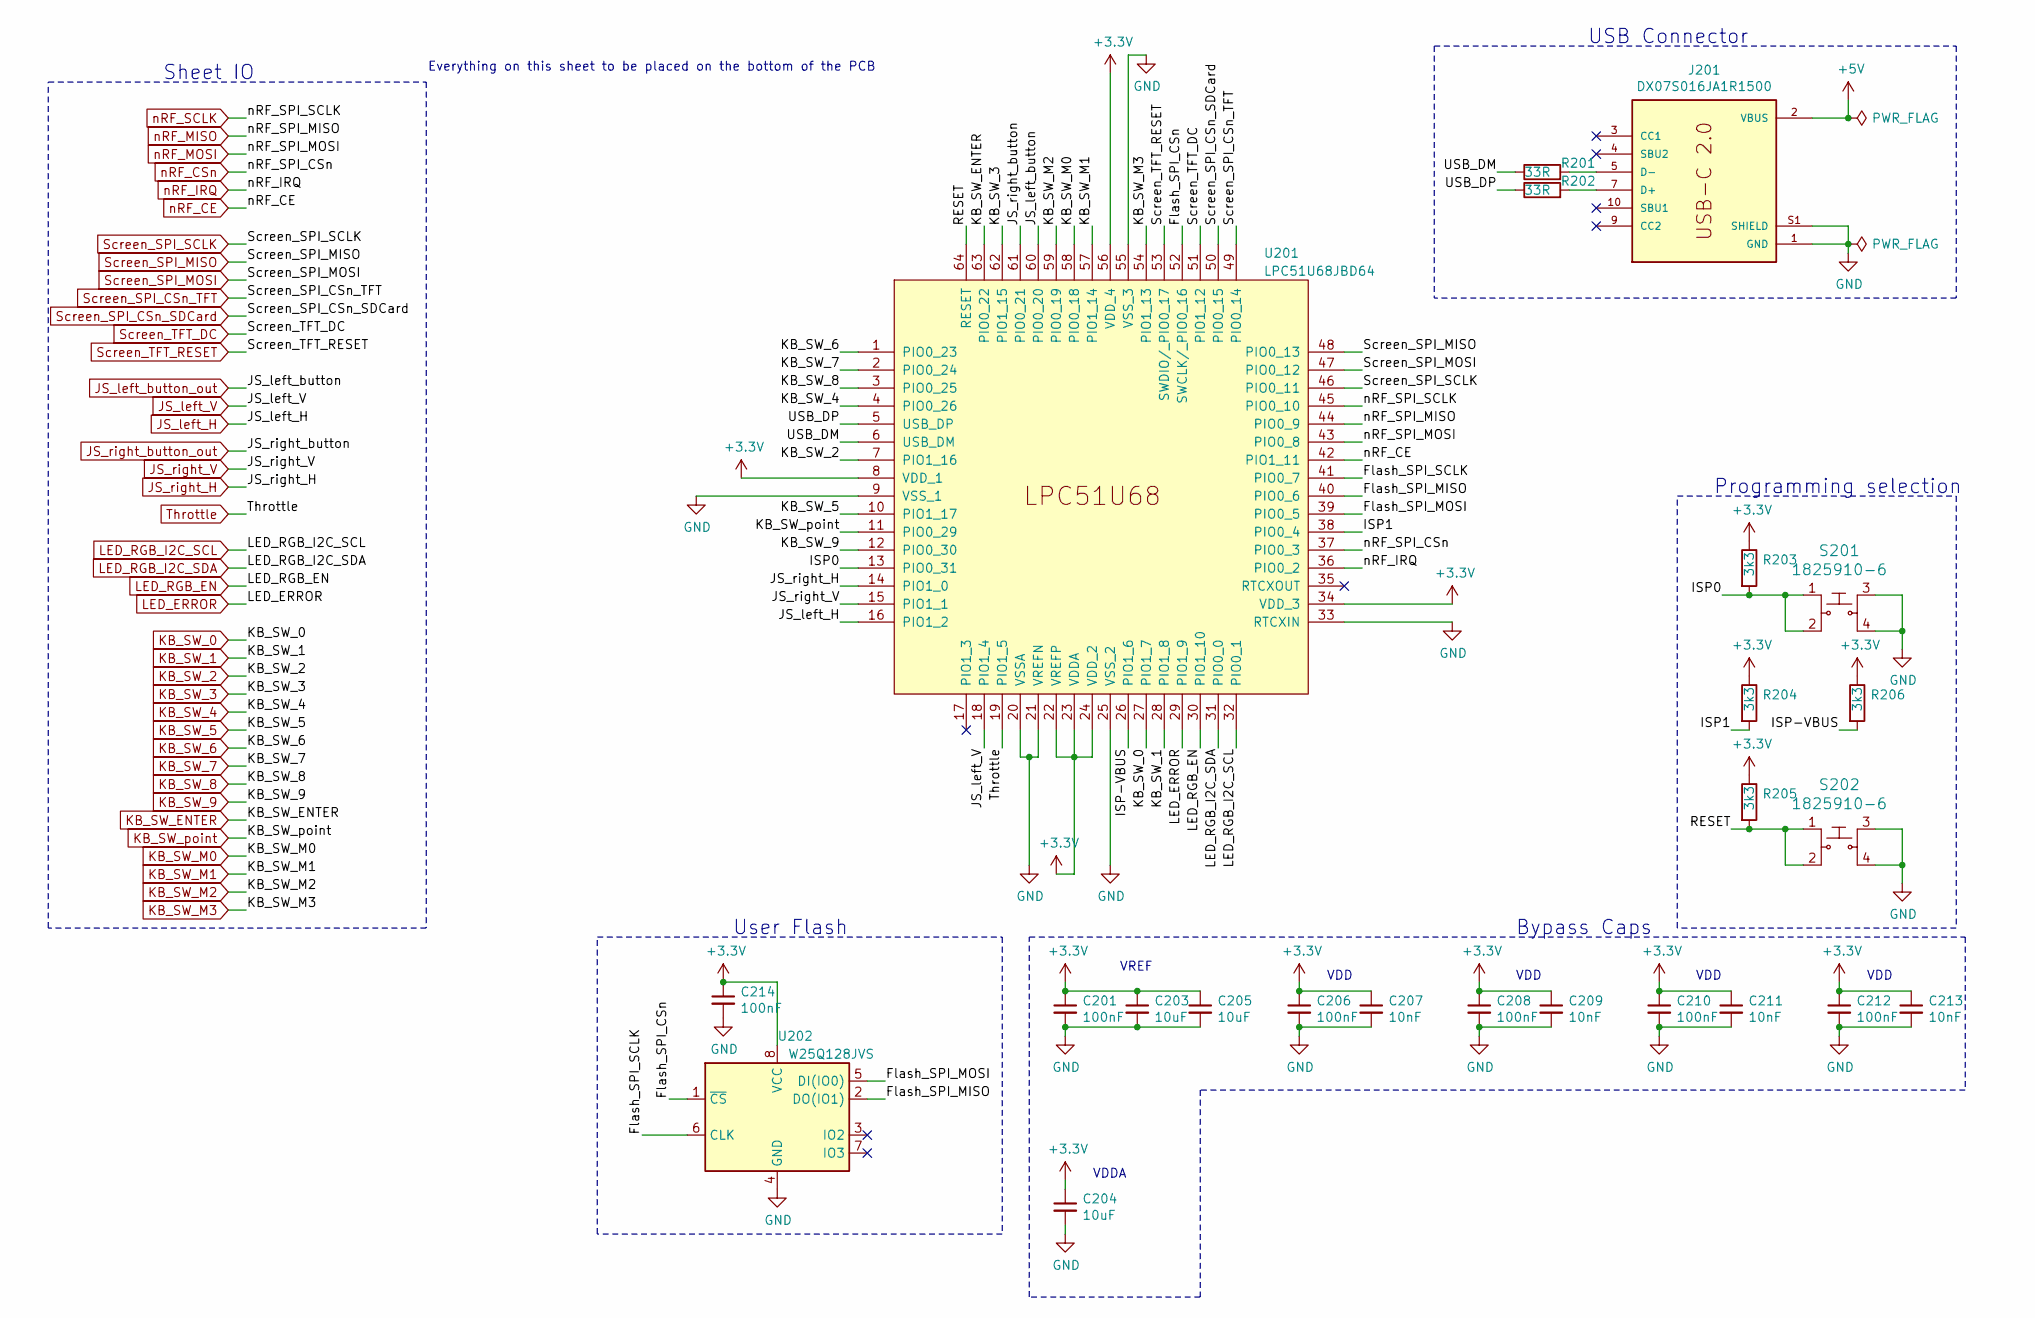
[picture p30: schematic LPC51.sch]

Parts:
C201, C206, C208, C210, C212, C214: 100nF; C_0402_1005Metric; LCSC C1525
C203, C204, C205: 10uF; C_0402_1005Metric; LCSC C15525
C207, C209, C211, C213: 10nF; C_0402_1005Metric; LCSC C15195
J201: DX07S016JA1R1500; JAE_DX07S016JA1R1500; DigiKey 670-DX07S016JA1R1500CT-ND
R201, R202: 33R; R_0603_1608Metric_Pad1.05x0.95mm_HandSolder; DigiKey P123790CT-ND
R203, R204, R205, R206: 3k3; R_0603_1608Metric_Pad1.05x0.95mm_HandSolder; LCSC C22978
S201, S202: 1825910-6; Switch_Tactile_THT_6x6mm; DigiKey 450-1650-ND
U201: LPC51U68JBD64; LQFP-64_10x10mm_P0.5mm; DigiKey 568-13909-ND
U202: W25Q128JVS; SOIC-8_5.23x5.23mm_P1.27mm; LCSC C97521

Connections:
+5V: J201.2 (VBUS), J201.11 (VBUS); also elsewhere on the board
/LPC51/Flash_SPI_CSn: U201.52 (SWCLK/_PIO0_16), U202.1 (~CS)
/LPC51/Flash_SPI_MISO: U201.40 (PIO0_6), U202.2 (DO(IO1))
/LPC51/Flash_SPI_MOSI: U201.39 (PIO0_5), U202.5 (DI(IO0))
/LPC51/Flash_SPI_SCLK: U201.41 (PIO0_7), U202.6 (CLK)
/LPC51/ISP0: R203.2, S201.1, S201.2, U201.13 (PIO0_31)
/LPC51/ISP1: R204.2, U201.38 (PIO0_4)
/LPC51/ISP-VBUS: R206.2, U201.26 (PIO1_6)
/LPC51/RESET: R205.2, S202.1, S202.2, U201.64 (RESET)
/LPC51/USB_DM: R201.1, U201.6 (USB_DM)
/LPC51/USB_DP: R202.1, U201.5 (USB_DP)
GND: C201.2, C203.2, C204.2, C205.2, C206.2, C207.2, C208.2, C209.2, C210.2, C211.2, C212.2, C213.2, C214.2, J201.1 (GND), J201.12 (GND), J201.S1 (SHIELD), J201.S2 (SHIELD), J201.S3 (SHIELD), J201.S4 (SHIELD), J201.S5 (SHIELD), J201.S6 (SHIELD), S201.3, S201.4, S202.3, S202.4, U201.9 (VSS_1), U201.20 (VSSA), U201.21 (VREFN), U201.25 (VSS_2), U201.33 (RTCXIN), U201.55 (VSS_3), U202.4 (GND); also elsewhere on the board
JS_left_H: U201.16 (PIO1_2); also elsewhere on the board
JS_left_V: U201.18 (PIO1_4); also elsewhere on the board
JS_left_button_out: U201.60 (PIO0_20); also elsewhere on the board
JS_right_H: U201.14 (PIO1_0); also elsewhere on the board
JS_right_V: U201.15 (PIO1_1); also elsewhere on the board
JS_right_button_out: U201.61 (PIO0_21); also elsewhere on the board
KB_SW_0: U201.27 (PIO1_7); also elsewhere on the board
KB_SW_1: U201.28 (PIO1_8); also elsewhere on the board
KB_SW_2: U201.7 (PIO1_16); also elsewhere on the board
KB_SW_3: U201.62 (PIO1_15); also elsewhere on the board
KB_SW_4: U201.4 (PIO0_26); also elsewhere on the board
KB_SW_5: U201.10 (PIO1_17); also elsewhere on the board
KB_SW_6: U201.1 (PIO0_23); also elsewhere on the board
KB_SW_7: U201.2 (PIO0_24); also elsewhere on the board
KB_SW_8: U201.3 (PIO0_25); also elsewhere on the board
KB_SW_9: U201.12 (PIO0_30); also elsewhere on the board
KB_SW_ENTER: U201.63 (PIO0_22); also elsewhere on the board
KB_SW_M0: U201.58 (PIO0_18); also elsewhere on the board
KB_SW_M1: U201.57 (PIO1_14); also elsewhere on the board
KB_SW_M2: U201.59 (PIO0_19); also elsewhere on the board
KB_SW_M3: U201.54 (PIO1_13); also elsewhere on the board
KB_SW_point: U201.11 (PIO0_29); also elsewhere on the board
LED_ERROR: U201.29 (PIO1_9); also elsewhere on the board
LED_RGB_EN: U201.30 (PIO1_10); also elsewhere on the board
LED_RGB_I2C_SCL: U201.32 (PIO0_1); also elsewhere on the board
LED_RGB_I2C_SDA: U201.31 (PIO0_0); also elsewhere on the board
unnamed: J201.5 (D-), J201.8 (D-), R201.2
unnamed: J201.6 (D+), J201.7 (D+), R202.2
Screen_SPI_CSn_SDCard: U201.50 (PIO0_15); also elsewhere on the board
Screen_SPI_CSn_TFT: U201.49 (PIO0_14); also elsewhere on the board
Screen_SPI_MISO: U201.48 (PIO0_13); also elsewhere on the board
Screen_SPI_MOSI: U201.47 (PIO0_12); also elsewhere on the board
Screen_SPI_SCLK: U201.46 (PIO0_11); also elsewhere on the board
Screen_TFT_DC: U201.51 (PIO1_12); also elsewhere on the board
Screen_TFT_RESET: U201.53 (SWDIO/_PIO0_17); also elsewhere on the board
Throttle: U201.19 (PIO1_5); also elsewhere on the board
nRF_CE: U201.42 (PIO1_11); also elsewhere on the board
nRF_CSn: U201.37 (PIO0_3); also elsewhere on the board
nRF_IRQ: U201.36 (PIO0_2); also elsewhere on the board
nRF_MISO: U201.44 (PIO0_9); also elsewhere on the board
nRF_MOSI: U201.43 (PIO0_8); also elsewhere on the board
nRF_SCLK: U201.45 (PIO0_10); also elsewhere on the board

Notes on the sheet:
Bypass Caps
VREF
VDDA
VDD
Programming selection
USB Connector
User Flash
Sheet IO
Everything on this sheet to be placed on the bottom of the PCB


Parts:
C301: 10uF; C_0805_2012Metric; LCSC C15850
C302: 22uF; C_0805_2012Metric; LCSC C45783
L301: 1uH; L_3012_TDK; Mouser 810-VLS3012CX-1R0M-1
U301: SC189ZSKTRT; SOT95P280X145-5N; Mouser Part Number 947-SC189ZSKTRT

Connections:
+5V: C301.1, U301.1 (VIN), U301.3 (EN); also elsewhere on the board
/Power/3v3_LX: L301.1, U301.5 (LX)
GND: C301.2, C302.2, U301.2 (GND); also elsewhere on the board


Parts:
C401: 33nF; C_0603_1608Metric; LCSC C21117
C402: 1nF; C_0402_1005Metric; LCSC C1523
C403, C411: 10nF; C_0402_1005Metric; LCSC C15195
C404, C405: 15pF; C_0402_1005Metric; LCSC C1548
C406: 2.2nF; C_0402_1005Metric; LCSC C1531
C407: 1.5pF; C_0603_1608Metric_Pad1.05x0.95mm_HandSolder; DigiKey 311-1737-1-ND
C408: 1.0pF; C_0603_1608Metric_Pad1.05x0.95mm_HandSolder; DigiKey 1276-1095-1-ND
C409: 4.7pF; C_0402_1005Metric; LCSC C1569
C410: 220pF; C_0402_1005Metric; LCSC C1530
C412: 1uF; C_0402_1005Metric; LCSC C52923
C413: 0.3pF; C_0603_1608Metric_Pad1.05x0.95mm_HandSolder; DigiKey 712-1300-1-ND
FL401: 2450LP14A100T; DigiKey 712-1129-1-ND
J401: SMA; SMA_Samtec_SMA-J-P-X-ST-EM1_EdgeMount; DigiKey CON-SMA-EDGE-S-ND
L401: 8.2nH; L_0402_1005Metric; LCSC C16208
L402: 2.7nH; L_0402_1005Metric; LCSC C27123
L403: 3.9nH; L_0402_1005Metric; LCSC C14033
R401: 22K; R_0402_1005Metric; LCSC C25768
R402, R403: 1K; R_0402_1005Metric; LCSC C11702
U401: nRF24L01P; nRF24L01P-QFN-20-1EP_4x4mm_P0.5mm_EP; DigiKey 1490-1033-1-ND
U402: RFX2401C; QFN-16-1EP_3x3mm_P0.5mm_EP1.75x1.75mm; DigiKey 863-1828-1-ND
X401: 16MHz; Crystal_SMD_3225-4Pin_3.2x2.5mm; LCSC C13738

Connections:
/Radio/RXEN: R403.2, U402.6 (RXEN)
/Radio/TXEN: R402.2, U402.5 (TXEN)
/Radio/VDD_PA: C406.2, C409.2, L402.2, R402.1, U401.11 (VDD_PA)
GND: C401.2, C402.2, C403.2, C404.1, C405.1, C406.1, C408.1, C409.1, C410.1, C411.1, C412.1, C413.1, FL401.1 (GND_1), FL401.3 (GND_2), FL401.4 (GND_3), FL401.6 (GND_4), J401.2 (Ext), R401.2, U401.8 (VSS), U401.14 (VSS), U401.17 (VSS), U401.20 (VSS), U401.21 (EP), U402.1 (N/C_1), U402.2 (GND_1), U402.3 (GND_2), U402.7 (N/C_2), U402.8 (GND_3), U402.9 (GND_4), U402.11 (GND_5), U402.12 (N/C_3), U402.15 (N/C_4), U402.17 (GND_6), X401.2, X401.4; also elsewhere on the board
unnamed: C401.1, U401.19 (DVDD)
unnamed: C404.2, U401.9 (XC2), X401.1
unnamed: C405.2, U401.10 (XC1), X401.3
unnamed: C407.1, C408.2, U402.4 (TXRX)
unnamed: C407.2, L403.2
unnamed: C413.2, FL401.2 (IN), U402.10 (ANT)
unnamed: FL401.5 (OUT), J401.1 (In)
unnamed: L401.1, L402.1, U401.12 (ANT1)
unnamed: L401.2, L403.1, U401.13 (ANT2)
unnamed: R401.1, U401.16 (IREF)
nRF_CE: R403.1, U401.1 (CE); also elsewhere on the board
nRF_CSn: U401.2 (CSN); also elsewhere on the board
nRF_IRQ: U401.6 (IRQ); also elsewhere on the board
nRF_MISO: U401.5 (MISO); also elsewhere on the board
nRF_MOSI: U401.4 (MOSI); also elsewhere on the board
nRF_SCLK: U401.3 (SCK); also elsewhere on the board

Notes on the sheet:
Sheet IO
Impedance matching notes: JLC stackup JLC2313, impedance matching to 50 Ohms; Traces of 5.78mil (0.1468mm) wide.


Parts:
C501: 1uF; C_0805_2012Metric_Pad1.15x1.40mm_HandSolder; LCSC C28323
C502: 100nF; C_0805_2012Metric_Pad1.15x1.40mm_HandSolder; LCSC C49678
C503, C504, C505: 100nF; C_0402_1005Metric; LCSC C1525
D501: User LED RGB 0; LED_RGB_PLCC-6
D502: User LED RGB 1; LED_RGB_PLCC-6
D503: User LED RGB 2; LED_RGB_PLCC-6
D504: User LED RGB 3; LED_RGB_PLCC-6
D505: User LED RGB 4; LED_RGB_PLCC-6
D506: User LED RGB 5; LED_RGB_PLCC-6
D507: User LED RGB 6; LED_RGB_PLCC-6
D508: User LED RGB 7; LED_RGB_PLCC-6
D509: LED_POWERGOOD; LED_0805_2012Metric_Pad1.15x1.40mm_HandSolder; DigiKey 475-1410-1-ND
D510: LED_ERROR; LED_0805_2012Metric_Pad1.15x1.40mm_HandSolder; DigiKey 475-1278-1-ND
D511, D512: BAT54GWJ; D_SOD-123; DigiKey 1727-7328-1-ND
J501: Conn_01x11; PinHeader_1x11_P2.54mm_Vertical_SMD_Pin1Left
POT501: P120PKY25BR10K; Potentiometer_P120PK-Y25BR10K; DigiKey 987-1710-ND
R501, R502: 560R; R_0402_1005Metric; LCSC C25796
R503: 7k32; R_0603_1608Metric_Pad1.05x0.95mm_HandSolder; DigiKey 541-7.32KHCT-ND
R504: 1k; R_0402_1005Metric; LCSC C11702
R505, R506: 4k7; R_0402_1005Metric; LCSC C25900
U501: LP5024; QFN-32-1EP_4x4mm_P0.4mm_EP2.9x2.9mm; DigiKey 296-50814-1-ND
U502: TLC555CDR; SOIC-8_W3.9mm; DigiKey 296-1336-1-ND

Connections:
/LEDs and Screen/3vOut: J501.2
/LEDs and Screen/Backlight_PWM: J501.11, U502.3 (OUT)
/LEDs and Screen/DISCH: D511.1 (K), D512.2 (A), R504.1, U502.7 (DISCH)
/LEDs and Screen/TRIG: C503.1, POT501.2 (S), U502.2 (TRIG), U502.6 (THRES)
GND: C501.2, C502.2, C503.2, C504.2, C505.2, D509.1 (K), D510.1 (K), J501.3, R503.1, U501.25 (ADDR0), U501.26 (ADDR1), U501.33 (GND), U502.1 (GND); also elsewhere on the board
LED_ERROR: R502.2; also elsewhere on the board
LED_RGB_EN: U501.30 (EN); also elsewhere on the board
LED_RGB_I2C_SCL: R506.1, U501.29 (SCL); also elsewhere on the board
LED_RGB_I2C_SDA: R505.1, U501.28 (SDA); also elsewhere on the board
unnamed: C501.1, U501.32 (VCAP)
unnamed: C504.1, U502.5 (CONT)
unnamed: D501.1, U501.3 (OUT2)
unnamed: D501.2, U501.2 (OUT1)
unnamed: D501.3, U501.1 (OUT0)
unnamed: D502.1, U501.6 (OUT5)
unnamed: D502.2, U501.5 (OUT4)
unnamed: D502.3, U501.4 (OUT3)
unnamed: D503.1, U501.9 (OUT8)
unnamed: D503.2, U501.8 (OUT7)
unnamed: D503.3, U501.7 (OUT6)
unnamed: D504.1, U501.12 (OUT11)
unnamed: D504.2, U501.11 (OUT10)
unnamed: D504.3, U501.10 (OUT9)
unnamed: D505.1, U501.15 (OUT14)
unnamed: D505.2, U501.14 (OUT13)
unnamed: D505.3, U501.13 (OUT12)
unnamed: D506.1, U501.18 (OUT17)
unnamed: D506.2, U501.17 (OUT16)
unnamed: D506.3, U501.16 (OUT15)
unnamed: D507.1, U501.21 (OUT20)
unnamed: D507.2, U501.20 (OUT19)
unnamed: D507.3, U501.19 (OUT18)
unnamed: D508.1, U501.24 (OUT23)
unnamed: D508.2, U501.23 (OUT22)
unnamed: D508.3, U501.22 (OUT21)
unnamed: D509.2 (A), R501.1
unnamed: D510.2 (A), R502.1
unnamed: D511.2 (A), POT501.3 (CW)
unnamed: D512.1 (K), POT501.1 (CCW)
unnamed: R503.2, U501.31 (IRF)
Screen_SPI_CSn_SDCard: J501.10; also elsewhere on the board
Screen_SPI_CSn_TFT: J501.7; also elsewhere on the board
Screen_SPI_MISO: J501.5; also elsewhere on the board
Screen_SPI_MOSI: J501.6; also elsewhere on the board
Screen_SPI_SCLK: J501.4; also elsewhere on the board
Screen_TFT_DC: J501.9; also elsewhere on the board
Screen_TFT_RESET: J501.8; also elsewhere on the board

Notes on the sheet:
AdaFruit 1.54" 240x240 pixel TFT display AdaFruit 3787
Green
Red
Sheet IO
Screen with pot (Screen and pot top, rest bottom)
LEDs (top)
Timer circuit to create PWM signal controlled by POT
(resistors bottom)


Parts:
R601: Throttle Potentiometer; PTA6043; DigiKey PTA6043-2015DPB103-ND
R602, R603: 10k; R_0805_2012Metric_Pad1.15x1.40mm_HandSolder; LCSC C17414
U601: Joystick Left; Sparkfun_COM-09032; DigiKey 1568-1526-ND
U602: Joystick Right; Sparkfun_COM-09032; DigiKey 1568-1526-ND

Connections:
GND: R601.3, U601.B2A (SEL-), U601.H3 (H-), U601.S1 (SHIELD), U601.S2 (SHIELD), U601.S3 (SHIELD), U601.S4 (SHIELD), U601.V3 (V-), U602.B2A (SEL-), U602.H3 (H-), U602.S1 (SHIELD), U602.S2 (SHIELD), U602.S3 (SHIELD), U602.S4 (SHIELD), U602.V3 (V-); also elsewhere on the board
JS_left_H: U601.H2 (H); also elsewhere on the board
JS_left_V: U601.V2 (V); also elsewhere on the board
JS_left_button: R602.2, U601.B1A (SEL+); also elsewhere on the board
JS_right_H: U602.H2 (H); also elsewhere on the board
JS_right_V: U602.V2 (V); also elsewhere on the board
JS_right_button: R603.2, U602.B1A (SEL+); also elsewhere on the board
Throttle: R601.2; also elsewhere on the board

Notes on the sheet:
Sheet IO


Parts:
C701, C702, C703: 100nF; C_0402_1005Metric; LCSC C1525
J701: Conn_02x10_Odd_Even; PinHeader_2x10_P2.54mm_Vertical
U701, U702, U703: 74HC14; SOIC-14_3.9x8.7mm_P1.27mm

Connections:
/Keyboard connector and Schmitt triggers/SW_0: J701.6, U701.1
/Keyboard connector and Schmitt triggers/SW_1: J701.5, U701.13
/Keyboard connector and Schmitt triggers/SW_2: J701.10, U702.11
/Keyboard connector and Schmitt triggers/SW_3: J701.14, U702.5
/Keyboard connector and Schmitt triggers/SW_4: J701.4, U701.11
/Keyboard connector and Schmitt triggers/SW_5: J701.7, U701.3
/Keyboard connector and Schmitt triggers/SW_6: J701.11, U702.13
/Keyboard connector and Schmitt triggers/SW_7: J701.3, U701.9
/Keyboard connector and Schmitt triggers/SW_8: J701.8, U701.5
/Keyboard connector and Schmitt triggers/SW_9: J701.12, U702.1
/Keyboard connector and Schmitt triggers/SW_Enter: J701.13, U702.3
/Keyboard connector and Schmitt triggers/SW_M0: J701.16, U703.11
/Keyboard connector and Schmitt triggers/SW_M1: J701.18, U703.5
/Keyboard connector and Schmitt triggers/SW_M2: J701.17, U703.3
/Keyboard connector and Schmitt triggers/SW_M3: J701.15, U703.9
/Keyboard connector and Schmitt triggers/SW_point: J701.9, U702.9
GND: C701.2, C702.2, C703.2, J701.2, J701.20, U701.7 (GND), U702.7 (GND), U703.7 (GND); also elsewhere on the board
JS_left_button: U703.13; also elsewhere on the board
JS_left_button_out: U703.12; also elsewhere on the board
JS_right_button: U703.1; also elsewhere on the board
JS_right_button_out: U703.2; also elsewhere on the board
KB_SW_0: U701.2; also elsewhere on the board
KB_SW_1: U701.12; also elsewhere on the board
KB_SW_2: U702.10; also elsewhere on the board
KB_SW_3: U702.6; also elsewhere on the board
KB_SW_4: U701.10; also elsewhere on the board
KB_SW_5: U701.4; also elsewhere on the board
KB_SW_6: U702.12; also elsewhere on the board
KB_SW_7: U701.8; also elsewhere on the board
KB_SW_8: U701.6; also elsewhere on the board
KB_SW_9: U702.2; also elsewhere on the board
KB_SW_ENTER: U702.4; also elsewhere on the board
KB_SW_M0: U703.10; also elsewhere on the board
KB_SW_M1: U703.6; also elsewhere on the board
KB_SW_M2: U703.4; also elsewhere on the board
KB_SW_M3: U703.8; also elsewhere on the board
KB_SW_point: U702.8; also elsewhere on the board

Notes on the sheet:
Sheet IO
Everything on this sheet on the bottom of the PCB


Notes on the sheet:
By Pin
By Function

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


Board: 4 copper layers, 100.0 x 100.0 mm, 96 parts (72 on the bottom side), 121 nets.

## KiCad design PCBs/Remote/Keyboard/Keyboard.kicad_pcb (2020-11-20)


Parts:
C101, C102, C103, C104, C105, C106, C107, C108, C109, C110, C111, C112, C113, C114, C115, C116: 100nF; C_0805_2012Metric_Pad1.15x1.40mm_HandSolder; LCSC C49678
J101: Conn_02x10_Odd_Even; PinHeader_2x10_P2.54mm_Vertical
LOGO101: Logo_Open_Hardware_Small; OSHW-Logo_5.7x6mm_SilkScreen
R101, R102, R103, R104, R105, R106, R107, R108, R109, R110, R111, R112, R113, R114, R115, R116, R117, R118, R119, R120, R121, R122, R123, R124, R125, R126, R127, R128, R129, R130, R131, R132: 10K; R_0805_2012Metric_Pad1.15x1.40mm_HandSolder; LCSC C17414
SW101, SW102, SW103, SW104, SW105, SW106, SW107, SW108, SW109, SW110, SW111, SW112, SW113, SW114, SW115, SW116: MX1A_C1; SW_Cherry_MX_1.00u_PCB; DigiKey CH310-ND

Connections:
+3V3: J101.1, J101.19, R101.1, R102.1, R103.1, R104.1, R109.1, R110.1, R111.1, R112.1, R117.1, R118.1, R119.1, R120.1, R125.1, R126.1, R127.1, R128.1
/SW_0: C104.1, J101.6, R108.1
/SW_1: C103.1, J101.5, R107.1
/SW_2: C107.1, J101.10, R115.1
/SW_3: C111.1, J101.14, R123.1
/SW_4: C102.1, J101.4, R106.1
/SW_5: C106.1, J101.7, R114.1
/SW_6: C110.1, J101.11, R122.1
/SW_7: C101.1, J101.3, R105.1
/SW_8: C105.1, J101.8, R113.1
/SW_9: C109.1, J101.12, R121.1
/SW_Enter: C112.1, J101.13, R124.1
/SW_M0: C113.1, J101.16, R129.1
/SW_M1: C114.1, J101.18, R130.1
/SW_M2: C115.1, J101.17, R131.1
/SW_M3: C116.1, J101.15, R132.1
/SW_point: C108.1, J101.9, R116.1
GND: C101.2, C102.2, C103.2, C104.2, C105.2, C106.2, C107.2, C108.2, C109.2, C110.2, C111.2, C112.2, C113.2, C114.2, C115.2, C116.2, J101.2, J101.20, SW101.1, SW102.1, SW103.1, SW104.1, SW105.1, SW106.1, SW107.1, SW108.1, SW109.1, SW110.1, SW111.1, SW112.1, SW113.1, SW114.1, SW115.1, SW116.1
unnamed: R101.2, R105.2, SW101.2
unnamed: R102.2, R106.2, SW102.2
unnamed: R103.2, R107.2, SW103.2
unnamed: R104.2, R108.2, SW104.2
unnamed: R109.2, R113.2, SW105.2
unnamed: R110.2, R114.2, SW106.2
unnamed: R111.2, R115.2, SW107.2
unnamed: R112.2, R116.2, SW108.2
unnamed: R117.2, R121.2, SW109.2
unnamed: R118.2, R122.2, SW110.2
unnamed: R119.2, R123.2, SW111.2
unnamed: R120.2, R124.2, SW112.2
unnamed: R125.2, R129.2, SW113.2
unnamed: R126.2, R130.2, SW114.2
unnamed: R127.2, R131.2, SW115.2
unnamed: R128.2, R132.2, SW116.2



Board: 2 copper layers, 100.0 x 100.0 mm, 66 parts (49 on the bottom side), 34 nets.

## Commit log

2020-11-02 First commit, with some datasheets and a start of the remote PCB
    [CenterBoard.kicad_pcb, CenterBoard.sch, LPC51.sch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]
2020-11-06 Bezig met LEDS
    [CenterBoard.kicad_pcb, CenterBoard.sch, LEDs-screen.sch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]
2020-11-16 Continued work with the center board
    [CenterBoard.kicad_pcb, CenterBoard.sch, LPC51.sch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]
2020-11-18 Note: Schmitt trigger for joystick Buttons TODO
    [CenterBoard.kicad_pcb, LEDs-screen.sch, LPC51.sch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]
2020-11-20 Made the keyboard PCB. With LPC software started pin assignment on the LPC
    [CenterBoard.kicad_pcb, CenterBoard.sch, Keyboard.kicad_pcb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]
2020-12-09 Screen POT->PWM and RGB LEDS reworked, making space on the CPU pins. Almost done
    [CenterBoard.kicad_pcb, LEDs-screen.sch, LPC51 pinning.ods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]
2020-12-11 Finished leds, redid a lot of PCB wiring. Almost done there now.
    [CenterBoard.kicad_pcb, LEDs-screen.sch, LPC51 pinning.ods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]
2020-12-14 Centerboard v0.1 is done.
    [CenterBoard.kicad_pcb, LEDs-screen.sch, joysticks-throttle.sch]
2020-12-14 More finishing work on remote-centerboard. Copied in the Drone main board, did some cleaning up on that. Started work on more neat and clean lessons learned documents
    [1v2-power-regulator.sch, 3v3-2v5-regulator.sch, 5v-power-regulator.sch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]
2020-12-18 Redid the radio PCB layout on both drone and remote PCB. Drone PCB had old schematic, remote PCB layout wasn't ideal.
    Copied in the VHDL project files from the seperate VHDL project into the main "All in one" project.
    [CenterBoard.kicad_pcb, CenterBoard.sch, LEDs-screen.sch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]
2020-12-21 Some cleanup, and PCB antenna removal.
    Last edits before asking for reddit feedback.
    [5v-power-regulator.sch, CenterBoard.kicad_pcb, CenterBoard.sch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]
2020-12-24 Minor tweaks. Improved groundplane around FPGA core (removed and relocated a few power vias) and flipped clock circuit to the same side as the FPGA.
    [FPGA3.sch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]
2021-01-15 Added PDFs of schematics. Corrected a few value labels in drone schematic.
    [1v2-power-regulator.sch, CenterBoard.sch, FPGA-Power.sch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]
2021-03-01 Started to recheck components, and make a better BOM.
    [5v-power-regulator.sch]
2021-03-09 Lots of work to check every component, add Manufacturers number (instead of LCSC or digikey and mouser numbers)
    Changed to USB-C connector, almost done with that sheet. Components checked, need to redo Sheet IO
    [1v2-power-regulator.sch, 3v3-2v5-regulator.sch, 5v-power-regulator.sch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]
2021-03-16 Reworking and checking up to sensors page on main board. Added some datasheets to project
    [PCB-Drone-With-FPGA.kicad_pcb, Sensors.sch, USB-and-Memory.sch]
2021-03-18 Finished (?) the schematic check and update. Next: PCB update
    [FPGA-Power.sch, FPGA1.sch, FPGA2.sch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]
2021-03-18 Minor PCB work
    [PCB-Drone-With-FPGA.kicad_pcb, USB-and-Memory.sch]
2021-03-23 Finished redoing PCB.
    [PCB-Drone-With-FPGA.kicad_pcb, nRF24L01p-radio.sch]
